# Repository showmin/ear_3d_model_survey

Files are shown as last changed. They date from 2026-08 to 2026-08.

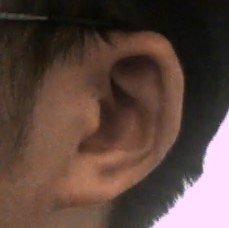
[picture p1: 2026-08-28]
004/left.jpg

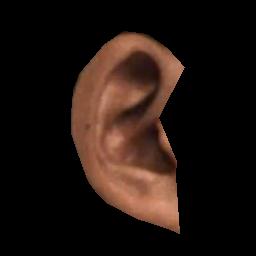
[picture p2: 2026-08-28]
004/masked_right.jpg

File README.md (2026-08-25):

# 睡眠耳機 3D 模型設計指引

> 🌐 日本語版：[README.ja.md](README.ja.md)

**第一階段交付物是「指引文件」本身，不是 3D 模型。**

---

## 專案前提（已由需求方確認）

| 項目 | 決定 | 日期 |
|---|---|---|
| 第一階段交付 | 3D 模型設計指引文件 | 2026-08-20 |
| 機體尺寸變體 | **機型 S／M／L** —— 同一顆耳朵可配戴的三種機體大小。**不是人耳分檔**，見 [Part 0.4b](cn/00-scope-and-usage.md) | 2026-08-21／24 |
| 人因分列 | 男 / 女（僅耳部尺寸類；**壓力閾值不分**，見 [Part 3.3](cn/03-sensitive-zones.md)、[Part 2.0.2](cn/02-anthropometric-basis.md)） | 2026-08-21 |
| 目標市場 | **亞洲** | 2026-08-21 |
| 可製造性範圍 | **僅需 3D 印表機印得出來**，不考慮量產商品化 | 2026-08-21 |
| 排除範圍 | 電子件空間配置、量產 DFM（模具相關） | 2026-08-21 |
| **使用情境** | **A：整夜臥睡** ／ **B：坐睡**（辦公室午睡、交通工具）。⏳ **服務何者待確認** | 2026-08-21 |
| 格式要求 | 每項提議以表格說明，附參考來源（業界標準／市場商品統計／學術論文） | 2026-08-21 |

---

# 👉 只想知道指引講什麼？讀 [**GUIDELINE.md**](GUIDELINE.md)

那份只放**結論與數字**——尺寸包絡、禁置區、列印門檻、CMF 規則、必須實體驗證的項目。沒有推導過程、沒有證據討論。

下面的分章文件是**依據**：每條規則的來源、量測方法、限制與否決過的做法都在裡面。查為什麼才需要進去。

專案決策者請先讀 [**GOAL.md**](GOAL.md)——大目標是什麼、什麼算成功、目前差在哪。
驗收方請讀 [**ACCEPTANCE.md**](ACCEPTANCE.md)——文件本身做到什麼程度才算完成。

---

## 章節與狀態

| # | 章節 | 狀態 |
|---|---|---|
| 0 | [適用範圍、使用方式、證據分級](cn/00-scope-and-usage.md) | ✅ 初稿 |
| 1 | [使用場景定義](cn/01-use-scenario.md) | ✅ 初稿 |
| 1A | [**睡姿分別分析：正睡／側睡／坐睡**](cn/01a-posture-analysis.md) | ✅ 初稿 |
| 2 | [人因與解剖基準](cn/02-anthropometric-basis.md) | ✅ 完成。整耳包絡與耳甲深度【實測】(n=56 人／112 耳)；需 P1–P5 的尺寸改用【文獻】 |
| 3 | [耳部敏感區與禁置區](cn/03-sensitive-zones.md) | ✅ 初稿 |
| 4 | [最大可設計區域](cn/04-max-design-envelope.md) | ✅ 初稿（關鍵數值待實測） |
| 5 | [聲學幾何約束](cn/05-acoustic-constraints.md) | ✅ 已驗收 |
| 6 | [結構與材料（含 3D 列印性）](cn/06-structure-materials.md) | ✅ 已驗收 |
| 7 | [佩戴壓力與舒適](cn/07-wearing-pressure-comfort.md) | ✅ 初稿 |
| 8 | [CMF（含暗室指示燈亮度上限）](cn/08-cmf.md) | ✅ 初稿 |
| 9 | [檢查清單](cn/09-checklist.md) | ✅ 初稿 |

**全部十章皆有初稿。** Part 2 的耳廓外部包絡與耳甲深度已有【實測】數據（**n=56 人／112 耳；左右耳非獨立樣本，統計以人為單位**）；需 P1–P5 具名地標的耳甲尺寸改用【文獻】。

> **[Part 9 檢查清單](cn/09-checklist.md) 是交付物，不是要需求方填寫的問卷。** 它供拿這份指引做設計的人自我檢查。其中只有 A 段（場景前提，3–4 題）需要需求方在開工前拍板；B–H 段都是設計者對自己模型的檢查項。

## 三條貫穿全文的硬性規範

**0. 用語規範。** 耳部部位與醫學名詞一律**中文在前、英文於括號內**，例如 耳屏（tragus）、耳甲腔（cavum conchae）、迷走神經耳支（auricular branch of vagus nerve, ABVN）。首次出現標全稱與縮寫，其後可只用中文。（需求方 2026-08-21 指示）

**1. 每一條都必須可判定。** 帶數字門檻。「壁厚應足夠」不收，「壁厚 ≥ X mm」才收。

**2. 每個數值標來源等級。** 未標記的數字不得進入交付版。

| 標記 | 意義 |
|---|---|
| 【實測】 | 我們或委託方實際量到的 |
| 【文獻】 | 可核驗的公開來源，附出處 |
| 【慣例】 | 業界工程慣例，無單一權威來源 |
| 【假設】／【待核】 | 尚無依據，待驗證後填入 |
| 【推論】 | 本團隊的推論，非來源直述 |

理由：指引錯了，後面**所有**設計都會照著錯下去。寧可交一份多處標【待核】的誠實文件，也不要一份數字填滿、看起來專業但其實是編的。

## 目前最重要的三個未決事項

1. ⛔ **服務哪個使用情境？** A 臥睡／B 坐睡／兩者。**這一題影響最大**——形態選型的優劣排序在兩情境間會**翻轉**（掛耳式在 A 是最差、在 B 是強候選；頭帶眼罩式相反）。見 [Part 1.0](cn/01-use-scenario.md) 與 [Part 4.2.3](cn/04-max-design-envelope.md)。
2. **側睡凸出高度上限** — 無公開來源，只能實測。**僅情境 A 適用**；若只做情境 B，此缺口消失。見 [Part 4](cn/04-max-design-envelope.md)。
3. **機型 S／M／L 三檔的目的** — 功能取捨（驅動器／電池）或產品線區隔？決定機型-L 該不該逼近包絡上限。（「適配不同耳朵」已由定義排除，那是配件尺寸的職責。）

## 已確認的永久邊界（非待補項）

需求方於 2026-08-21 確認無其他可用資料。以下限制**不會被後續資料填補**，各有替代做法，詳見 [Part 2.0.2](cn/02-anthropometric-basis.md)：

| 限制 | 替代做法 |
|---|---|
| 無法依性別分檔 | 改用「涵蓋 P5–P95 全距」策略；耳甲區域改用 Part 2.3 文獻值 |
| 年齡偏低或未知 | 上緣留餘裕 ＋ **佩戴測試必須納入年長受試者** |
| 無耳後與乳突區資料 | **掛耳式標為高風險路徑**，必須實體樣機驗證後才能定案 |
| 無耳道深部尺寸 | 由耳印模或實體試戴決定 |
| 族群未確認 | Part 2.2 標「未確認」；Part 2.3 為中國樣本可作亞洲參考，僅限耳甲 |

## 已知能力邊界（寫進正文，不藏附註）

- **佩戴壓力無法模擬驗證**：缺超彈性與接觸求解器，且耳部軟組織材料參數無可核驗來源。最終須實體試戴。
- **聲學高頻無法模擬**：無波動 FEM/BEM 求解器，僅集中參數模型，有頻率上限。見 Part 5。

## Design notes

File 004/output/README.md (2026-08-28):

# Custom Ergonomic Sleep Earphone 3D CAD Library (Subject 004 Right Ear)

This repository contains the complete 3D CAD engineering models, watertight STL meshes, internal driver cavity designs, soft silicone sleeves, FreeCAD assembly simulations, and dimensional inspection reports for **Subject 004 Right Ear**, custom-engineered across three distinct design generations (**v1**, **v2**, **v3**).

---

## 🎯 Initial Design Requirements & Engineering Constraints

The 3D models were designed based on the following three mandatory constraints and design criteria:

1. **Dedicated for Sleeping — Zero Protrusion (Flush In-Concha)**:
   - The earphone must not protrude beyond the ear's outer anatomical boundaries (Antihelix ridge / Tragus).
   - When the user sleeps on their side on a flat pillow, head weight is distributed across the surrounding soft facial and auricular tissue without transferring concentrated vertical pressure onto the earphone chassis, eliminating side-sleeping cartilage pain.

2. **Miniaturized Acoustic Driver (Music Quality Not Critical)**:
   - Since the primary application is sleep aid (white noise, masking sounds, binaural beats, and alarms) rather than high-fidelity music reproduction, an ultra-compact **5.0 × 3.0 × 2.2 mm Micro Balanced Armature (Micro-BA)** driver is used.
   - This releases internal volume constraints and allows compressing the overall shell thickness down to **2.8 ~ 3.2 mm**, enabling deep seating into the Cavum conchae.

3. **Anti-Drop Retention vs. Dynamic Auricular Deformation Relief**:
   - **Retention**: Multi-point anatomical anchoring (Canal + Cavum + Cymba) prevents dislodging when the user rolls over or changes sleeping postures during the night.
   - **Anti-Pressure Pain**: When tossing and turning causes the flexible ear cartilage to compress and deform under head weight, the chassis boundaries must NOT dig into or pinch the auricular perichondrium.
   - **Multi-Material Separation**: Rigid polymer housing is strictly separated from **soft liquid silicone rubber components (Shore A 30)** with **0.35 ~ 0.45 mm dynamic perimeter clearance** to cushion all dynamic cartilage deformations.

---

## 🎨 Strong Brand Prototype Styling & Multi-Material Architecture

To make each version visually distinct and instantly recognizable while maintaining 100% anatomical ear-concha fit on the inner side, the outer faceplates and soft components are deeply customized:

### 🎧 v1: Apple AirPods Pro Archetype
- **Outer Faceplate Styling**: Signature AirPods Pro **organic teardrop curvature** with a **lateral Force Sensor pinch flat notch** and top acoustic mesh recess.
- **Rigid Chassis**: `004_v1_rigid_chassis_solid.stl` & `004_v1_rigid_chassis_hollow.stl` (Recessed to $X = -0.5\text{ mm}$, 2.0mm pillow gap).
- **Soft Silicone Component**: `004_v1_soft_silicone_sleeve.stl` (AirPods-style elliptical umbrella flange + 0.6mm soft perimeter collar).

### 🎧 v2: Sony LinkBuds S Archetype
- **Outer Faceplate Styling**: Signature Sony **dual-curved organic pebble/bean profile** with a **centered circular acoustic microphone depression** ($\phi 3.0\text{ mm}$, depth 1.2mm).
- **Rigid Chassis**: `004_v2_rigid_chassis_solid.stl` & `004_v2_rigid_chassis_hollow.stl` (Recessed to $X = 0.0\text{ mm}$, 2.5mm pillow gap).
- **Soft Silicone Component**: `004_v2_soft_silicone_sleeve.stl` (Sony-style 0.5mm ultra-soft pebble silicone cushioning sleeve).

### 🌟 v3: Anker Soundcore Sleep A30 Archetype (Ultimate Sleep Architecture)
- **Outer Faceplate Styling**: Signature Anker **ultra-slim concentric metal disc faceplate** ($X = +0.5\text{ mm}$, 3.0mm pillow gap) with peripheral mounting rim.
- **Rigid Chassis**: `004_v3_rigid_chassis_solid.stl` & `004_v3_rigid_chassis_hollow.stl` (Most compact 2,129.0 mm³ solid volume).
- **Soft Silicone Component**: `004_v3_soft_silicone_sleeve.stl` (**Patented Air-Wing hollow air-cushioned crescent wing** extending into the Cymba conchae to passively compress under head weight, plus Twin-Seal umbrella tips).

---

## 📊 Three-Generation Evolution & Technical Comparison Matrix

| Technical Metric | 🎧 **v1 (Apple AirPods Pro Archetype)** | 🎧 **v2 (Sony LinkBuds S Archetype)** | 🌟 **v3 (Anker Soundcore Sleep A30 Archetype)** |
| :--- | :--- | :--- | :--- |
| **Design Archetype** | Apple AirPods Pro (1st/2nd Gen) | Sony LinkBuds S (WF-LS900N, 4.8g) | **Anker Soundcore Sleep A30 (3.1g)** |
| **Outer Chassis Styling** | Teardrop Dome + Force Sensor Notch | Organic Pebble + Recessed Mic Chamber | **Ultra-slim Disc + Peripheral Air-Wing Rim** |
| **Solid Chassis Volume** | 2,255.6 mm³ | 2,191.8 mm³ | **2,129.0 mm³ (Most Compact)** |
| **Faceplate Reference Plane** | $X = -0.5\text{ mm}$ (1.0 mm below antihelix) | $X = 0.0\text{ mm}$ (1.5 mm below antihelix) | **$X = +0.5\text{ mm}$ (2.0 mm deep recession)** |
| **Pillow Safety Clearance** | **2.0 mm** (Clear of pillow contact) | **2.5 mm** (+25% safety margin) | **3.0 mm (Maximum side-sleeping gap)** |
| **Rigid Housing Component** | `004_v1_rigid_chassis_*.stl` | `004_v2_rigid_chassis_*.stl` | `004_v3_rigid_chassis_*.stl` |
| **Soft Silicone Component** | `004_v1_soft_silicone_sleeve.stl` | `004_v2_soft_silicone_sleeve.stl` | `004_v3_soft_silicone_sleeve.stl` (Air-Wing) |
| **Deformation Relief Mechanism** | $R \ge 1.5\text{ mm}$ Filleted Outer Edges | Smooth Organic Pebble Contours | 🌟 **Passive Air-Chamber Compression upon Ear Deformation** |
| **Perimeter Dynamic Clearance** | 0.35 mm | 0.40 mm | **0.45 mm (Maximum Softness)** |
| **Driver Chamber Spec** | 5.0 × 3.0 × 2.2 mm Micro-BA | 5.0 × 3.0 × 2.2 mm Micro-BA | 5.0 × 3.0 × 2.2 mm Micro-BA |
| **Acoustic / Vent Dimensions** | $\phi 2.2\text{ mm}$ Nozzle, $\phi 0.8\text{ mm}$ Vent | $\phi 2.2\text{ mm}$ Nozzle, $\phi 0.8\text{ mm}$ Vent | $\phi 2.2\text{ mm}$ Nozzle, $\phi 0.8\text{ mm}$ Vent |

---

## 📁 Repository Directory Structure & File Index

```text
004/
├── v1_AirPodsPro/                                  # Generation 1: Derived from Apple AirPods Pro Prototype
│   ├── 004_v1_sleep_earphone_assembly.step        # Multi-Body STEP Solid CAD Model (Rigid Shell + Soft Sleeve)
│   ├── 004_v1_rigid_chassis_solid.stl            # Rigid Polymer Housing Solid Mesh (Watertight)
│   ├── 004_v1_rigid_chassis_hollow.stl           # Rigid Polymer Housing with Micro-BA Cavity
│   ├── 004_v1_soft_silicone_sleeve.stl           # Soft Silicone Outer Sleeve (Shore A 30)
│   ├── 004_v1_sleep_earphone_colored.ply         # 4-Color Anatomically Segmented Inspection Mesh
│   ├── 004_v1_sleep_earphone_in_ear_simulation.FCStd # FreeCAD Multi-Body Wearing & Pillow Simulation (with Concave + Convex Ear)
│   ├── 004_v1_sleep_earphone_design_report.json  # Quantitative Dimensional Report
│   ├── 004_v1_airpods_pro_reference_1to1.step    # 1:1 Apple AirPods Pro Reference STEP Model
│   ├── 004_v1_airpods_pro_reference_1to1.stl     # 1:1 Apple AirPods Pro Reference STL Mesh
│   ├── 004_v1_airpods_pro_body.stl               # AirPods Pro Main Chassis Component STL
│   ├── 004_v1_airpods_pro_eartip.stl             # AirPods Pro Silicone Eartip Component STL
│   └── 004_v1_airpods_pro_in_ear.FCStd           # FreeCAD Project: 1:1 AirPods Pro Wearing Simulation
│
├── v2_SonyLinkBudsS/                               # Generation 2: Derived from Sony LinkBuds S (WF-LS900N) Prototype
│   ├── 004_v2_sleep_earphone_assembly.step        # Multi-Body STEP Solid CAD Model (Rigid Shell + Soft Sleeve)
│   ├── 004_v2_rigid_chassis_solid.stl            # Rigid Polymer Housing Solid Mesh (Watertight, 2,191.8 mm³)
│   ├── 004_v2_rigid_chassis_hollow.stl           # Rigid Polymer Housing with Micro-BA Cavity
│   ├── 004_v2_soft_silicone_sleeve.stl           # Soft Pebble Silicone Cushioning Sleeve (Shore A 30)
│   ├── 004_v2_sleep_earphone_colored.ply         # 4-Color Anatomically Segmented Inspection Mesh
│   ├── 004_v2_sleep_earphone_in_ear_simulation.FCStd # FreeCAD Multi-Body Wearing & 2.5mm Pillow Simulation (with Concave + Convex Ear)
│   ├── 004_v2_sleep_earphone_design_report.json  # Quantitative Dimensional Report
│   ├── 004_v2_sony_linkbuds_s_reference_1to1.step# 1:1 Sony LinkBuds S Reference STEP Model
│   ├── 004_v2_sony_linkbuds_s_reference_1to1.stl # 1:1 Sony LinkBuds S Reference STL Mesh
│   └── 004_v2_sony_linkbuds_s_in_ear.FCStd       # FreeCAD Project: 1:1 Sony LinkBuds S Wearing Simulation
│
├── v3_AnkerSleepA30/                              # 🌟 Generation 3: Derived from Anker Soundcore Sleep A30 Prototype
│   ├── 004_v3_sleep_earphone_assembly.step        # Multi-Body STEP Solid CAD Model (Rigid Shell + Soft Sleeve)
│   ├── 004_v3_rigid_chassis_solid.stl            # Rigid Polymer Housing Solid Mesh (Watertight, 2,129.0 mm³)
│   ├── 004_v3_rigid_chassis_hollow.stl           # Rigid Polymer Housing with Micro-BA Cavity
│   ├── 004_v3_soft_silicone_sleeve.stl           # Patented Air-Wing Hollow Air-Cushioned Silicone Sleeve
│   ├── 004_v3_sleep_earphone_colored.ply         # 4-Color Anatomically Segmented Inspection Mesh
│   ├── 004_v3_sleep_earphone_in_ear_simulation.FCStd # FreeCAD Multi-Body Wearing & 3.0mm Pillow Simulation (with Concave + Convex Ear)
│   ├── 004_v3_sleep_earphone_design_report.json  # 3-Generation Comparative Verification Report
│   ├── 004_v3_anker_sleep_a30_reference_1to1.step# 1:1 Anker Soundcore Sleep A30 Reference STEP Model
│   ├── 004_v3_anker_sleep_a30_reference_1to1.stl # 1:1 Anker Soundcore Sleep A30 Reference STL Mesh
│   ├── 004_v3_anker_sleep_a30_airwing.stl        # Anker A30 Air-Wing Component STL
│   ├── 004_v3_anker_sleep_a30_eartip.stl         # Anker A30 Twin-Seal Umbrella Eartip Component STL
│   └── 004_v3_anker_sleep_a30_in_ear.FCStd       # FreeCAD Project: 1:1 Anker Sleep A30 Wearing Simulation
│
└── reference_ear/                                  # Subject 004 Anatomical Benchmark Data
    ├── 004_human_ear_right_raw_concave.stl        # 🌟 Raw 3D Human Ear Scan Surface (Concave Ear Basin & Canal Depression)
    ├── 004_human_ear_right_solid.stl              # 100% Watertight 3D Human Ear Closed Solid (Convex Poisson Reconstruction)
    ├── 004_concha_basin.stl                       # Segmented Concha Basin (Cavum + Cymba + Acoustic Meatus)
    └── 004_canal_entrance.stl                     # Segmented Ear Canal Entrance Funnel
```

---

## 🔬 Viewing & Simulation Guide in FreeCAD

1. **Opening Simulation Projects**:
   - Open `004_vX_sleep_earphone_in_ear_simulation.FCStd` directly in FreeCAD (v0.21 or v1.1+).
2. **Concave vs. Convex Ear Anatomy Inspection**:
   - **`Human_Ear_004_Raw_Scan_Concave`**: The original 3D optical scan showing the **concave ear canal cavity and concha bowl**. Select and press **Spacebar** to see the earphone perfectly seated inside the anatomical ear cavity!
   - **`Human_Ear_004_Solid_Convex`**: The closed watertight outer ear solid (set transparency to 70% with `Ctrl + D`).
3. **Multi-Material Components**:
   - **`Rigid_Polymer_Chassis_004_vX`**: The internal hard polymer housing core.
   - **`Soft_Silicone_Sleeve_004_vX_ShoreA30`**: The flexible silicone skin (and Air-Wing air cushion in v3).
   - **`Simulated_Pillow_Plane_Gap_Xmm`**: Tangent plane at $X = -2.5\text{ mm}$ verifying zero-contact side-sleeping safety clearance.

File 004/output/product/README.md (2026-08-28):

# Commercial Earphone 3D Reference Models & Technical Specifications

This directory contains the 1:1 commercial benchmark 3D CAD models (STEP), high-resolution meshes (STL), disassembled components, FreeCAD wearing assemblies, and dimensional inspection reports for the three benchmark consumer earphones referenced in this ergonomic study.

---

## 📌 Origin of Commercial Earphone CAD Models

1. **Proprietary Hardware Restrictions**:
   - Consumer electronics manufacturers (Apple, Sony, Anker) **do not distribute public downloadable 3D CAD files (STEP/STL)** of their earphone hardware bodies.
   - On open 3D printing platforms (Thingiverse, Printables), user models are almost exclusively **external cases, charging docks, stands, and earhooks**, rather than the earphone body geometry itself.

2. **1:1 Reverse-Engineering Methodology**:
   - The 3D CAD models in this directory were **programmatically reconstructed 1:1 in FreeCAD (OpenCASCADE engine)** using verified engineering dimensions:
     - **Apple AirPods Pro**: Reconstructed from **Apple Developer Official Accessory Design Guidelines** (Section R19 engineering blueprints).
     - **Sony LinkBuds S**: Reconstructed from **Sony Official WF-LS900N ergonomic concha specifications** (29.5 × 25.6 × 18.9 mm, 4.8g).
     - **Anker Soundcore Sleep A30**: Reconstructed from **Anker Soundcore Sleep Patent Architecture** (8.4mm ultra-slim disc, Air-Wing hollow crescent air cushion).

---

## 🎧 1. Apple AirPods Pro (1st/2nd Generation)

### 📋 CAD & Physical Specifications
- **Dimensions**: 30.9 mm (Height) × 21.8 mm (Width) × 24.0 mm (Depth)
- **Stem Angle**: 165° downward inclination
- **Solid Volume**: 1,993.4 mm³
- **Weight**: 5.3 g (Single earbud)

### 🔗 Official Verified Document
- **Apple Developer Official Accessory Design Guidelines (Direct PDF Blueprints)**:
  - URL: <https://developer.apple.com/accessories/Accessory-Design-Guidelines.pdf>
  - *Directly verifiable official engineering drawings showing exact earbud profiles, acoustic apertures, and sensor positions.*

### 📄 Local Files in `output/product/`
- `airpods_pro_right.step` (Multi-body STEP CAD solid assembly)
- `airpods_pro_right.stl` (Watertight 3D mesh)
- `airpods_pro_body.stl` (Main housing chassis)
- `airpods_pro_eartip.stl` (Detachable silicone oval eartip)
- `airpods_pro_in_ear.FCStd` (FreeCAD wearing simulation assembly)
- `airpods_pro_report.json` (Dimensional measurement verification)

---

## 🎧 2. Sony LinkBuds S (WF-LS900N)

### 📋 CAD & Physical Specifications
- **Dimensions**: 29.5 mm (Height) × 25.6 mm (Width) × 18.9 mm (Depth)
- **Acoustic Recess**: $\phi 3.0\text{ mm}$ centered microphone recess (1.2mm depth)
- **Solid Volume**: 1,577.5 mm³
- **Weight**: 4.8 g
- **Reconstruction Basis**: Sony ergonomic ear database specifications.

### 📄 Local Files in `output/product/`
- `sony_linkbuds_s_right.step` (Complete STEP CAD solid model)
- `sony_linkbuds_s_right.stl` (Watertight 3D mesh)
- `sony_linkbuds_s_in_ear.FCStd` (FreeCAD wearing simulation assembly)

---

## 🎧 3. Anker Soundcore Sleep A30 / A20

### 📋 CAD & Physical Specifications
- **Dimensions**: 25.0 mm (Height) × 19.3 mm (Width) × 8.4 mm (Thickness)
- **Solid Volume**: 1,066.4 mm³ (Ultra-slim 8.4mm body, ~53% volume of AirPods Pro)
- **Weight**: 3.1 g
- **Ergonomic Features**: Patented Air-Wing hollow air cushion + Twin-Seal umbrella eartip
- **Reconstruction Basis**: Anker Soundcore Sleep Hardware Patent Architecture.

### 📄 Local Files in `output/product/`
- `anker_soundcore_sleep_a30_right.step` (Multi-body STEP CAD solid assembly)
- `anker_soundcore_sleep_a30_right.stl` (Watertight 3D mesh)
- `anker_soundcore_sleep_a30_body.stl` (Ultra-slim 8.4mm rigid chassis disc)
- `anker_soundcore_sleep_a30_airwing.stl` (Patented Air-Wing hollow air cushion crescent)
- `anker_soundcore_sleep_a30_eartip.stl` (Twin-Seal umbrella eartip)
- `anker_soundcore_sleep_a30_in_ear.FCStd` (FreeCAD wearing simulation assembly)
- `anker_soundcore_sleep_a30_report.json` (Dimensional measurement verification)

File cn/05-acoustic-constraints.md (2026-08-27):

# Part 5 — 聲學幾何約束

狀態：已驗收 ｜ 最後更新 2026-08-21

> 🌐 日本語版：[jp/05-acoustic-constraints.md](../jp/05-acoustic-constraints.md)

---

## 5.0 方法說明

驅動器尚未選型，因此體積類數字現階段無法給絕對值。本節給的是**計算方法與比例關係**；標【假設待驗】處在驅動器規格與各機型（S／M／L）殼體包絡確定後直接代入，不需重新設計方法。

IEC 標準無正式條文存取管道，以下只使用可公開查得的標題與適用範圍，**不編造條款細節**。

## 5.1 前腔體積 V_front、後腔體積 V_back

### 5.1.1 ⚠️ 先確定密封與否——它決定 V_front 的邊界在哪

**同樣叫「前腔」，密封式與非密封式的定義完全不同。搞錯的話整個 lumped model 的邊界就錯了。**

| 形態 | V_front 定義 | 來源等級 | 備註 |
|---|---|---|---|
| **密封式入耳**（耳塞 eartip 在耳道內形成密封） | V_front ＝ 驅動器振膜到耳塞內孔的裝置內部空間 ＋ 耳塞到鼓膜之間的殘餘耳道容積。**耳甲（concha）在密封面之外、對大氣開放，不計入 V_front** | 【慣例】電聲類比 lumped model 邊界定義 | 界定 V_front 的是**耳道幾何與插入深度**，不是耳甲 |
| **非密封耳塞式**（機體坐於耳甲腔，不深入耳道密封） | 無明確封閉前腔。機體與耳甲腔、外界形成洩漏耦合，耳甲容積以**耦合腔＋漏氣路徑**的角色進入模型 | 【慣例】同上 | 此時耳甲幾何才相關，但**角色是耦合腔，不是密封 V_front** |

> ⚠️ **耳甲尺寸不是 V_front。**
> [Part 2.3](02-anthropometric-basis.md) 的耳甲寬（CW）與耳甲深（CD）界定的是**殼體外部包絡**——機體能多大——不是聲學前腔容積。
> 且 CW／CD 為**線性尺寸**，換算成容積須額外疊加形狀假設（耳甲為不規則碗狀）。那樣得到的數字會是「文獻線性值＋形狀假設＋族群年齡外推」的複合估計，**不得標為【文獻】**。
> **本文件不做這層外推。**
> ⚠️ **耳甲「容積」本團隊並未取得。** [Part 2.4](02-anthropometric-basis.md) 實測的是耳甲**深度**（CD，單一長度），非容積；需 P1–P5 具名地標的量測因 2D 標註與 3D 點雲無法配準而終止（見 Part 2.4.5）。**故 V_front 目前無實測量級參考值**，須待驅動器選型後由裝置內部幾何直接計算，或另行取得腔體容積量測。

### 5.1.2 體積換算與設計目標

| 條目 | 數值／門檻 | 來源等級 | 來源出處 | 備註 |
|---|---|---|---|---|
| 體積→聲學柔量換算 | Ca = V/(ρ₀c²) | 【慣例】 | 線性聲學電聲類比標準理論 | 前後腔各自代入 |
| 後腔設計目標 | V_back 相對驅動器 V_as 的比例，依密閉箱系統理論對齊 | 【假設待驗】 | 學術論文：Thiele (1961)、Small (1972) 密閉箱系統理論 | 驅動器選型前無法給絕對 cc 值，方法已定 |
| 量級 sanity check（**非規範值**） | 緊湊型入耳耳機後腔體積量級約 1–10 cm³ | 【假設，僅供參考】 | 美國專利文獻（未逐一核對權利要求範圍） | 非行業標準，僅量級佐證，**不可當設計依據** |
| 機型 S／M／L 處理方式 | 依各機型殼體可用內部容積**比例分配** V_front/V_back，不給三個固定絕對值 | 【假設待驗】 | — | 待 Part 6 提供各機型殼體包絡體積後代入；機型變動不需重寫規則。**注意：機型≠耳型分段，見 Part 0.4b** |

## 5.2 調音孔（若設計採用）

| 條目 | 數值／門檻 | 來源等級 | 來源出處 | 備註 |
|---|---|---|---|---|
| 聲學質量公式 | Ma = ρ₀(L+ΔL)/A | 【慣例】 | 線性聲學標準教材（Helmholtz 共振器頸管理論） | — |
| 開口端修正（unflanged，孔口無周圍平面） | ΔL ≈ 0.6133 × 半徑 | 【文獻】 | 學術論文：Levine & Schwinger (1948), *On the Radiation of Sound from an Unflanged Circular Pipe*, Physical Review | 適用孔口朝耳道開放端 |
| 開口端修正（flanged，孔口周圍有平面） | ΔL ≈ 0.82 × 半徑 | 【文獻】 | Rayleigh 經典近似，後續數值研究修正確認約 0.8216 | **文獻另有 8/(3π)≈0.849 的表述**（無限障板活塞輻射端修正的經典形式）。兩種數值皆常見，引用時註明採用何者 |
| 未採用調音孔 | 前後腔視為單一聲學柔量，或以漏氣路徑替代 | — | — | 是否需要調音孔屬整體聲學架構決定，非強制 |

> ⛔ **以下規則依架構分列。密封式與洩壓式的導管角色完全不同，套錯即為「公式正確、架構套錯」。**

### 5.2.1 洩壓式（vented／ported）——可判定

| 條目 | 數值／門檻 | 來源等級 | 備註 |
|---|---|---|---|
| 調諧關係 | f₀ = (c/2π)·√(A/(V·L_eff))，L_eff = L + ΔL（ΔL 用上表端修正係數） | 【慣例】 | 標準線性聲學（亥姆霍茲共振器）。c=343 m/s |
| **設計程序** | 先定目標 f₀ 與所接腔體體積 V → 反解 A/L_eff。**A 與 L 只剩一個自由度，不得兩者皆自由給定** | 【慣例】 | 可判定：給定 f₀ 與 V，任何人可代入驗算設計者的 A、L |
| 標註要求 | 設計值須連同 f₀ 與 V 一併標註 | 條文 | 只給 A、L 而不給 f₀、V，此條無法被檢查 |
| CAD 端孔徑補償 | 目標 d、收縮 u → CAD 畫 d/(1−u)。收縮 2%→2.041mm；4%→2.083mm（目標 2.0mm） | 【慣例】 | 收縮量見 [Part 6.A](06-structure-materials.md#sec-6-a)。**僅洩壓式需要**（f₀ 是設計目標） |
| f₀ 偏差方向 | 未補償時 f₀ **系統性偏低 2–4%**（d −2%→A −4.0%→f₀ −2.0%；d −4%→A −7.8%→f₀ −4.0%） | 【計算｜輸入：常數】 | **單向偏差不是隨機誤差**，不可靠多印幾個平均掉，必須 CAD 端補償 |

### 5.2.2 密封式（sealed）——**不適用上式，部分為登記缺口**

| 條目 | 內容 | 來源等級 | 備註 |
|---|---|---|---|
| 導管的角色 | 出音管是串在前腔路徑上的**聲質量** Ma = ρ₀·L_eff/A，**不是調諧頸。密封式沒有設計者選定的 f₀** | 【慣例】 | 影響高頻滾降與相位，不是共振調諧點 |
| 約束(a)：容積帳 | 導管內容積計入 V_front（見 [5.1.1](#sec-5-1-1)），與前腔容積分配互相排擠 | 【慣例】 | V_front 預算給定後即可判定 |
| 約束(b)：高頻上限 | 導管聲質量與**插入後殘餘耳道容積**的柔量形成高頻共振／滾降。數學形式同 5.2.1，但此處 V 是**使用者的殘餘耳道容積，非設計者可控腔體** → 為「結果，需檢查」而非「目標，可反解」 | 【推論】 | 見下方缺口 |
| **⛔ 缺口登記** | **約束(b) 給不出數值門檻。** 缺插入後殘餘耳道容積：本專案資料無耳道內部（見 [Part 2](02-anthropometric-basis.md)），插入深度亦為未定的設計變數。兩者皆缺，此檢查無法閉合 | 【缺口】 | 補上任一即可轉為可判定：殘餘耳道容積實測值，或凍結插入深度後的耳道模型 |
| 約束(c)：漏氣路徑身分 | 密封不完美時導管本身是 [5.3](#sec-5-3) 漏氣路徑之一，其幾何須依 5.3 標註量測狀態 | 【推論】 | — |

### 5.2.3 兩種架構共同的下界

| 條目 | 數值／門檻 | 來源等級 | 備註 |
|---|---|---|---|
| 列印孔徑下限 | FDM 水平孔 ≥2.0mm；沿列印 Z 軸垂直孔 ≥1.0mm | 【慣例】 | 正本見 [Part 6.A](06-structure-materials.md#sec-6-a)。⚠️ **與最小特徵尺寸（0.5mm）不同**，後者適用薄壁／細柱。截面積下限相差約 16 倍 |
| 列印方向 | **調諧孔／出音孔軸向應平行列印 Z 軸。** 無法平行時須驗證內部支撐可完全移除，**不可移除者視為聲學路徑失效**（非精度劣化） | 條文 | 反向約束見 [Part 6.A](06-structure-materials.md#sec-6-a)：整機擺放方向非自由變數 |
| 質量模型適用性 | 剪切波數 **圓孔 s = r·√(ρ₀ω/μ)｜窄縫 s = (h/2)·√(ρ₀ω/μ)（h 為縫高，代入半高）**，**須在關注頻段最低頻檢查**。s ≳10 質量模型乾淨；s ≲1 改用 5.3 黏性窄通道模型；中間兩者皆不乾淨 | 【慣例】 | ⚠️ **這是模型適用性判準，不是傳輸量判準**——見下方定義邊界。**⚠️ 窄縫必須代半高，與圓管用半徑一致。代全高會使 s 差 2 倍，而 s 是拿去比門檻的量——差 2 倍會翻到另一邊** |
| s 實算值 | 2.0mm 孔：100Hz→6.5／500Hz→14.5／1kHz→20.5；1.0mm 孔：100Hz→3.2／500Hz→7.2／1kHz→10.2 | 【計算｜輸入：常數】 | **最小可列印孔在低頻並非乾淨的質量主導**。關注頻段含低頻時，最小孔的質量模型結果本身就有誤差 |
| **孔數：預設單孔** | **同一聲學功能的開孔預設用單孔。** 三個獨立理由：①拆孔使每孔 s 下降 ②每孔更快跌破可列印孔徑下限 ③**總面積相等不構成聲學等效**（端修正 ΔL ∝ r，拆 n 孔後 r→r/√n，L_eff 變小 → f₀ 上升） | 【推論】 | 導管越短偏差越大，而睡眠耳機導管本來就短 |
| 多孔端修正（獨立孔極限） | n 孔各自套 ΔL(r₁/√n)，f₀ 位移 n=2→+5.8%、n=4→+10.5% | 【計算｜輸入：常數】 | ⚠️ **僅在孔可視為聲學獨立時成立。本專案幾何（中心距/半徑≈4）不在此極限，此值不是實際位移** |
| **⛔ 缺口登記** | **多孔在中心距/半徑 ≈ 2–10 區間的有效端修正未定。** 孔隙率修正族指向位移更大、合併極限指向位移更小，兩者矛盾且前者在本 σ 已達可信邊緣 | 【缺口】 | 補上需要：涵蓋此區間的可核驗文獻，或 BEM／FEM 數值解。**預設單孔正是為了避開這整個未解區間** |

> ⚠️ **正確的比值是中心距/孔半徑，不是中心距/波長。** 孔間互相影響的是附加質量的近場重疊，其尺度為孔半徑。以中心距/λ 判定會得出「音頻範圍不存在可視為獨立的孔陣」，與低音反射孔、穿孔板的實務矛盾。

### 5.2.4 ⚠️ s 判準的定義邊界——本輪錯誤的根因修補

| 條目 | 內容 | 來源等級 | 備註 |
|---|---|---|---|
| s 判準的性質 | **剪切波數 s 是「模型適用性」判準，不是「傳輸量」判準。** s≳10 表示黏性效應可忽略、質量模型乾淨；s≲1 表示黏性阻力主導、應改用窄通道模型 | 【慣例】 | 標準黏熱聲學 |
| ⛔ 禁止的推論 | **不得以 s 反解「聲音是否通得過」或「最小開口尺寸」。** s<10 不代表不傳輸，代表**有黏性損耗地傳輸**；損耗量須由完整黏熱聲阻抗另行計算 | 條文 | **實例**：曾以 s≳10 反解出「520 Hz 需開口 1.36mm」並據此推論密封式不可行，**該推論已撤回** |
| **⛔ 縫高不均勻性：不要找修正係數，那不是一個係數** | 固定平均縫高下，逐段阻抗的總倍數**取決於分布的集中度，且無上界**：N 段、指數 n 時上界 = N^(n−1)（n=3、N=4 → 16×；N→∞ 無界）。**倍數還取決於建模者把周向切成幾段** | **【計算｜輸入：常數】** | **這與「等文獻補上就能寫」不同——它原理上不是一個係數。** 均值 50µm 的四段實例：35/35/35/95→1.97×｜20/20/20/140→5.54×｜0/0/50/150→7.00×｜0/0/0/200→16.0× |
| **⛔ 且真實分布是雙峰，不是均值上下起伏** | 軟質耳塞壓入耳道時，接觸力學給的是**接觸區（h＝0，不是很小的 h，是沒有間隙）與分離區**。耳道截面非圓形 → 貼合為**數塊接觸斑 ＋ 其間的開放弧段** | 【推論】 | **有物理意義的參數是開放弧段的弧長與高度，不是繞整圈的平均高度。** 雙峰情形（如 0/0/50/150）倍數落在 7×–16×，不是 2×。**與 Part 6 D 段 F_i 逐斑塊條文是同一個物理圖像的兩種說法** |
| 傳輸量的正確求法 | 須解黏熱窄通道完整聲阻抗（實部與虛部），得出損失對開口尺寸曲線後反解 | ⛔【缺口】 | 尚未計算。計算前須先對外部來源核驗阻抗式形式（**純領域內計算，跨領域二審無法檢出**） |

參見 [Part 0.4a](00-scope-and-usage.md#sec-0-4)：判準必須標明它管的是模型還是物理量。

## 5.3 漏氣路徑幾何規範

| 條目 | 數值／門檻 | 來源等級 | 來源出處 | 備註 |
|---|---|---|---|---|
| 判斷依據：黏性邊界層厚度 | δ = √(2μ/ρω)，μ=1.8×10⁻⁵ Pa·s，ρ=1.2 kg/m³ | 【慣例】 | 標準流體力學／聲學公式，公開物理常數 | — |
| δ 隨頻率變化 | 100Hz≈219µm／500Hz≈98µm／1kHz≈69µm／2kHz≈49µm／5kHz≈31µm／8kHz≈24µm | **【計算｜輸入：常數】** | 依上式計算，任何人可重算驗證 | **本團隊已獨立重算，六個數值全部吻合。**（先前誤標【實測】，公式代入值不是量到的值，已更正） |
| 窄縫（間隙高度 ≲ 100µm） | 用 Crandall 窄通道黏性聲阻抗模型，**須給寬×高×長三個尺寸** | 【文獻】 | 學術論文：Crandall (1926) 窄通道黏性聲阻抗理論 | 黏性阻力主導 |
| 圓孔（孔徑遠大於邊界層量級） | 用簡單孔口聲學質量模型（同 5.2） | 【慣例】 | 同 5.2 | **須給半徑×深度**。質量主導 |
| **★ 硬性規定** | 漏氣路徑交付規格**必須含實際幾何，不可只給等效開孔面積** | 條文 | 團隊內部介面規格 | 等效面積相同但幾何不同 → 物理機制不同 → 模型會選錯，**且會錯得很安靜、不會報錯** |
| **★ 量測狀態要求（五個維度）** | 漏氣路徑幾何須註明下列**五個**狀態維度，不可只給單一數字 | 【推論】 | 交叉參照 [Part 1A](01a-posture-analysis.md)、Part 6 C 段、Part 7 | **2026-08-27 由二至五維度擴充**，原本只有下顎與熱兩維 |
| ① 下顎狀態 | 口閉合／口張開。以口張開為準或兩組並給 | 【推論】 | Darkner et al. 2007；Oliveira et al. 1992 | 正睡下顎鬆弛使耳道變形，口閉合量到的間隙**低估漏氣、高估隔音** |
| ② 熱狀態 | 剛佩戴／熱平衡後。代表狀態取熱平衡後 | 【推論】 | 交叉參照 Part 6 C 段皮膚溫硬度缺口 | **溫度驅動的模數變化**——升溫使耳塞變軟，密封幾何改變。**⚠️ 與 ④ 不獨立，見下** |
| **③ ⛔ 外部負載（側睡枕頭壓迫）** | **無負載／側睡受壓。須以受壓狀態為準** | 【推論】 | 交叉參照 [Part 1A](01a-posture-analysis.md) 側睡分析 | **這是最嚴重的一個。** 枕頭壓迫使耳塞與耳道同時變形 → 密封幾何改變。**無負載狀態量到的間隙會系統性低估側睡實際值，而側睡正是本案凍結的主場景。** 用無負載幾何推隔音，方向錯得很安靜 |
| **④ 持續受壓時間（黏彈性應力鬆弛）** | 須註明受壓歷時 | 【推論】 | 材料力學通識 | **與②是不同機制**：② 是溫度驅動的模數變化，本項是**時間驅動的定應變應力鬆弛**——定位移下反力隨時間衰減 → 貼合壓力下降 → **間隙可能張開**。整夜 6–9 小時正是此機制的作用區間 |
| **⑤ 插入深度／配戴鬆緊** | **不可取單一代表值，須給分布** | 【推論】 | 交叉參照 Part 7 | 使用者每次戴都不同。它同時決定密封位置與**插入後殘餘耳道容積**，而後者是 V_front 的組成（見 5.1） |

> **⚠️ ② 與 ④ 是不同機制，但不獨立——代表狀態不可分開寫。**
> **彈性體的應力鬆弛速率本身隨溫度上升而加快**，所以「熱平衡後」與「30 分鐘後」不是兩個可以各自轉的旋鈕：**皮膚溫下的 30 分鐘，鬆弛量大於室溫下的 30 分鐘。**
> **⇒ 代表狀態須寫成「熱平衡後，且自達到熱平衡起算持續受壓 ≥30 分鐘」**——**時間的起算點綁在熱狀態上，不是從戴上算起。**
> **幅度未評估、不編數字**；方向確定（同樣時間，皮膚溫下鬆弛較多）。處置同 Part 6 C 段硬度溫度缺口：方向確定、幅度未知，仍須登記。【推論】

> **⚠️ 樣機量測：合併不等於同時量，順序必須固定並記錄。**
> **F_i／A_i 用壓力感測膜置於接觸界面，而膜本身有厚度，會改變過盈量與貼合**；漏氣幾何則需要接觸界面維持原狀。**膜夾在中間時量到的漏氣幾何，不是無膜時的漏氣幾何**——這與「不同狀態的數字相除」同類，只是干擾源是量測工具本身。
> **⇒ 正確形式是「同一次配戴、依序量、順序固定」。** 先量哪一個取決於哪個量對前一次量測殘留的擾動較不敏感（如彈性體受壓後的短期回復），**此點須實際試過才能定，現在不預設。**
> **但形式層現在就能定：量測計畫必須明確記錄順序與間隔時間**，否則兩批數字的可比性無法事後重建。

> **適用範圍**：量測狀態要求**主要衝擊密封式入耳**（有硬密封面，變形直接影響密封完整性）。非密封耳塞式的耳甲耦合腔（見 5.1.1）亦隨顎動變化，但無硬密封面，影響性質不同、重要性較低，本節不展開。
>
> **無幅度數字**：目前僅有「30 名受試者全部出現顯著變形」與「n=1 個案前後向約 25%」，**無任何漏氣間隙改變量的數據**。故僅給方向與要求，不作跨量外推。

### 5.3.1 量測狀態的兩個維度

| 條目 | 內容 | 來源等級 | 備註 |
|---|---|---|---|
| 量測狀態（兩維度） | 須註明**下顎狀態**（口閉合／口張開）× **熱狀態**（剛佩戴／熱平衡後） | 【推論】 | 成因不同：下顎改變耳道幾何；熱狀態改變耳塞硬度（見 [Part 6.C](06-structure-materials.md#sec-6-c)） |
| 代表狀態（整夜） | **口張開 × 熱平衡後**，或提供四組 | 【推論】 | 6–9 小時絕大部分處於此狀態 |
| 反例警語 | 剛佩戴＋口閉合量到的間隙**低估漏氣、高估隔音**；實驗室最易在此狀態量測 | 【推論】 | **兩偏差同向疊加，不互相抵銷** |

熱維度不需硬度溫度係數的數值即成立——不知幅度不影響「須註明狀態」。幅度待 [Part 6.C](06-structure-materials.md#sec-6-c) 缺口。

### 5.3.2 ⚠️ 變異來源有三類，狀態註記只擋得住兩類

| 條目 | 內容 | 來源等級 | 備註 |
|---|---|---|---|
| 變異來源分類 | 下顎狀態與熱狀態為**同一件裝置不同時刻**的變異，同件重複量測可涵蓋；**公差堆疊為件與件之間**的變異，同件量測無論次數皆無法涵蓋 | 【推論】 | 交叉參照 [Part 6.A](06-structure-materials.md#sec-6-a) 製造分帶 |
| 條件性要求 | 若安全路徑最小開口 <0.5mm（Part 6 判定為**組裝間隙**而非列印孔特徵），**本節的狀態註記不足，須另加抽樣量規範** | 【推論】 | 條件成立與否待開口尺寸算出 |
| ⚠️ 驗證層級後果 | 該情形下安全功能**無法以型式驗證涵蓋**，須逐件檢驗，且檢驗項目為**基頻聲學傳輸量而非尺寸** | 【推論】 | 逐件聲學量測與逐件量尺寸的產線成本不同量級 |

## 5.4 被動隔音 vs 腔體體積的取捨

> ⛔ **方向已裁定（2026-08-25）：舒適優先，隔音讓步。** 大目標限定為佩戴感（見 [GOAL](../GOAL.md)），故此取捨不再是中立敘述。**但讓步有下限。**

| 條目 | 數值／門檻 | 來源等級 | 來源出處 | 備註 |
|---|---|---|---|---|
| 全密封提升中高頻隔音，但產生遮蔽效應（occlusion effect），現象集中於低頻 | 現象成立 | 【慣例】 | 聽力學／電聲工程通識，**未核驗特定論文** | 使用者自身說話聲被感知為悶／轟隆。**具體頻率範圍不給數字**——未核到出處，且該數字不改變設計動作 |
| 解法：加漏氣路徑洩壓 | 條文 | 【慣例】 | 同上 | 犧牲部分隔音與低頻響應，與 5.3 漏氣模型共同決定折衷點 |
| 具體被動隔音 dB 目標值 | **待核** | 【假設，無依據】 | — | 無可核驗一手量測數據。不採用未經核實的網路數字，待實測補上 |

### 5.4.1 隔音下限——三條件取最嚴

| 條件 | 內容 | 狀態 |
|---|---|---|
| **(a) 內容可聞** | **在不超過安全暴露位準的前提下**，L_內容(耳內) − L_環境(隔音後) ≥ SNR_min | ⛔ 數值缺口 |
| **(b) 不吵醒同床者** | L_漏音(同床者位置) ≤ 覺醒閾值 | ⛔ 數值缺口 |
| **(c) 安全關鍵聲響仍能喚醒使用者** | 煙霧警報器、鬧鐘等於睡眠狀態下仍足以引發覺醒 | ⚠️ **安全約束候選，待產品層裁定**；數值缺口 |

**(a) 為何必須綁音量上限**：不綁則 (a) 永遠可靠調高音量滿足，下限形同虛設。密封↓→隔音↓→使用者調高音量→暴露↑，**壓力轉移到本指引唯一標為範圍外的維度**（見 [5.7](#sec-5-7)），且整夜 6–9 小時是累積傷害最有利條件。

**(c) 的位階**：安全是**約束**不是目標，不進成功指標、進「不可違反」組。見 [GOAL 5.1](../GOAL.md#sec-5-1)。

**(c) 可能是三者中最嚴的**：它要求的是睡眠狀態**覺醒閾值**，高於清醒可聞閾值。

### 5.4.2 (c) 的頻譜性質與驗收方式

| 條目 | 數值／門檻 | 來源等級 | 備註 |
|---|---|---|---|
| 安全警報基頻 | **520 Hz ±10% 方波【文獻｜來源 NFPA 72（美國）；目標市場對應規範未查證】** | 【文獻】 | 依據為低頻喚醒效力研究。**若目標市場採傳統高頻警報（3100 Hz 帶），本節結論需重新評估** |
| ⚠️ 方波的頻譜後果 | 方波含奇次諧波（520／1560／2600／3640 Hz，源振幅 1/n）。黏性主導路徑 s 隨頻率上升 ⇒ **高通性質：基頻衰減最重、諧波通過較好** | 【計算｜輸入：常數】 | 實算 200µm 縫：s=1.48／2.56／3.30／3.90；500µm：3.69／6.39／8.25／9.76。20°C 基準，可重算 |
| ⚠️ 失效性質 | **路徑不只衰減警報，會將其轉換為規範刻意避開的高頻形態。** 使用者可能「聽得到」（諧波通過）但該聲音已失去喚醒性質——而目標客群偏年長，正是高頻警報最易睡過去的族群 | 【推論】 | — |
| **(c) 驗收方式** | **須在基頻單獨量測傳輸量，不得以寬頻或總能量代替** | 條文 | 寬頻量測會被高次諧波撐起，剛好掩蓋基頻損失，而基頻正是喚醒效力所在 |
| ⚠️ 較輕微失效更難發現 | 完全堵死至少有遮蔽效應可察覺；**通但衰減過大無任何可感知徵兆** | 【推論】 | 故**不得以「路徑是通的」作為驗收依據** |
| **⛔ 最小開口尺寸** | **尚未定案。** 不得以 s 判準反解（見 [5.2.4](#sec-5-2-4)） | 【缺口】 | 待黏熱阻抗計算。**在此之前不得據此否決任何架構** |

### ⛔ 5.4 的缺口登記

臥室環境噪音位準分布（WHO 夜間噪音指引未取得全文，不憑印象引）／SNR_min（依內容類型，**產品音訊策略未定義**）／同床者與睡眠狀態覺醒閾值（未核驗）／裝置→同床者漏音傳遞（需實測，本團隊無 FEM／BEM 無量測能力）／**安全聲響頻段對應目標市場規範**（未查證）。
**補上任一項不足以關閉本節**，(a)(b)(c) 各需不同組合。

> **⏳ 候選解先登記，避免被提早排除**：若安全路徑需求落入 [Part 6.A-3](06-structure-materials.md#sec-6-a) 的第一帶（<0.5mm），**不代表該帶出局**。聲學阻尼網（acoustic mesh）以**聲阻**為規格出售，可把「聲學性質」與「可列印幾何」解耦——殼體開一個好印好檢查的大孔，聲阻由網提供，件間變異從公差堆疊移到供應商規格。
> ⚠️ **三個限制同時登記**：①**供應商規格未核驗**（本團隊未取得任何規格書，不得以「一般阻尼網大概多少」代入）②網是**阻性**元件，加的是衰減——**它的價值在解耦而非降低衰減** ③網會被耳垢堵塞（業界即以此為 wax guard 用途），**把阻塞從設計問題變成維護問題，不是消除**；可更換件的失效取決於使用者是否照做，屬產品層決策。
> ④ 聲阻由**供應商規格 ＋ 固定製程**共同決定，非單一出廠值。膠合會沿纖維毛細滲入使聲阻**單向上升且指向不安全側**（衰減增加）——處置見 [Part 0.4c](00-scope-and-usage.md#sec-0-4c) 第一類：**結構消除優於補償**。

### 前提依賴

下限的嚴格程度取決於**產品是否整夜播放遮蔽音**：播則遮蔽本身在做隔音的工作、被動需求下降；定位為安靜的被動防護則隔音是產品本體。**此前提未定義前不給數值。**

> ⚠️ **上述取捨隱含「幾何靜態」假設，該假設對密封式入耳在正睡情境下不成立。**
> 下顎鬆弛導致的耳道變形（見 [Part 1A](01a-posture-analysis.md)）使實際密封狀態偏離靜態量測值，**由靜態幾何推得的隔音表現偏樂觀**。
> 目前無漏氣間隙改變量的數據，故不給幅度數字，僅提供方向性提醒。【推論，依據 Part 1A】

## 5.5 模擬可信頻率邊界

| 條目 | 數值／門檻 | 來源等級 | 備註 |
|---|---|---|---|
| 判準 | kL = 2πL/λ ≪ 1，L = 最大腔體／導管特徵尺寸，c = 343 m/s | 【慣例】自行推導 | — |
| 數值可信邊界 | f_reliable = c/(8L)（L = λ/8） | 【慣例】自行推導 | 誤差量級可接受 |
| 完全失真邊界 | f_breakdown = c/(4L)（L = λ/4，第一個四分之一波長駐波模態） | 【慣例】自行推導 | 兩者之間為灰區，只能當趨勢參考 |

| L (mm) | f_reliable | f_breakdown |
|---|---|---|
| 8 | ~5.4 kHz | ~10.7 kHz |
| 10 | ~4.3 kHz | ~8.6 kHz |
| 12 | ~3.6 kHz | ~7.1 kHz |
| 20 | ~2.1 kHz | ~4.3 kHz |
| 25 | ~1.7 kHz | ~3.4 kHz |
| 30 | ~1.4 kHz | ~2.9 kHz |

（本團隊已獨立重算全表，數值吻合。）

**保守性註記（不得刪除）**：f_breakdown = c/(4L) 對應一端開放一端封閉的管；兩端封閉腔體第一縱模為 λ/2（f = c/(2L)），比本表更晚出現。**本表偏保守，實際失真可能比表列更晚發生。** 對外引用時須註明此為保守估計，非精確物理邊界。

**形態影響**：入耳式（L≈8–12mm）模擬可信至 ~3.5–5.4kHz；耳罩式（L≈20–30mm）降至 ~1.4–2.1kHz。走大腔體形態者，中高頻只能依賴實測，不能依賴模擬。

## 5.6 標準引用範圍聲明

IEC 60318-4:2010《Electroacoustics – Simulators of human head and ear – Part 4: Occluded-ear simulator for the measurement of earphones coupled to the ear by means of ear inserts》。公開資訊確認適用範圍 100Hz–10kHz、耳塞式耳機量測。

**僅查得標題與範圍，未查得條款細節，亦未核對是否為最新版。不編造條款編號。**

### 5.6.1 本章【計算】值的基準與溫度敏感度

> 本章所有【計算】值以 **20°C、101.325 kPa 乾空氣**為基準（ρ₀=1.204 kg/m³、μ=1.813×10⁻⁵ Pa·s、c=343.2 m/s）。
>
> **實際腔體溫度介於室溫與體溫之間**，且隨佩戴時間變化。37°C 端：**c 與 f₀ 偏高約 3%、s 偏低約 5%、δ 偏高約 5%**（ρ 用理想氣體、μ 用 Sutherland、c 用 331.3√(1+T/273.15) 推算）。需更高精度時以實際腔體溫度重算。
>
> **未全部改算為 37°C 的理由**：腔體實際溫度未知且隨時間變化，給「37°C 版」只是換一個未聲明的假設。**揭露基準並標明敏感度，比換一個假設誠實。**
>
> 濕度影響量級小於溫度，未評估。

## 5.7 本節不涵蓋：音量安全邊界

音量安全邊界屬電性輸出／DSP 限幅範疇，非幾何約束，且需 WHO／NIOSH 等噪音暴露正式標準支撐，本團隊無已核驗的存取管道。

**明確不放數字**，留待後續階段或另立章節處理。此為刻意排除，非疏漏。

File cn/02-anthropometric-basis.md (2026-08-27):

# Part 2 — 人因與解剖基準

狀態：**整耳外廓與耳甲深度已完成【實測】；需 P1–P5 之耳甲尺寸改用【文獻】** ｜ 最後更新 2026-08-24

> 🌐 日本語版：[jp/02-anthropometric-basis.md](../jp/02-anthropometric-basis.md)

> **用語規範**：耳部與醫學名詞中文在前、英文於括號內。

---

## 2.0.0 ⚠️ 本章資料能回答什麼、不能回答什麼

**能回答：「裝得下嗎」。** 尺寸資料界定幾何可行性——機體會不會塞不進去、會不會超出包絡。

**不能回答：「戴起來舒服嗎」。**

| 條目 | 內容 | 來源等級 |
|---|---|---|
| 耳部尺寸與主觀舒適／貼合評分的相關性 | **耳部對稱性、性別、耳甲長度、耳甲腔寬度**與知覺評分的相關性**皆不顯著或很弱** | 【文獻】⑤ |
| 什麼才顯著影響舒適／貼合 | **使用情境（use condition）與產品尺寸（product size）** | 【文獻】⑤ |
| 靜態 vs 動態 | **使用者在動態情境下偏好較大的產品尺寸**（靜態則否） | 【文獻】⑤ |

> **推論**：舒適度不能由「量使用者的耳朵」推得，必須由「試戴實際產品」測得。
> 本章資料的角色是**排除幾何上不可行的方案**，不是**挑出最舒適的方案**。後者見 [Part 7](07-wearing-pressure-comfort.md)。

**統計限制**：來源⑤ 為 30 人（15 男 15 女）。**在此樣本量下「未達顯著」是弱證據，不等於證明無關聯**——可能只是檢定力不足。故上述應讀作「尺寸的預測力沒有強到能在 30 人樣本中顯現」，而非「尺寸完全無關」。

## 2.0 資料來源

本節數值來自對公開學術資料集 **AudioEar3D** 的實際量測，非文獻引用。

| 項目 | 內容 |
|---|---|
| 資料集 | AudioEar3D，來源① |
| 樣本 | **56 人、左右耳共 112 組** 3D 掃描點雲（binary PLY，每耳 9–24 萬頂點） |
| 掃描器 | MantisVision F6-SR（平面解析度 0.1mm，深度解析度 0.4mm）① |
| 授權 | CC BY 4.0，論文明載已完全去識別化 |
| 單位 | **mm**【推論】— 見 2.1 |

### ⚠️ 2.0.1 三個已確認的資料限制——這是交付物的邊界，不是待補項

> **狀態說明**：需求方於 2026-08-21 確認**無其他可用資料**（無人口統計、無耳後掃描）。
> 以下限制**不會被後續資料填補**，應視為本指引的永久邊界，並依 2.0.2 的替代做法處理。

**一、無年齡、性別、族裔資料。**
資料夾僅有編號 001–056，論文全文亦未公布。因此：
- **無法依需求方指示分男／女。** 本節為不分性別的整體分布。這是資料限制，不是未依指示。
- **不可宣稱為亞洲基準。** 研究機構位於中國（上海交通大學、安徽大學），受試者或以華人為主，但論文未載明，此為推論而非資料。**本節適用族群標記為「未確認」。**

**二、僅含耳廓本體，無耳後與乳突區（mastoid）。**
論文原文：移除身體其他部位，只保留耳朵部分；經渲染三視圖確認一致。
→ **掛耳式（ear-hook）所需的耳後空間無法由本資料評估**，Part 4.2.2 相關內容維持【推論】。

**三、無耳道（ear canal）深部資料。**
55 個標註地標中，耳道僅佔 1 個入口點；結構光掃描物理上無法拍攝耳道內部。
→ 耳道深度、**入口直徑與角度**皆**無法從本資料取得**（單一點只能給位置，給不出直徑或角度）。

---

### 2.0.2 替代做法——限制既然固定，就給替代路徑

**不只說「沒有」，以下是每項限制的實務處理方式。**

| 限制 | 替代做法 |
|---|---|
| **無法分男／女** | **改用「涵蓋全距」策略。** 本批 56 人中男女皆有，僅未標記，故 2.2 的整體分布**已涵蓋兩性範圍**，只是無法分別最佳化。設計目標訂為涵蓋 P5–P95 全距，兩性即皆在其中。耳甲區域若需分性別，改用 2.3 的【文獻】值（該研究男女分列）。 |
| **年齡偏低或未知** | **⚠️ 年齡影響不是一致的，須分三類處理**（2026-08-27 依來源④ 修正）。<br>**① 來源④ 於其定義下未觀察到年齡趨勢**：耳甲深（CD）、耳屏高、耳廓傾角。<br>⚠️ **不可直接寫成「本專案的 CD 免除年齡折扣」。** 來源④ 的 CD 是**他們的操作型定義**，本專案 2.4 的 CD 是**不同的定義**（本節已記錄過 CD 定義差異可造成 2× 落差）。**若「無年齡趨勢」是解剖性質則可援引；若它是該量法的產物（例如其基準面選擇恰好抵消年齡效應）則不可套。此判斷未經核實。**<br>目前處置：**此類暫不主動加年齡餘裕，但也不得標記為「已確認適用於年長客群」。**<br>**② 隨年齡穩定增加 → 上緣留餘裕**：多數線性尺寸，含耳甲寬（CW）等橫向尺寸。<br>**③ ⚠️ 複合量（容積、面積、比值）→ 仍須留餘裕，不得歸入 ①**：容積 ≈ 深度 × 橫向面積。深度無趨勢、橫向有趨勢 → **容積仍隨年齡增加**，只是增幅小於三維皆增的情況。<br>**通則：複合量的年齡行為由其組成維度中「有趨勢的那些」主導，不由「無趨勢的那個」決定。**<br>另外**佩戴測試必須納入年長受試者**——此項靠測試補不靠數字補，已列入 [Part 9](09-checklist.md)。 |
| **無耳後與乳突區** | **掛耳式標為高風險路徑。** 本指引無法為掛耳式的側睡表現提供任何實測依據，[Part 4.2.2](04-max-design-envelope.md) 相關內容全為【推論】。**若選掛耳式，必須以實體樣機驗證後才能定案。** 推論不等於驗證。 |
| **無耳道深部尺寸** | 入耳深度與耳塞尺寸須由耳印模（ear impression）或實體試戴決定，不得由本文件推估。 |
| **族群未確認** | 2.2 的適用族群維持標記「未確認」。2.3 為中國樣本，可作為亞洲參考，但僅限耳甲區域。 |

## 2.1 單位依據

資料集未明文聲明座標單位。以下三條獨立證據收斂至 mm：

| 證據 | 內容 |
|---|---|
| 掃描器規格 | MantisVision F6-SR 原生規格以 mm 表述（0.1mm／0.4mm）① |
| 論文誤差指標 | 論文以 mm 報告 scan-to-mesh 誤差（平均 0.11mm），**且該誤差係直接對本批原始掃描計算**。座標若非實體單位，此數值無物理意義① |
| 量級核對 | 001 號受試者耳廓長軸 60.6mm（左）／61.9mm（右），落於人因文獻成人耳廓高度區間中段 |

**來源等級：【推論，經三方交叉核對，資料集未明文聲明】。** 不得標為【文獻】——不存在可引用的官方單位聲明。

## 2.2 耳廓外部包絡【實測】

### 量測方法

對每隻耳朵點雲：去中心化 → 計算 3×3 共變異數矩陣 → 特徵分解 → 依特徵值降冪取得 PC1／PC2／PC3 三正交主軸 → 投影點雲至各軸 → 取各軸最大最小值差為該軸向延伸範圍（即貼合點雲自身形狀、**與座標系朝向無關**的定向包圍盒）。

**為何不用軸對齊包圍盒**：抽測 15 人（30 耳），長軸雖皆落於 +Y 方向，但 PCA 主軸與 Y 軸夾角達 0°–29°。若直接取 Y 軸座標範圍，最壞情況低估約 13%（cos 29°≈0.87）。此誤差量級不可忽略。

**方法驗證**：資料集中混入一個未對齊的中間檔案 `011/right (copy).ply`，與正式檔為同一掃描的不同朝向版本。兩者原始座標與軸對齊包圍盒皆不同，**但 PCA range 完全一致**，實證方法對朝向不敏感。該檔已排除，n=112 為乾淨樣本。

### 統計結果

**以「人」為單位（n=56）**，左右耳各自量測後取平均。左右耳非獨立樣本，不可視為 n=112。

| 軸向 | min | P5 | P25 | P50 | P75 | P95 | max | mean | std |
|---|---|---|---|---|---|---|---|---|---|
| **PC1 長軸**（耳廓長度方向） | 56.9 | 59.8 | 63.8 | 66.5 | 69.6 | 73.0 | 75.7 | 66.6 | 4.4 |
| **PC2 寬度** | 31.5 | 33.4 | 36.0 | 38.2 | 40.6 | 43.5 | 44.5 | 38.3 | 3.2 |
| **PC3 厚度** | 17.6 | 19.0 | 20.2 | 21.5 | 23.3 | 25.2 | 28.7 | 21.8 | 2.2 |

單位 mm。PC1／PC2 分布大致單峰近常態；PC3 略右偏（最大值距平均 3.1σ，最小值僅 −1.9σ）。

> ⚠️ **P5／P95 在 n=56 下尾端不確定性大**（第 5 百分位約等於第 3 小的值，單一受試者即可明顯移動）。**不得當作精確門檻使用**，應併同 min／max 與完整分布判讀。

### ⚠️ 2.2.1 PC3 不是「側睡凸出高度」

**這兩者都叫「厚度」，但完全不是同一個量，混用會造成嚴重設計錯誤。**

| | PC3 厚度 | 側睡凸出高度 |
|---|---|---|
| 量的是什麼 | **耳廓自身捲曲的深度**（耳廓前後兩面之間） | **裝置相對頭部側面輪廓的突出量** |
| 基準面 | 耳廓點雲自身 | 頭側平面 |
| 本資料能否取得 | 能，21.8mm（平均） | **不能——本資料無頭側／乳突區** |

→ **不可將 21.8mm 用作側睡設計依據。** 側睡邊界見 [Part 4.2](04-max-design-envelope.md)，仍待實測。

### 2.2.2 與卡尺文獻的可比性

PC1 平均 66.6mm 高於人因文獻常見的成人耳廓高度（約 59–65mm）。**此偏差方向可由方法本身預測，非資料異常**：

PCA 第一主軸依定義即為延伸範圍最大之方向，故沿 PC1 的跨距在數學上**必然 ≥** 沿任何其他軸的跨距，包含解剖學上的 superaurale–subaurale 連線。**PCA range 系統性地大於或等於任何兩點卡尺量法。**

→ 本節數值**可與其他 PCA／包圍盒量法比較，不可與卡尺量法無條件比較**。引用時須註明操作型定義。

### 2.2.3 左右對稱性

| 軸向 | mean(L−R) | std(L−R) | mean\|L−R\| | corr(L,R) |
|---|---|---|---|---|
| PC1 長軸 | −0.10 | 2.22 | 1.71 | 0.881 |
| PC2 寬度 | −0.61 | 2.14 | 1.73 | 0.804 |
| PC3 厚度 | +0.65 | 2.79 | 1.82 | **0.430** |

單位 mm。

- PC1／PC2 左右相關性強（>0.80），與來源② 的左右對稱結論方向一致 → **左右可共模**
- **PC3 相關性明顯偏弱（0.430）**。PC3 為特徵值最小之第三主軸，對雜訊與掃描擷取變異最敏感，**可信度低於 PC1／PC2**，不宜作為關鍵設計依據
- 提醒：來源② 指出**角度類尺寸傾向左右不對稱**。本節三軸皆為長度類，**不可據此推論角度類結構亦可左右共模**（見 Part 4.1）

## 2.3 耳甲尺寸【文獻】— 中國年輕成人，男女分列

**本節部分彌補 2.0.1 的兩項限制**：來源③ 為中國樣本且男女分列，可作為亞洲基準與性別分檔的依據——但**僅限耳甲區域，且年齡範圍受限**（見下方限制）。

### 樣本與方法

| 項目 | 內容 |
|---|---|
| 樣本 | **310 名中國年輕成人，18–28 歲**。女 141 人、男 169 人，左右耳皆量 |
| 方法 | 耳印模（ear impression）＋3D 掃描，每耳 7 個地標 |
| 量測 | 12 項耳甲形態學量測 |

> ⚠️ **同一批 310 人樣本的相關論文，其地標數與分群數在不同二手來源間說法不一致**：本節依來源③ 原文為 **7 地標／12 量測**；另有二手描述稱「5 特徵點／7 特徵距離／24 群」，亦有搜尋結果稱 Ji et al. (2018) 分為 **27 群**。三者互不吻合。
> **本指引僅採用來源③ 原文可核的 7 地標／12 量測。** 分群數（24 或 27）本指引未使用，如需引用須先取得 Ji et al. (2018) 全文核對（該篇 Wiley 全文為 403，尚未取得）。

### 地標定義（採用本套系統，不自創）

| 地標 | 定義 |
|---|---|
| P1 | 耳前切跡（incisura anterior auris）邊緣最後方點 |
| P2 | 耳屏（tragus）隆起點 |
| P3 | 耳屏間切跡（intertragic notch）最深點 |
| P4 | 對耳屏（antitragus）隆起點 |
| P5 | 對耳輪（antihelix）曲率最強點 |

### 數值（mean ± SD，單位 mm；∠θ 為度）

| 量測 | 定義 | 左男 | 右男 | 左女 | 右女 |
|---|---|---|---|---|---|
| TL | 耳屏總長 P1→P3 | 18.07±1.35 | 18.37±0.91 | 16.64±1.21 | 17.03±1.22 |
| TL1 | P1→P2 | 9.38±1.09 | 8.84±0.93 | 8.68±0.97 | 8.26±1.00 |
| TL2 | P2→P3 | 8.69±1.11 | 9.53±0.95 | 7.96±1.13 | 8.77±1.09 |
| ATL | 對耳屏總長 P3→P5 | 13.85±1.25 | 14.19±1.05 | 12.45±1.28 | 12.88±1.17 |
| ATL1 | P3→P4 | 7.41±0.90 | 6.82±0.83 | 6.51±0.87 | 6.16±0.84 |
| ATL2 | P4→P5 | 6.44±0.88 | 7.37±0.89 | 5.94±0.91 | 6.72±0.83 |
| **CW** | **耳甲寬 P1→P5** | **17.04±1.34** | **17.26±1.38** | **15.69±1.53** | **15.96±1.41** |
| BD | 耳屏—對耳屏隆起間距 P2→P4 | 16.10±1.36 | 16.38±1.20 | 14.93±1.40 | 15.25±1.34 |
| HECO | 耳道開口高 | 9.82±1.06 | 9.93±1.13 | 9.46±0.91 | 9.71±**7.14** ⚠️ |
| WECO | 耳道開口寬 | 7.74±1.10 | 7.98±1.02 | 7.14±0.86 | 7.41±0.58 |
| **CD** | **耳甲深**（耳甲最深點至 P1P3P5 平面垂距） | **10.19±0.93** | **9.83±0.81** | **9.65±0.94** | **9.53±0.98** |
| ∠θ | P1P3P5 平面與耳道開口夾角 | 62.36±7.42 | 61.87±7.56 | 61.74±7.60 | 61.33±7.82 |

除 ∠θ 外，所有量測的男女差異皆達統計顯著（p<0.05），**男性均大於女性**。左右不對稱亦顯著，但**各項左右差異皆小於 1mm**。

> ⚠️ **HECO 右女的標準差 ±7.14 判定為原文錯誤，不予採用。**
> 依據：①其餘 43 個線性量測標準差落在 0.58–1.53（平均 1.07），7.14 為典型值的 6.7 倍 ②同項目左女為 ±0.91，右耳不可能突增至 ±7.14 ③若為常態分布，將有 **8.7% 樣本的耳道開口高度為負值**，物理上不可能。
> 合理推測應為 1.14 或 0.714，但**此為猜測，不填入**。該格標【原文疑有誤】。其餘數值不受影響。

### ⚠️ 使用限制

| 限制 | 說明 |
|---|---|
| **年齡僅 18–28 歲**（**但影響分維度，不是整表一律**） | **⚠️ 2026-08-27 依來源④ 細化：本表不是每一列都同樣受年齡影響。**<br>**受影響（直接套用會系統性偏小）**：耳甲寬（CW）、耳屏總長（TL）、耳道開口寬（WECO）等線性尺寸——來源② 指出耳部尺寸終生增長，**來源④（1,120 人、15–79 歲）指出「多數線性變數隨年齡穩定增加」**。<br>**不受影響**：**耳甲深（CD）——來源④ 明確列為「無特定年齡趨勢」的三項之一**（另兩項為耳屏高、耳廓傾角）。故本表 CD 值不因樣本年齡而系統性偏小。<br>此外耳廓形態類型與年齡組別有明顯關聯。助眠產品使用者年齡偏高，本表的線性尺寸部分不具代表性 |
| 僅涵蓋耳甲區域 | 耳廓整體外部包絡仍以 2.2 的【實測】數據為準 |
| 量測介質不同 | 本表為耳印模＋掃描；2.2 為直接點雲。兩者不可無條件互比 |

## 2.4 耳甲深度 CD【實測】

### 操作型定義（**不等於** 來源③ 的 CD）

以耳甲最深點為錨點 → 取其周圍環帶內的前表面點（碗緣鄰域）→ 對該批點做最小平方平面擬合 → 取耳甲最深點至該擬合平面的垂直距離。

**環帶半徑依各耳自身尺度縮放**（該耳 PC1 的 7.6%–30.3%），非固定絕對值。此為改進版；固定絕對半徑的初版已被否決，見 2.4.2。

> ⚠️ 來源③ 的 CD 基準面為 **P1P3P5 三點平面**（前方三個具名地標）。本節基準面為**碗緣鄰域擬合平面**，為近似，**非同一基準**。兩者可比較量級，不可直接比對數值。

### 統計結果（n=56，以人為單位，無排除）

| 統計量 | 數值 (mm) |
|---|---|
| min | 6.43 |
| P5 | 7.34 |
| P25 | 8.80 |
| P50 | 9.29 |
| P75 | 9.75 |
| P95 | 10.30 |
| max | 10.87 |
| **mean** | **9.15** |
| std | 0.88 |

左右對稱性：std(L−R) = 0.96mm，**corr(L,R) = 0.552**。

### ⚠️ 2.4.1 只有平均值可用，百分位與個別值不可作為設計門檻

**corr(L,R) 實際上就是本量測的信度係數。** 將左右耳視為「同一真值＋各自獨立雜訊」拆解：

| 推導 | 初版（絕對半徑） | **現行版（相對半徑）** |
|---|---|---|
| 單耳量測雜訊 sd ＝ std(L−R)/√2 | 0.70mm | **0.68mm** |
| 真實個體間差異 sd | 0.62mm | **0.74mm** |
| 模型預測 corr(L,R) | 0.436（實測 0.437） | 0.541（**實測 0.552**） |
| **雜訊佔單次量測變異** | 56% | **46%** |

> **單次 CD 量測的變異中約 46% 為量測雜訊，非真實解剖差異。**【推論，基於實測數據推導】
> 改用相對半徑後降低約 10 個百分點，**但未消除**。
>
> 嚴格而言雜訊值為**上界**——來源③ 指出左右耳存在真實的統計顯著不對稱（<1mm），故 L−R 差異中有一部分為真實差異。

**因此：**

| 可用 | 不可用 |
|---|---|
| **mean 9.15mm**（雜訊在 56 人上平均掉，標準誤 ≈0.12mm） | **P5 = 7.34mm 不得作為「最淺耳甲」設計下限** |
| 量級與分布形狀的定性判讀 | 個別受試者的 CD 值 |

> ⚠️ **本節唯一可安全用於設計的數字是 mean。** 百分位與個別值皆受雜訊主導。

#### 本信度指標的已知盲點

上述拆解以左右耳差異估計雜訊。**若某項偏差在同一個人的左右耳之間是一致的，此方法看不見它。**

現行版環帶半徑依 PC1 縮放，而同一人左右耳 PC1 幾乎相同——**故任何隨耳朵大小變化的系統性偏差都會被 L−R 差異抵消，不會反映在 corr(L,R) 上，卻會膨脹「人與人之間」的變異估計。**

這正是需要留意之處：真實個體間 sd 從 0.62 升至 0.74，可能是初版環帶過大壓縮了真實差異、現行版將其還原（樂觀解讀），也可能是縮放引入了尺度相依偏差。**L−R 判準無法區分兩者，故另做下述檢定。**

#### 尺度相依偏差檢定——傾向判定「有引入」

**觀察**：CD 與耳廓整體尺寸（PC1）的相關性，初版 0.29 → 現行版 **0.54**。

**檢定一：衰減校正。** 量測雜訊會稀釋觀測相關性（classical attenuation，觀測 r ≈ 真實 r × √信度）：

| 版本 | 信度 | 觀測 r(PC1,CD) | 反推真實 r |
|---|---|---|---|
| 初版 | 0.437 | 0.29 | 0.44 |
| 現行版 | 0.552 | 0.54 | **0.73** |

若兩版差別僅在雜訊多寡，反推的真實 r 應相同。實際相差甚大。**若真實 r 即初版反推的 0.44，現行版在信度 0.552 下應僅觀測到 0.33，實測 0.54，超出 +0.21。**

此結論方向穩固：如上節所述，L−R 判準看不見左右耳共有的偏差，故若確有尺度相依偏差，它會被計入「真實變異」而**高估現行版信度**；修正此偏誤只會使反推的真實 r 更高，**加強而非削弱本結論**。

**檢定二：統計顯著性——不到定論。** Fisher z 檢定下，0.29 與 0.54 在 n=56 差距約 **1.6 個標準誤**（獨立樣本近似；兩相關係數取自同一批人、彼此正相關，實際標準誤較小，故真實顯著性略高）。**為提示性證據，非定論。**

**機制上的佐證**：耳朵越大 → 環帶絕對半徑越大 → 取樣延伸至耳廓更外側，而該處向頭部方向彎折 → 擬合平面後移 → 量得深度偏大。**大耳朵→CD 偏大**，恰為觀察到的正相關方向。初版固定半徑無此尺度相依位移。

> **結論**：傾向判斷現行版引入了尺度相依成分，惟證據為提示性而非定論。
> **「CD 分布中獨立於耳朵大小的真實變異」此一宣稱應從嚴看待。**
> **mean 9.15mm 不受影響**，仍為本節唯一可安全用於設計的數字。

### 2.4.2 兩個已測試並否決的改進方向

保留於正文而非附錄——當有人看到 P5=7.34 而想截去低端時，這段記錄應在該被讀到的時候出現。

#### 否決一：排除低端離群值

曾檢視初版 CD 最低的 5 隻，確實觀察到偵測瑕疵（最深點偏離凹陷中央、固定絕對半徑環帶相對耳朵過大）。排除後 n=51 得 mean 9.26／std 0.60／P5 8.25，**與當時雜訊拆解的預測（真實 sd 0.62、生物 P5 ≈8.1）高度吻合**。

**但此排除已被否決，未採用。** 理由：

1. **選擇偏誤**：僅檢視低端即排除低端。改以相同標準檢視 CD 最高 5 隻與中段隨機 5 隻後，**同樣的環帶尺度瑕疵在中段與高端亦可見，比例無明顯差異**——瑕疵為全體性方法限制，非低端特有。
2. **推測機制遭證偽**：原推測「小耳朵→環帶過大→CD 偏低」。實查低端 5 隻的 PC1 平均 65.1mm，與全體平均 66.6mm 相當（5 隻中 3 隻高於平均）；全體 PC1 與 CD 相關性僅 0.29。**低 CD 與小耳朵無關。**
3. **吻合是弱證據**：自任何分布單邊截去 5 個極端值，標準差本就會下降，故降至 0.60 不足以反證排除正確。

> **本節維持 n=56，不做排除。** 註：**雜訊拆解結論不受此否決影響**——該分析的輸入為 std(L−R) 與每人平均 sd，與低端樣本是否納入無關，其驗證來自預測 corr 對上實測值。

#### 否決二：固定絕對半徑環帶

初版環帶為固定 5–20mm，未依耳朵自身尺度縮放，在尺寸有變異的母體上為已知弱點。**已改為相對半徑（PC1 的 7.6%–30.3%）並重跑全部 112 隻。**

改進的成功判準**於重跑前預先定義**，避免事後合理化。判準依據：左右耳的真實解剖差異為生物事實，不隨演算法改變，故 L−R 離散度**只可能因量測雜訊減少而下降**——此為不受演算法影響的獨立指標。

| 指標 | 初版 | 現行版 | 預定方向 | 結果 |
|---|---|---|---|---|
| std(L−R) | 0.99mm | 0.96mm | 下降 | ✓ |
| corr(L,R) | 0.437 | 0.552 | 上升 | ✓ |
| 單耳雜訊 sd | 0.70mm | 0.68mm | 下降 | ✓ |

三項皆符合，故採用現行版。**惟此判準有盲點**，見上節。

> ⛔ **拿 P5 = 7.34mm 當設計下限，等於為量測誤差做設計。**

同源提醒：2.2.3 的 PC3 corr(L,R)=0.430 與此處 0.437 幾乎相同，**深度類量測在本資料集上的信度即為此量級**。

### ⚠️ 2.4.3 與網路資料對照時的陷阱：「耳甲深」沒有統一定義

**查網路會看到「耳甲深 14–17mm」之類的數字，與本節的 9.15mm 相差近兩倍。這通常不是誰算錯，是量的不是同一條線。**

| 說法 | 典型數值 | 量什麼 |
|---|---|---|
| 本節與來源③ | **9–10mm** | 從**耳甲碗緣平面**往下到碗底 |
| 部分文獻／網路資料 | **14–17mm** | 疑似從**耳廓外緣／耳輪**往下到碗底——多算進對耳輪那道牆的高度 |
| 耳甲**直徑／寬度** | 15–20mm | 完全不是深度。本文件的 CW（來源③）為男 17.0–17.3、女 15.7–16.0mm，與 14–17mm 高度重疊 |

**文獻中「耳甲深」的數值跨度本身即為 9–16.8mm，且該變異被明確歸因於各研究量測方法不同**（許多研究未載明定義）。

> ⛔ **不可將不同來源的耳部尺寸混用。** 每個數字都綁著它自己的基準面定義。
> 這與 2.2.2「本節 PCA 數值不可與卡尺文獻無條件比較」是同一個原則。

**設計時該用哪一組**：若在為「機體塞進耳甲碗」定尺寸，用碗緣基準（9–10mm 這組）；「耳朵表面到碗底」是另一個更大的數字，與機體可用厚度無關。

### 2.4.4 與來源③ 的對照

來源③ CD：男左 10.19±0.93、男右 9.83±0.81、女左 9.65±0.94、女右 9.53±0.98。

本節 mean 9.15mm 略低於文獻各組平均，但屬同一量級，分布與文獻區間重疊。差異可能來源：基準面定義不同（見上）、量測介質不同（直接點雲 vs 耳印模＋掃描）、族群與年齡結構不同。

（初版絕對半徑法曾統計「56 人中 23 人落於文獻 9.53–10.19 區間」；**該計數未在現行相對半徑版重算，故不列出**。）

**此對照的價值不在數值相等，而在於它獨立驗證了「點雲 → 耳甲偵測 → 深度量測」整條管線的合理性**——即使 P1–P5 具名地標未能取得，耳甲深度這項核心量測本身站得住。

### 2.4.5 未能取得的耳甲尺寸——改用文獻

耳甲寬（CW）、耳屏總長（TL）、對耳屏總長（ATL）、耳道開口高寬（HECO／WECO）、開口角度（∠θ）等**需要 P1–P5 具名地標的尺寸，本團隊自動偵測未能可靠取得，改引 2.3 的文獻值並標【文獻】。**

**技術障礙**：資料集的 55 個地標為 **2D 影像座標**（標註於 jpg），與 3D 點雲**非同一座標系**。經查官方原始碼，2D 地標僅做影像寬度正規化，無相機內參或投影矩陣；論文亦載明照片與掃描為兩次獨立拍攝。**故無現成 2D→3D 對應，具名地標須直接於 3D 點雲識別。**

**嘗試過程與停止原因**：以耳甲最深點為錨、環帶角度分箱建立「深度—角度」一維訊號的方法框架**成立**（見 2.4.5.1 中間發現①），但無法判定哪個波峰對應耳屏——P1→P5 僅涵蓋耳甲**前方局部弧段**，360° 掃描到的波峰混入耳輪腳、對耳輪等不在鏈上的構造。要收斂角度範圍需先確立「前方」方向，而該檢查所需的耳屏 3D 座標**無法以靜態渲染圖肉眼可靠點取**。

> **停止的理由是「無法可靠執行該檢查」，不是「檢查結果為否」。** 硬點出的座標會產出看似跨樣本一致、實則為估點誤差的結論，且事後無人能分辨。**故不產出。**

#### 2.4.5.1 兩個中間發現（供後續接手者）

1. **環狀一維訊號地標偵測框架可行。** 以耳甲錨點為中心、5–20mm 環帶、角度分箱（5°×72 格）取深度剖面，訊號乾淨、跨樣本一致，波峰／波谷交替節奏符合解剖預期（5/5 樣本皆出現振幅遠大於其他的主峰＋規律的 4 峰 4 谷）。**架構已成立，缺的是最後一塊：耳屏於前方弧段的具名定位。** 需要互動式 3D 標記或真正的 2D–3D 像素級配準工具。
2. **原始座標系（非 PCA 旋轉）的 Z 軸為跨樣本一致的深度軸。** Z-vs-Y 投影在 6/6 樣本給出正確可辨識的耳朵正面輪廓，X-vs-Y 則否。搭配已知一致的 Y 軸（長軸），可知本資料集原始 XYZ 為有意義的標準化朝向，非任意值。**後續若重新嘗試地標偵測可直接沿用，不需重新發現。**

## 2.5 待補

**注意**：以下僅列**仍在進行中**的項目。已確認取不到的資料限制見 2.0.1 與 2.0.2，那些不列在此。

| 缺口 | 取得方式 | 影響 |
|---|---|---|
| 年齡偏高族群的**數值**尺寸 | 來源④ 已核實存在（1,120 人、15–79 歲、中國大陸、專為耳戴式裝置），**但數值表在付費牆後未取得**。取得前依 2.0.2 以「上緣留餘裕＋年長者試戴」處理 | 中。已有替代做法，非阻塞 |
| 耳後與乳突區 | 需另行採集含頭側的掃描 | 中。掛耳式評估所需 |
| 耳道深部與入口徑／角度 | 需耳印模（ear impression）或其他量測方式 | 中 |

---

## 來源

① Huang, X., Wang, Y., Liu, Y., Ni, B., Zhang, W., Liu, J., Li, T. **AudioEar: Single-View Ear Reconstruction for Personalized Spatial Audio.** *AAAI 2023*. arXiv: [2301.12613](https://arxiv.org/abs/2301.12613) ｜ 資料集：Zenodo 記錄 7592895 ｜ 程式碼：github.com/seanywang0408/AudioEar
　類型：學術論文＋公開資料集（CC BY 4.0）。**arXiv 頁面已實際開啟核對**（標題、作者、112 point cloud ear scans、55 landmarks 皆吻合）。

② Fu, F., Luximon, Y. **A systematic review on ear anthropometry and its industrial design applications.** *Human Factors and Ergonomics in Manufacturing & Service Industries*, 2020, 30: 176–194. DOI: [10.1002/hfm.20832](https://doi.org/10.1002/hfm.20832)
　類型：學術論文。**已下載並讀取原文確認。**

③ Zhu, Z., Ji, X., Gao, Z., Hu, G. **A Morphometric Study of Auricular Concha in the Population of Young Chinese Adults.** *International Journal of Morphology*, 2017, 35(4): 1451–1458.
　全文：<https://scielo.conicyt.cl/scielo.php?script=sci_arttext&pid=S0717-95022017000401451>
　類型：學術論文（開放存取）。**全文已實際開啟，數值表逐格轉錄。** 註：`www.scielo.cl` 之 PDF 與全文頁受 Cloudflare 阻擋，改用 `scielo.conicyt.cl` 舊網域可取得。

④ Wang, M., Fan, H., Yu, S., Wang, L., Chu, J., Tang, X., Li, W., Zhao, X., Zhang, S., Chen, D. **Analysis of the auricles and auricular shape types for ear-related wearables: A study of mainland Chinese sample aged 15–79.** *Work*, 2022, 73(1): 335–352. DOI: [10.3233/WOR-210799](https://doi.org/10.3233/WOR-210799)
　類型：學術論文。1,120 名中國大陸受試者，15–79 歲，鑄模（casting）＋3D 掃描，18 項耳廓量測變數，歸納五種耳廓形態類型。
　**摘要已透過 Europe PMC API 核實（2026-08-27 再次逐句核對）；全文為封閉取用（Unpaywall 查詢：is_oa=false），數值表未取得。** 目前僅引用其質性結論，**未引用任何數值**：
　- 量測值隨年齡連續變化，**多數線性變數呈穩定增加**
　- **⚠️ 例外：耳廓傾角、耳甲深（conchal depth）、耳屏高（tragal height）三項「未呈現特定年齡趨勢」**——原文：*"The auricular inclination angle, conchal depth and tragal height did not exhibit any specific trend across the age groups."* **這一句是本指引唯一自有實測值（CD）得以免除年齡疑慮的依據。**
　- 形態類型與年齡組別強相關（分五類）
　- 男女皆未觀察到顯著的左右差異——**⚠️ 此點與來源③（左右不對稱顯著但各項 <1mm）不一致——這是「兩方」不一致，不是三方。**<br>**⛔ 本節 2.2.3 的 PC3 左右相關 0.430 不可列為第三個資料點。** 低相關可能來自真實不對稱，也可能來自量測雜訊，**兩者在單一相關係數裡混淆、分不開**；而本節已拆解出 CD 雜訊約佔變異 46%，PC3 的 0.430 與 CD 的 0.437 幾乎相同——**那是深度類量測的信度水準，不是解剖結論。本專案資料無法裁決 ③ 與 ④ 的分歧，既不支持也不反對任何一方。**<br>**且 ③④ 量測方法不同**（③ 為耳印模＋3D 掃描具名地標、④ 方法未核），**方法不同本來就不應期待收斂，不要嘗試調和數字。** 要比較必須先統一量測定義

⑤ Fu, F., Luximon, Y. **Comfort and fit perception based on 3D anthropometry for ear-related product design.** *Applied Ergonomics*, 2022, 100: 103640. DOI: [10.1016/j.apergo.2021.103640](https://doi.org/10.1016/j.apergo.2021.103640)
　類型：學術論文。**摘要已透過 Europe PMC API 核實。** 30 名受試者（15 男 15 女），受試者內設計。
　與來源② 同一作者群。原文結論：耳部對稱性、性別、耳甲長度、耳甲腔寬度與知覺評分相關性不顯著或很弱；使用情境與產品尺寸則顯著影響；動態情境下偏好較大尺寸。

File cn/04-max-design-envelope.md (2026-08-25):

# Part 4 — 最大可設計區域

狀態：**方法已定，關鍵數值待實測** ｜ 最後更新 2026-08-21

> 🌐 日本語版：[jp/04-max-design-envelope.md](../jp/04-max-design-envelope.md)

回答需求方的提問：**最大可設計區域可到哪裡。**

> **用語規範**：耳部與醫學名詞一律中文在前、英文於括號內，例如 耳甲腔（cavum conchae）。

---

> ⛔ **範圍裁定（2026-08-25）：第一階段只服務夜間長時間睡眠（整夜臥睡）。坐睡（辦公室午睡、交通工具）已移出。**
> 本章與坐睡／情境 B 相關的段落**保留但不適用於第一階段**——保留是為了讓「考慮後排除」與「未曾考慮」可以區分，未來擴充情境時可直接取用。
> **引用本章任何形態評分或約束時，必須確認該結論是否綁定坐睡。** 坐睡移出會翻轉部分形態的排序（掛耳式、頭帶眼罩式）。

## 4.0 結論先講

可設計區域是**兩個成因完全不同的邊界取交集**：

```
可設計區域 = 解剖邊界 ∩ 側睡邊界
```

| 邊界 | 限制什麼 | 成因 | 現況 |
|---|---|---|---|
| **解剖邊界（anatomical bound）** | 耳廓（auricle）能「容納」多少 | 耳部幾何，因族群與性別而異 | 方法已定，數值待補 |
| **側睡邊界（side-sleep bound）** | 耳外能「凸出」多少 | 枕頭壓迫 | **方法已定，數值無公開來源，須實測** |

**兩者不可合併成單一數字。** 解剖上容得下的體積，不代表側睡時凸出高度可以接受——後者由枕頭與受壓機制決定，不是由耳朵容積決定。合併會同時放寬錯的方向、限制錯的方向。

### ⚠️ 機型 S／M／L 的定義（易誤解，先講清楚）

**機型 S／M／L 指的是「同一顆耳朵可配戴的三種不同大小的耳機」，是機體變體，不是人耳尺寸分檔。**（需求方 2026-08-21 澄清、2026-08-24 再次澄清）

**耳朵大小的分段是另一個概念，本指引稱「耳型分段 I／II／III」，字母不與機型共用。** 完整區分見 [Part 0.4b](00-scope-and-usage.md)。

| 概念 | 內容 |
|---|---|
| 解剖邊界 | **一個包絡**（男／女各一），所有機型共同的天花板 |
| 機型 S／M／L | **三個落在該包絡內的機體尺寸目標**，代表不同的設計取捨 |
| 「最大可設計區域可到哪裡」 | 等同於問「**機型-L 能做到多大**」 |

> ⛔ **三個機型各自都必須容納整個耳型範圍。** 不是「機型-L 給大耳朵」——耳朵差異由**配件（耳塞／耳翼）尺寸**吸收，不由機型吸收。

三檔的典型取捨方向：

| 機型 | 特性 | 代價 |
|---|---|---|
| L | 貼近解剖包絡上限，可容納較大驅動器／電池 | 側睡風險最高 |
| M | 折衷 | — |
| S | 刻意做小，側睡最安全 | 聲學與續航讓步 |

**⏳ 待確認**：三檔差異的**目的**是**功能取捨**（驅動器／電池大小）或**產品線區隔**？這決定機型-L 該不該逼近包絡上限。
（「適配不同耳朵大小」已由定義排除——那是配件尺寸的職責，不是機型的。）

---

## 4.1 解剖邊界（anatomical bound）

### 需要量測的尺寸

| 尺寸 | 定義 | 限制什麼 |
|---|---|---|
| 耳甲腔（cavum conchae）寬 × 高 × 深 | 耳甲腔可用容積 | 機體本體最大尺寸 |
| 耳甲艇（cymba conchae）寬 × 高 | 上耳甲可用空間 | 上緣延伸極限 |
| 耳道（ear canal）入口直徑與角度 | 入耳部截面 | 耳塞（eartip）直徑 |
| 耳道有效深度 | 到第一彎曲（first bend） | 入耳部長度 |
| 耳屏（tragus）—對耳屏（antitragus）間距 | 開口寬度 | 機體置入通道 |
| 耳輪（helix）內緣輪廓 | 外圍邊界 | 固位翼延伸範圍 |

### 包絡定義規則

- **男／女分列**，依需求方指示 → 產出兩個解剖包絡
- 基準族群：**亞洲成人**，依需求方指示（2026-08-21 確認）
- 建議以第 5 百分位（P5）為包絡下限依據——**要讓最小的耳朵也裝得下，包絡必須遷就小耳者，不是取平均值**
- P95 用於確認大耳者不會有固位不良（過鬆）問題
- 機型 S／M／L 三個機體尺寸目標皆須落在此包絡內

### 現況與缺口

| 項目 | 狀態 |
|---|---|
| **亞洲成人「分性別之整耳外廓」包絡** | **部分取得。** [Part 2.2](02-anthropometric-basis.md) 已有整耳外廓【實測】(n=56)，但**族群未確認、無法分性別**；[Part 2.3](02-anthropometric-basis.md) 已有中國樣本耳甲數據且**男女分列**，但**僅限耳甲區域**。**缺的是兩者交集——分性別的亞洲成人整耳外廓。** 來源① 為系統性回顧，不含可引用的百分位表 |
| 已確認的族群差異（ethnic variation） | 亞洲／西方／非洲人群耳部尺寸存在顯著差異，**不可混用基準**【文獻】① |
| 已確認的性別差異（sex difference） | 多數族群男性耳部大於女性【文獻】① |
| 已確認的年齡效應（age effect） | **耳部尺寸終生持續增長**【文獻】①。助眠產品使用者年齡偏高，用一般成人平均值有偏小風險 |
| 已確認的對稱性（symmetry） | 線性／面積／比例尺寸左右對稱良好；**角度類尺寸傾向不對稱**【文獻】① → 耳塞可左右共模，**涉及角度的固位結構不可假設左右通用** |

---

## 4.2 側睡邊界（side-sleep bound）★ 本指引最關鍵的約束

### 為什麼它最關鍵

睡眠耳機的第一道生死線。側睡時裝置被枕頭壓迫，超過臨界值則其餘設計再好都無法使用。這也是睡眠耳機**唯一**與一般耳機本質不同的幾何約束。

### ⚠️ 真正的物理量是「傳遞壓力」，凸出高度只是代理指標

**決定側睡舒適度的是「枕頭透過裝置傳進耳朵的接觸壓力」，不是凸出高度本身。** 傳遞壓力取決於：

| 因素 | 說明 |
|---|---|
| 凸出高度 | 頂進枕頭多深 |
| **枕頭順應性（pillow compliance）** | 軟枕會包覆小凸起，硬枕不會。同一裝置在記憶棉枕與蕎麥枕上結果不同 |
| **凸起接觸面形狀** | 寬而圓者分散壓力，小而硬者集中壓力。**同樣高度，結果差很多** |
| **裝置本體剛性** | 剛性殼把枕頭的力原封不動傳入耳部；具柔性者吸收一部分 |

→ **一個矮但硬又尖的凸點，可能比一個高但寬圓有彈性的凸起更痛。**【推論】

凸出高度是**入耳式設計中最實用、最好量的代理指標**，與真實壓力高度相關，業界追求齊平（flush）即基於此。但它不等於物理量本身，也**不適用於所有形態**——見 4.2.1。

### 4.2.1 側睡判準依形態族分別定義

**不同形態的受壓機制不同，不能共用同一把尺。** 以下為各形態族的判準與特有失效模式。

**本節除標註者外皆為【推論】**——依解剖與力學推理得出，未找到直接對應的實證文獻。使用前應以實體試戴驗證。

| 形態族 | 主要受壓部位 | 側睡判準 | 特有失效模式 |
|---|---|---|---|
| **入耳式（in-ear）** | 耳甲腔（cavum conchae）、耳屏（tragus） | 相對**耳廓外緣平面**的凸出高度 | 裝置被頂入耳道；耳屏受壓 |
| **掛耳式（ear-hook）** | 乳突區（mastoid）、耳輪（helix）上緣 | ①相對**頭部側面輪廓**的最外緣厚度 ②耳後主體對乳突區壓力 ③耳廓是否被折彎 ④耳掛剛性 | **⚠️ 耳廓被折彎**（耳掛成為槓桿支點放大）；**⚠️ 裝置把耳廓撐離頭部，此時凸出的是耳朵本身**；耳後為骨頭直接位於薄皮下，非軟骨緩衝 |
| **扁平耳罩（flat over-ear）** | 整個耳廓與周圍頭皮 | 相對頭部側面輪廓的總厚度 | 壓力分散面積大（有利），但**整個耳廓同時受載**；罩緣（rim）壓在頭皮形成環狀壓痕 |
| **頭帶／眼罩式（headband／eye-mask）** | 依裝置位置而定，通常有織物層緩衝 | 裝置在織物袋中的**局部厚度** | 織物分散壓力（有利）；但**裝置在袋中會位移**，可能滑到耳朵正上方 |
| **骨傳導（bone conduction）** | 顴骨／顳部（temple），耳前 | 耳前接觸件相對頭部輪廓的厚度 | 受壓點在耳前而非耳內，避開耳甲；但顳部同樣為骨頭直接位於薄皮下 |

### 4.2.2 掛耳式為何對側睡先天不利

> ⚠️ **本節僅適用於情境 A（臥睡）。**
> **情境 B（坐睡）不壓迫耳後，以下所述的掛耳式劣勢在該情境下不成立**——見 4.2.3。
>
> ⛔ **在情境 A 中，掛耳式為高風險路徑。**
> 現有掃描資料僅含耳廓本體，**無耳後與乳突區（mastoid）**，且需求方於 2026-08-21 確認無其他可用資料。
> **本指引無法為掛耳式的側睡表現提供任何實測依據——以下全為【推論】。**
> 若在情境 A 選擇掛耳式，**必須以實體樣機驗證後才能定案**。推論不等於驗證。

需求方於 2026-08-21 提問掛耳式如何評斷，此處補充判斷依據。

掛耳式的優勢對睡眠情境確有價值：不塞耳道（避開 Part 3 的耳屏與外耳道敏感區）、透氣佳、不易脫落。

但代價集中在一處：**耳後主體。**

1. **你會直接躺在它上面。** 側睡時耳後正好是頭部與枕頭之間的受力路徑。
2. **底下是骨頭。** 乳突區皮下即為顳骨乳突部，缺乏軟組織緩衝，與耳甲的軟骨＋軟組織不同。
3. **槓桿效應。** 耳後主體受壓會對耳掛產生力矩，把力放大後施加在耳輪上緣。耳掛越硬，放大越明顯。

→ **若採掛耳式，設計重點應為：耳後主體極薄化、耳掛採低剛性（避免槓桿）、確保耳廓不被折彎。** 而非沿用入耳式的凸出高度判準。【推論】

### 4.2.2b 市場對照：業界的耳朵尺寸分段

一份市售產品（Soundcore Liberty 3 Pro）的消費者選購指南將耳甲尺寸分為三段，對應不同耳翼尺寸：

| 量測值 | 建議耳翼 | 該指南的說明 |
|---|---|---|
| < 14mm | XS／S | 小巧緊緻型，大號耳翼有壓迫風險 |
| 14–17mm | S／M | 「大多數人的區間」 |
| > 17mm | M／L | 需較大耳翼填滿空隙以提供槓桿支撐 |

**來源等級：【市場商品統計】，強度弱。** 該頁自承「沒有絕對的官方對應表」「基於人體工學常識的估算，並非廠商的絕對技術規格」。

> ⚠️ **其 mm 數值不可與 [Part 2](02-anthropometric-basis.md) 混用。** 該指南的「耳甲腔垂直高度」定義為**從耳屏內側邊緣到耳甲底部最深處的斜線**——起點是耳甲前壁上的隆起構造，故該線同時含平面與深度分量，**在幾何上必然大於自碗緣平面往下的垂直深度**（Part 2.4 的 CD，9–10mm）。兩者不是同一個量。

> ⛔ **這是「耳型分段 → 配件尺寸」的對照，與機型 S／M／L 無關。**
> 該指南從頭到尾講的是「這位使用者該配哪個耳翼」，**完全沒有觸及機體變體**。不可用來回答機型尺寸的問題。（此處先前曾誤將兩者連結，已更正。三概念區分見 [Part 0.4b](00-scope-and-usage.md)。）

**可用之處**：它佐證**業界實際將耳朵尺寸分為三段**來配不同尺寸的固位件，即本指引所稱的**耳型分段 I／II／III**。**不足以作為分段切點的依據。**

> ⚠️ **任何「手動量測 → 對照尺寸表」的方案，分段寬度必須大於量測不確定度。**
> 以直尺伸入耳窩的量測，不確定度約 ±1–2mm【推論，未實測】；而該指南的分段間距本身也只有 3mm 級距。**不確定度與分段間距同一量級時，量測結果基本無法區分相鄰分段。**
>
> 加上 [Part 7.0b](07-wearing-pressure-comfort.md)：耳部尺寸與主觀舒適／貼合的相關性本就不顯著或很弱。
> → **不建議採用「量耳朵挑尺寸」作為主要配適機制。** 改用結果導向的驗證（密封自測、機械貼合快篩），見 Part 7.4.0。

### 4.2.3 形態選型比較——**依情境分列，排序會翻轉**

> ⚠️ **形態優劣沒有跨情境的通用答案。** 下表的結論在數個形態上**方向相反**，而且**坐睡內部的三個子情境之間也會翻轉**。選型前必須先確定服務哪個情境與子情境（見 [Part 1.0](01-use-scenario.md)、[Part 1A.4.1](01a-posture-analysis.md)）。

**坐睡子情境**：**B1 辦公室午睡**／**B2 短程通勤**（須看站）／**B3 長途交通**（飛機、高鐵、客運）

| 形態族 | **A 臥睡** | **B1 辦公室** | **B2 通勤** | **B3 長途** | 主要優勢 | 主要代價 |
|---|---|---|---|---|---|---|
| 入耳式（in-ear） | 中 | 中 | 中 | 佳 | 體積最小，凸出最易控制 | 耳道與耳屏敏感區風險（Part 3）；遮蔽效應（Part 5.4）；**B2 完全密封會聽不到廣播** |
| **掛耳式（ear-hook）** | **高風險** | **佳 ★** | **佳 ★** | **佳 ★** | 不塞耳道、透氣、**固位佳** | A：耳後躺壓在骨頭上、耳廓折彎。**所有坐睡子情境此代價皆消失** |
| 扁平耳罩 | 中高 | 中低 | 中 | 佳 | 壓力分散面積大 | 總厚度大；聲學模擬可信頻段最低（Part 5.5）；B1 外觀顯眼 |
| **頭帶／眼罩式** | **佳 ★** | **低** | 中低 | **佳 ★★** | 織物緩衝，壓力分散最佳；**B3 同時解決遮光與音訊** | A：裝置在袋中位移。**B1：辦公室社交不可行。B2：遮眼看不到站** |
| 骨傳導 | 中 | 佳 | **佳 ★** | 中 | 完全避開耳甲與耳道；開放耳道故環境感知佳 | 顳部同為骨頭受壓；聲學效率與音質限制 |

#### 為何排序會翻轉

**掛耳式**：情境 A 下唯一的重大缺點是「耳後主體被躺壓，且底下是乳突區骨頭」（見 4.2.2）。**坐睡不壓耳後，該缺點直接消失。** 而其優點——不塞耳道、透氣、**固位牢**——在坐睡反而更有價值，因為打瞌睡時頭部前傾側倒，固位正是主導約束。

**頭帶／眼罩式——本表翻轉最劇烈者，且在坐睡內部也翻轉。**
- **A 臥睡佳**：織物緩衝，壓力分散最佳
- **B1 辦公室低**：同事在場，戴眼罩顯眼
- **B2 通勤中低**：遮眼導致看不到站
- **B3 長途佳 ★★**：**長途交通戴眼罩是常態（航空公司主動提供），且白天坐睡的環境光是真問題——眼罩式同時解決遮光與音訊，這是它在該子情境的獨有優勢**

其評分同時受三個互不相關的因素驅動：**機械壓迫**（臥睡有利）、**社交規範**（辦公室不利）、**遮光需求**（白天有利）。**用單一分數表達會失真。**

> **結論**：不存在跨情境的最佳解。臥睡最佳的頭帶／眼罩式在辦公室最差、在長途交通又回到最佳；臥睡最差的掛耳式在所有坐睡子情境皆佳。
> **若須同時服務多情境**，取**聯集**——掛耳式的臥睡問題不因坐睡有利而抵銷。

> **修訂紀錄**：2026-08-24 前本表將坐睡評為「頭帶／眼罩式實用性低」，係將辦公室社交規範概化至全部坐睡情境，並漏計白天遮光的功能優勢。已更正。

⏳ **本表為推理結果，無實證支撐**（情境 A 因缺耳後掃描資料、情境 B 因無任何實測）。建議以實體樣機在各形態、各情境下做試戴比較後修正。【推論】

### 名詞：齊平（flush）

**齊平（flush）** ＝ 與周圍表面同高、不凸出。原為機構用語（flush mounting＝嵌平安裝）。用於耳機指裝置外表面與耳廓（auricle）外緣大致同高，側躺時枕頭先接觸耳朵而非裝置。

> ⚠️ **這是行銷用詞，不是規格。** 廠商使用 "flush fit" 時未定義量測基準面、未定義容許誤差、未公布 mm 數。**不可當作可判定門檻使用。**

### 現況：無公開數值來源

已檢索市售睡眠耳機（Ozlo Sleepbuds、Anker Soundcore Sleep A20／A30 等）。結果：

| 發現 | 內容 | 來源等級 |
|---|---|---|
| 廠商**不公開**凸出高度規格 | 行銷文案僅用 "flush"、"low-profile"、"3D ergonomic" 等定性描述，無 mm 數 | 【市場統計，定性】② |
| 可取得的間接數字 | Soundcore Sleep A30 單耳重約 3 g；宣稱較 A20「薄 7%」 | 【市場統計，弱】② 廠商行銷資料，非技術規格書 |
| 可取得的定性共識 | 業界一致將「與耳廓（auricle）齊平／不凸出」作為側睡設計目標 | 【市場統計，定性】② |

**「薄 7%」是相對值，沒有基準絕對值就無法還原成 mm。** 不可據此推算。

### 取得方式（建議行動）

這個數字**只能實測**。方法依形態族而異：

**共通（所有形態）**
1. **枕頭壓陷量測**：受試者側躺於實際枕頭，量測耳廓（auricle）所在平面的可用間隙。這是物理上限的直接量測。**枕頭種類需分別量**（記憶棉／羽絨／乳膠差異大）。
2. **接觸壓力量測**：薄膜壓力感測器貼於接觸面，量測側躺時的實際界面壓力。**這才是真正的物理量**，凸出高度只是它的代理。

**入耳式加測**
3. 購入 2–3 款主流睡眠耳機，以游標卡尺（vernier caliper）量測配戴狀態下相對耳廓最高點的凸出高度。屬「市場商品統計」來源類型。

**掛耳式加測**
4. 相對頭部側面輪廓的最外緣厚度
5. 耳後主體對乳突區（mastoid）的接觸壓力（分開量，因該處為骨頭直接位於薄皮下）
6. 側躺時耳廓是否被折彎——攝影或壓痕檢查即可

各項取最嚴格者。

**在取得實測值之前，本指引不填任何凸出高度數字。** 這個參數影響全案，填一個猜測值比留空危險得多——留空會被追問，猜測值會被當成依據直接沿用。

---

## 4.3 交集規則

1. 先以解剖邊界界定機體在耳內的**容納體積**
2. 再以側睡邊界界定機體在耳外的**凸出高度**
3. 兩者衝突時，**側睡邊界優先**——容納不下可以改小或換形態，凸出超標則產品不可用
4. **機型 S／M／L 三檔共用同一組解剖邊界與側睡邊界**——邊界由使用者的耳朵與枕頭決定，不隨機體尺寸改變。三檔的差別在於各自選擇在包絡內做到多大

---

## 4.4 待補清單

| 缺口 | 取得方式 | 阻塞程度 |
|---|---|---|
| **側睡凸出高度上限** | 競品實測＋枕頭壓陷實測 | **最高。** 全案關鍵參數 |
| 亞洲成人**分性別之整耳外廓**包絡 | 追來源① 引用之原始研究，或取得含人口統計的 3D 掃描 | 中。整耳外廓已有【實測】、耳甲已有分性別【文獻】，缺的是兩者交集 |
| 機型 S／M／L 三檔的**目的** | 需求方確認（功能取捨 or 產品線區隔） | 高。決定機型-L 該不該逼近包絡上限 |
| 耳道（ear canal）深部尺寸 | 公開文獻多不含，需實測或耳印模（ear impression） | 中 |
| 側睡受壓時耳廓（auricle）變形量 | 僅能實測 | 中。影響動態間隙 |

---

## 來源

① Fu, F., Luximon, Y. **A systematic review on ear anthropometry and its industrial design applications.** *Human Factors and Ergonomics in Manufacturing & Service Industries*, 2020, 30: 176–194. DOI: [10.1002/hfm.20832](https://doi.org/10.1002/hfm.20832) ｜ 免費全文：<https://ira.lib.polyu.edu.hk/bitstream/10397/89894/1/a0733-n14_1220_hfm.pdf>
　類型：學術論文。**已下載並讀取原文確認。**

② 市售睡眠耳機公開產品資訊（Ozlo Sleepbuds、Anker Soundcore Sleep A20／A30 等廠商頁面與媒體評測）。
　類型：市場商品統計。**強度弱——為廠商行銷描述與第三方評測，非技術規格書，且關鍵的凸出高度數值未公開。** 僅用以佐證「業界不公開此數值」及「齊平為共同設計目標」兩點，不作為數值依據。

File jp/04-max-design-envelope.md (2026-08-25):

# Part 4 — 最大設計可能領域

ステータス：**方法は確定、重要数値は実測待ち** ｜ 最終更新 2026-08-21

需求方の問いへの回答：**最大設計可能領域はどこまでか。**

> 🌐 中文版：[cn/04-max-design-envelope.md](../cn/04-max-design-envelope.md)
> **用語規範**：耳の部位名と医学用語は日本語を先に、英語を括弧内に記す。例：耳甲介腔（cavum conchae）。

---

> ⛔ **範囲の裁定（2026-08-25）：第一段階は夜間の長時間睡眠（一晩の臥位睡眠）のみを対象とする。座位睡眠（オフィスの仮眠・交通機関）は除外。**
> 本章のうち座位睡眠／シーン B に関する箇所は**残すが第一段階には適用しない**——残すのは「検討して外した」と「検討しなかった」を区別できるようにするためであり、将来シーンを拡張する際はそのまま使える。
> **本章の形態評価や制約を引用する際は、その結論が座位に紐づいていないか必ず確認すること。** 座位の除外により一部の形態（イヤーフック型、ヘッドバンド／アイマスク型）の順位は反転する。

## 4.0 結論を先に

設計可能領域は**成因のまったく異なる 2 つの境界の交わり**である：

```
設計可能領域 = 解剖学的境界 ∩ 横向き寝境界
```

| 境界 | 何を制限するか | 成因 | 現況 |
|---|---|---|---|
| **解剖学的境界（anatomical bound）** | 耳介（auricle）がどれだけ「収容」できるか | 耳の幾何。集団と性別により異なる | 方法は確定、数値は未取得 |
| **横向き寝境界（side-sleep bound）** | 耳の外へどれだけ「突出」できるか | 枕による圧迫 | **方法は確定。公開データがなく実測が必須** |

**両者を単一の数値に統合してはならない。** 解剖学的に収まる体積であっても、横向き寝で突出高さが許容されるとは限らない。後者は枕と圧迫機構が決めるのであり、耳の容積が決めるのではない。統合すれば、誤った方向へ緩め、同時に誤った方向へ締めることになる。

### ⚠️ 機種 S／M／L の定義（誤解されやすいので先に明確化）

**機種 S／M／L とは「同一の耳に装着できる 3 種類の異なる大きさのイヤホン」であり、本体のバリエーションを指す。人耳のサイズ区分ではない。**（需求方が 2026-08-21 に説明、2026-08-24 に再度明確化）

**耳の大きさの区分は別概念であり、本ガイドラインでは「耳型区分 I／II／III」と呼び、機種と文字を共用しない。** 完全な区別は [Part 0.4b](00-scope-and-usage.md) を参照。

| 概念 | 内容 |
|---|---|
| 解剖学的境界 | **1 つのエンベロープ**（男／女各 1）。すべての機種に共通の天井 |
| 機種 S／M／L | **そのエンベロープ内に収まる 3 つの本体サイズ目標**。異なる設計トレードオフを表す |
| 「最大設計可能領域はどこまでか」 | 「**機種-L をどこまで大きくできるか**」と問うのに等しい |

> ⛔ **3 つの機種はそれぞれが耳型の全範囲を収容しなければならない。**「機種-L は大きい耳向け」ではない——耳の個人差は**アクセサリ（イヤーチップ／ウィング）のサイズ**が吸収するのであり、機種が吸収するのではない。

3 段階の典型的なトレードオフの方向：

| 機種 | 特性 | 代償 |
|---|---|---|
| L | 解剖学的エンベロープ上限に迫り、大きいドライバ／バッテリを収容できる | 横向き寝のリスクが最も高い |
| M | 折衷 | — |
| S | 意図的に小さくし、横向き寝で最も安全 | 音響と電池持ちで譲歩 |

**⏳ 要確認**：3 段階の差異の**目的**は**機能上のトレードオフ**（ドライバ／バッテリの大きさ）か、**製品ラインの差別化**か？ これにより機種-L をエンベロープ上限まで攻めるべきかが決まる。
（「異なる耳の大きさへの適合」は定義上除外済み——それはアクセサリサイズの役割であり、機種の役割ではない。）

---

## 4.1 解剖学的境界（anatomical bound）

### 測定すべき寸法

| 寸法 | 定義 | 何を制限するか |
|---|---|---|
| 耳甲介腔（cavum conchae）の幅 × 高さ × 深さ | 耳甲介腔の利用可能容積 | 本体の最大寸法 |
| 耳甲介舟（cymba conchae）の幅 × 高さ | 上部耳甲介の利用可能空間 | 上端の延伸限界 |
| 外耳道（ear canal）入口の直径と角度 | カナル部の断面 | イヤーチップ（eartip）の直径 |
| 外耳道の有効深さ | 第 1 屈曲（first bend）まで | カナル部の長さ |
| 耳珠（tragus）—対耳珠（antitragus）間距離 | 開口部の幅 | 本体を挿入する通路 |
| 耳輪（helix）内縁の輪郭 | 外周の境界 | 保持ウィングの延伸範囲 |

### エンベロープ定義の規則

- **男／女別**（需求方指示）→ 2 つの解剖学的エンベロープを作成する
- 基準集団：**アジアの成人**（需求方指示、2026-08-21 確認）
- 第 5 百分位（P5）をエンベロープ下限の根拠とすることを推奨——**最も小さい耳にも収まる必要があるため、エンベロープは小さい耳に合わせるのであって平均値を取るのではない**
- P95 は、大きい耳の利用者に保持不良（緩すぎ）が生じないことの確認に用いる
- 機種 S／M／L の 3 つの本体サイズ目標は、いずれもこのエンベロープ内に収まること

### 現況と欠落

| 項目 | 状態 |
|---|---|
| **アジア成人の「性別別の耳介外形」エンベロープ** | **部分的に取得。** [Part 2.2](02-anthropometric-basis.md) に耳介外形の【実測】(n=56) があるが、**集団が未確認で性別に分けられない**。[Part 2.3](02-anthropometric-basis.md) に中国人サンプルの耳甲介データがあり**男女別**だが、**耳甲介領域に限られる**。**欠けているのは両者の交差——性別別のアジア成人の耳介外形である。** 出典① は系統的レビューであり、引用可能な百分位表を含まない |
| 確認済みの集団差（ethnic variation） | アジア／欧米／アフリカの集団で耳の寸法に有意差があり、**基準を混用してはならない**【文献】① |
| 確認済みの性別差（sex difference） | 多くの集団で男性の耳は女性より大きい【文献】① |
| 確認済みの年齢効果（age effect） | **耳の寸法は生涯にわたり増大し続ける**【文献】①。睡眠補助製品の利用者は年齢が高く、一般成人の平均値を用いると小さすぎるリスクがある |
| 確認済みの対称性（symmetry） | 線形／面積／比率の寸法は左右対称性が良好。**角度系の寸法は非対称になりやすい**【文献】① → イヤーチップは左右共通化できるが、**角度を伴う保持構造で左右共用を前提としてはならない** |

---

## 4.2 横向き寝境界（side-sleep bound）★ 本ガイドラインで最も重要な制約

### なぜ最も重要か

睡眠用イヤホンの第一の生死線である。横向き寝では装置が枕に圧迫され、臨界値を超えれば他の設計がどれほど優れていても使用できない。これは睡眠用イヤホンが一般イヤホンと本質的に異なる**唯一の**幾何制約でもある。

### ⚠️ 本当の物理量は「伝達圧」であり、突出高さは代理指標にすぎない

**横向き寝の快適性を決めるのは「枕が装置を介して耳へ伝える接触圧」であり、突出高さそのものではない。** 伝達圧は次の要素に依存する：

| 要素 | 説明 |
|---|---|
| 突出高さ | 枕にどれだけ押し込まれるか |
| **枕の順応性（pillow compliance）** | 柔らかい枕は小さな突起を包み込むが、硬い枕は包み込まない。同じ装置でも低反発枕とそば殻枕では結果が異なる |
| **突起の接触面形状** | 幅広く丸ければ圧力は分散し、小さく硬ければ集中する。**同じ高さでも結果は大きく異なる** |
| **装置本体の剛性** | 剛性シェルは枕の力をそのまま耳へ伝える。柔軟性があれば一部を吸収する |

→ **低くても硬く尖った突起は、高くても幅広く丸く弾性のある突起より痛いことがある。**【推論】

突出高さは**カナル型の設計において最も実用的で測りやすい代理指標**であり、真の圧力と高い相関を持つ。業界がフラッシュ（flush）を目指すのもこれに基づく。しかし物理量そのものではなく、**すべての形態に適用できるわけでもない**——4.2.1 参照。

### 4.2.1 横向き寝の判定基準は形態ごとに定義する

**形態が違えば圧迫の機構が違い、同一の物差しを共用できない。** 以下は各形態の判定基準と固有の破綻モードである。

**本節は注記のあるものを除きすべて【推論】である**——解剖学と力学からの推論であり、直接対応する実証文献は見つかっていない。使用前に実機装着で検証すべきである。

| 形態 | 主な圧迫部位 | 横向き寝の判定基準 | 固有の破綻モード |
|---|---|---|---|
| **カナル型（in-ear）** | 耳甲介腔（cavum conchae）、耳珠（tragus） | **耳介外縁の平面**に対する突出高さ | 装置が外耳道へ押し込まれる。耳珠が圧迫される |
| **イヤーフック型（ear-hook）** | 乳様突起部（mastoid）、耳輪（helix）上縁 | ①**頭部側面輪郭**に対する最外縁の厚さ ②耳後部本体の乳様突起部への圧力 ③耳介が折れ曲がるか ④フックの剛性 | **⚠️ 耳介が折れ曲がる**（フックがレバーの支点となり増幅）。**⚠️ 装置が耳介を頭部から離す方向に押し、このとき突出しているのは耳そのもの**。耳後部は薄い皮膚の直下が骨であり、軟骨の緩衝がない |
| **フラットオーバーイヤー型（flat over-ear）** | 耳介全体と周囲の頭皮 | 頭部側面輪郭に対する総厚さ | 圧力の分散面積が大きい（有利）が、**耳介全体が同時に荷重を受ける**。カップ縁（rim）が頭皮を押して環状の圧痕を作る |
| **ヘッドバンド／アイマスク型（headband／eye-mask）** | 装置の位置による。通常は布層の緩衝がある | 布ポケット内での装置の**局所厚さ** | 布が圧力を分散する（有利）。ただし**装置がポケット内で移動し**、耳の真上へずれることがある |
| **骨伝導（bone conduction）** | 頬骨／側頭部（temple）、耳前部 | 耳前部の接触部品の頭部輪郭に対する厚さ | 圧迫点が耳内ではなく耳前にあり耳甲介を避けられる。ただし側頭部も薄い皮膚の直下が骨である |

### 4.2.2 イヤーフック型はなぜ横向き寝に構造的に不利なのか

> ⚠️ **本節はシーン A（臥位睡眠）にのみ適用される。**
> **シーン B（座位睡眠）は耳後部を圧迫しないため、以下に述べるイヤーフック型の不利はそのシーンでは成立しない**——4.2.3 参照。
>
> ⛔ **シーン A において、イヤーフック型は高リスク経路である。**
> 現有のスキャンデータは耳介本体のみを含み、**耳後部と乳様突起部（mastoid）を含まない**。加えて需求方が 2026-08-21 に他の利用可能データがないことを確認している。
> **本ガイドラインはイヤーフック型の横向き寝性能について、実測に基づく根拠を一切提供できない——以下はすべて【推論】である。**
> シーン A でイヤーフック型を選ぶ場合、**実機検証を経てからでなければ確定してはならない**。推論は検証ではない。

需求方が 2026-08-21 にイヤーフック型の評価方法を尋ねたため、ここに判断根拠を補足する。

イヤーフック型の利点は睡眠シーンにおいて確かに価値がある：外耳道を塞がない（Part 3 の耳珠と外耳道の敏感領域を回避できる）、通気性が良い、脱落しにくい。

しかし代償は 1 か所に集中する：**耳後部本体である。**

1. **その上に直接横たわることになる。** 横向き寝では耳後部がまさに頭部と枕の間の荷重経路にあたる。
2. **その下は骨である。** 乳様突起部の皮下はすぐ側頭骨の乳様突起であり、軟組織の緩衝がない。耳甲介の軟骨＋軟組織とは異なる。
3. **レバー効果。** 耳後部本体が圧迫されるとフックにモーメントが生じ、力が増幅されて耳輪上縁に加わる。フックが硬いほど増幅は顕著になる。

→ **イヤーフック型を採るなら、設計の要点は：耳後部本体を極限まで薄くする、フックを低剛性とする（レバー化を避ける）、耳介が折れ曲がらないようにする。** カナル型の突出高さ判定基準を流用してはならない。【推論】

### 4.2.2b 市場との対照：業界における耳のサイズ区分

ある市販製品（Soundcore Liberty 3 Pro）の消費者向け選び方ガイドは、耳甲介のサイズを 3 段階に分け、イヤーウィングのサイズに対応させている：

| 測定値 | 推奨ウィング | 同ガイドの説明 |
|---|---|---|
| < 14mm | XS／S | 小さく引き締まった型。大きいウィングは圧迫のリスクがある |
| 14–17mm | S／M | 「大多数の人の範囲」 |
| > 17mm | M／L | 隙間を埋めてレバー支持を得るために大きいウィングが必要 |

**証拠等級：【市場製品統計】、強度は弱い。** 同ページ自身が「絶対的な公式対応表はない」「人間工学の常識に基づく推定であり、メーカーの絶対的な技術仕様ではない」と認めている。

> ⚠️ **その mm 数値を [Part 2](02-anthropometric-basis.md) と混用してはならない。** 同ガイドの「耳甲介腔の垂直高さ」の定義は**耳珠内側縁から耳甲介底部の最深点までの斜線**である——起点が耳甲介前壁の隆起した構造であるため、この線は面内成分と深さ成分の双方を含み、**幾何学的に必ず、椀の縁の平面から下ろした垂直深さより大きくなる**（Part 2.4 の CD、9–10mm）。両者は同じ量ではない。

> ⛔ **これは「耳型区分 → アクセサリサイズ」の対応であり、機種 S／M／L とは無関係である。**
> 同ガイドは終始「この利用者にどのウィングを合わせるか」を述べており、**本体バリエーションにはまったく触れていない**。機種サイズの問いに答えるために用いてはならない。（この箇所では以前、両者を誤って結びつけていた。訂正済み。3 概念の区別は [Part 0.4b](00-scope-and-usage.md) 参照。）

**利用できる点**：**業界が実際に耳のサイズを 3 段階に分けて**異なるサイズの保持部品を合わせていることを裏付ける。これが本ガイドラインでいう**耳型区分 I／II／III** にあたる。**区分の切れ目の根拠としては不十分である。**

> ⚠️ **「手動測定 → 対応表」方式を採る場合、区分の幅は測定不確かさより大きくなければならない。**
> 定規を耳の窪みに差し込む測定の不確かさは約 ±1–2mm【推論、未実測】であり、同ガイドの区分間隔自体も 3mm 刻みにすぎない。**不確かさと区分間隔が同じ桁のとき、測定結果では隣接する区分をほとんど区別できない。**
>
> 加えて [Part 7.0b](07-wearing-pressure-comfort.md)：耳の寸法と主観的な快適性／フィットの相関はもともと有意でないか非常に弱い。
> → **「耳を測ってサイズを選ぶ」を主たる適合機構とすることは推奨しない。** 結果指向の検証（密閉自己テスト、機械的フィットの簡易スクリーニング）に切り替えること。Part 7.4.0 参照。

### 4.2.3 形態選定の比較——**シーン別に示す。順位は反転する**

> ⚠️ **形態の優劣にシーンを横断する万能な答えはない。** 下表の結論は複数の形態で**方向が逆になり**、しかも**座位睡眠内部の 3 つのサブシーン間でも反転する**。選定前にどのシーンとサブシーンを対象とするかを確定しなければならない（[Part 1.0](01-use-scenario.md)、[Part 1A.4.1](01a-posture-analysis.md) 参照）。

**座位睡眠のサブシーン**：**B1 オフィス仮眠**／**B2 短距離通勤**（降車駅を見る必要あり）／**B3 長距離交通**（航空機、高速鉄道、高速バス）

| 形態 | **A 臥位** | **B1 オフィス** | **B2 通勤** | **B3 長距離** | 主な利点 | 主な代償 |
|---|---|---|---|---|---|---|
| カナル型（in-ear） | 中 | 中 | 中 | 良 | 体積が最小で突出を最も制御しやすい | 外耳道と耳珠の敏感領域のリスク（Part 3）。オクルージョン効果（Part 5.4）。**B2 では完全密閉するとアナウンスが聞こえない** |
| **イヤーフック型（ear-hook）** | **高リスク** | **良 ★** | **良 ★** | **良 ★** | 外耳道を塞がない、通気性が良い、**保持が良好** | A：耳後部が骨の上で圧迫される、耳介が折れ曲がる。**座位のすべてのサブシーンでこの代償は消える** |
| フラットオーバーイヤー型 | 中〜高 | 中〜低 | 中 | 良 | 圧力の分散面積が大きい | 総厚さが大きい。音響シミュレーションの信頼帯域が最も低い（Part 5.5）。B1 では外観が目立つ |
| **ヘッドバンド／アイマスク型** | **良 ★** | **低** | 中〜低 | **良 ★★** | 布の緩衝により圧力分散が最良。**B3 では遮光と音響を同時に解決** | A：装置がポケット内で移動する。**B1：オフィスでは社会的に不可。B2：目が覆われ降車駅が見えない** |
| 骨伝導 | 中 | 良 | **良 ★** | 中 | 耳甲介と外耳道を完全に回避。外耳道が開放され環境音の把握が良好 | 側頭部も骨が圧迫される。音響効率と音質に制約 |

#### なぜ順位が反転するのか

**イヤーフック型**：シーン A における唯一の重大な欠点は「耳後部本体が押し潰され、その下が乳様突起部の骨である」ことである（4.2.2 参照）。**座位睡眠は耳後部を圧迫しないため、この欠点は直ちに消える。** そして利点——外耳道を塞がない、通気性が良い、**保持が確実**——は座位でむしろ価値が高まる。居眠り時に頭部が前傾・側方へ倒れるため、保持こそが支配的制約だからである。

**ヘッドバンド／アイマスク型——本表で最も激しく反転し、しかも座位内部でも反転する。**
- **A 臥位で良**：布の緩衝により圧力分散が最良
- **B1 オフィスで低**：同僚がいる場でアイマスクは目立つ
- **B2 通勤で中〜低**：目が覆われ降車駅が見えない
- **B3 長距離で良 ★★**：**長距離交通でアイマスクを着けるのは常態であり（航空会社が自ら配布する）、日中の座位睡眠では環境光が実際の問題となる——アイマスク型は遮光と音響を同時に解決する。これが当該サブシーンにおける固有の優位性である**

その評価は互いに無関係な 3 つの要因に同時に駆動されている：**機械的圧迫**（臥位に有利）、**社会的規範**（オフィスに不利）、**遮光要求**（日中に有利）。**単一のスコアで表現すると実態を歪める。**

> **結論**：シーンを横断する最適解は存在しない。臥位で最良のヘッドバンド／アイマスク型はオフィスで最悪となり、長距離交通で再び最良となる。臥位で最悪のイヤーフック型は座位のすべてのサブシーンで良好である。
> **複数シーンに同時対応する必要がある場合**は**和集合**を取る——イヤーフック型の臥位における問題は、座位で有利であることによって相殺されない。

> **改訂記録**：2026-08-24 以前、本表は座位睡眠を「ヘッドバンド／アイマスク型は実用性が低い」と評価していた。これはオフィスの社会的規範を座位睡眠全体へ一般化し、かつ日中の遮光という機能上の優位性を計上していなかったためである。訂正済み。

⏳ **本表は推論の結果であり実証的裏付けがない**（シーン A は耳後部スキャンデータの欠如により、シーン B は実測が一切ないことによる）。実機を各形態・各シーンで装着比較したうえで修正することを推奨する。【推論】

### 用語：フラッシュ（flush）

**フラッシュ（flush）** ＝ 周囲の面と同じ高さで突出しないこと。元は機構用語（flush mounting＝面一取付）。イヤホンでは、装置の外表面が耳介（auricle）の外縁とおおむね同じ高さにあり、横になったとき枕が装置より先に耳に触れる状態を指す。

> ⚠️ **これはマーケティング用語であり仕様ではない。** メーカーが "flush fit" と称する際、測定基準面も許容誤差も定義しておらず、mm 数も公表していない。**判定可能なしきい値として用いてはならない。**

### 現況：公開された数値の出典がない

市販の睡眠用イヤホン（Ozlo Sleepbuds、Anker Soundcore Sleep A20／A30 等）を調査した結果：

| 発見 | 内容 | 証拠等級 |
|---|---|---|
| メーカーは突出高さの仕様を**公開していない** | マーケティング文は "flush"、"low-profile"、"3D ergonomic" 等の定性的記述のみで mm 数がない | 【市場統計、定性】② |
| 取得できた間接的な数値 | Soundcore Sleep A30 は片耳約 3 g。A20 より「7% 薄い」と称している | 【市場統計、弱】② メーカーのマーケティング資料であり技術仕様書ではない |
| 取得できた定性的な共通認識 | 業界は一致して「耳介（auricle）とフラッシュ／突出しない」ことを横向き寝の設計目標としている | 【市場統計、定性】② |

**「7% 薄い」は相対値であり、基準となる絶対値がなければ mm に還元できない。** これを根拠に推算してはならない。

### 取得方法（推奨する行動）

この数値は**実測するほかない**。方法は形態ごとに異なる：

**共通（すべての形態）**
1. **枕の沈み込み測定**：被験者を実際の枕に横向きに寝かせ、耳介（auricle）のある平面の利用可能な間隙を測定する。これが物理的上限の直接測定である。**枕の種類ごとに測ること**（低反発／羽毛／ラテックスで差が大きい）。
2. **接触圧測定**：薄膜圧力センサを接触面に貼り、横になった状態の実際の界面圧を測定する。**これこそが本当の物理量**であり、突出高さはその代理にすぎない。

**カナル型で追加**
3. 主流の睡眠用イヤホンを 2–3 機種購入し、ノギス（vernier caliper）で装着状態における耳介最高点に対する突出高さを測定する。「市場製品統計」の出典種別にあたる。

**イヤーフック型で追加**
4. 頭部側面輪郭に対する最外縁の厚さ
5. 耳後部本体の乳様突起部（mastoid）への接触圧（当該部位は薄い皮膚の直下が骨であるため、別途測定する）
6. 横になったとき耳介が折れ曲がるか——撮影または圧痕の確認で足りる

各項目のうち最も厳しい値を採る。

**実測値を得るまで、本ガイドラインは突出高さの数値を一切記入しない。** このパラメータは全案に影響するため、推測値を埋めるほうが空欄より危険である——空欄は問い合わせを招くが、推測値はそのまま根拠として引き継がれる。

---

## 4.3 交差の規則

1. まず解剖学的境界で、耳の内側における本体の**収容体積**を定める
2. 次に横向き寝境界で、耳の外側における本体の**突出高さ**を定める
3. 両者が衝突する場合、**横向き寝境界を優先する**——収まらないなら小さくするか形態を変えればよいが、突出が超過すれば製品として成立しない
4. **機種 S／M／L の 3 段階は同一の解剖学的境界と横向き寝境界を共有する**——境界は利用者の耳と枕が決めるものであり、本体サイズによって変わらない。3 段階の違いは、エンベロープ内でどこまで大きくするかの選択にある

---

## 4.4 未取得リスト

| 欠落 | 取得方法 | 阻害度 |
|---|---|---|
| **横向き寝の突出高さ上限** | 競合品の実測＋枕の沈み込み実測 | **最高。** 全案の重要パラメータ |
| アジア成人の**性別別の耳介外形**エンベロープ | 出典① が引用する原著研究を追跡するか、人口統計を伴う 3D スキャンを取得する | 中。耳介外形は【実測】があり耳甲介は性別別【文献】がある。欠けているのは両者の交差 |
| 機種 S／M／L 3 段階の**目的** | 需求方の確認（機能トレードオフか製品ライン差別化か） | 高。機種-L をエンベロープ上限まで攻めるべきかが決まる |
| 外耳道（ear canal）深部の寸法 | 公開文献の多くが含まない。実測または耳型（ear impression）が必要 | 中 |
| 横向き寝で圧迫されたときの耳介（auricle）の変形量 | 実測のみ | 中。動的な間隙に影響する |

---

## 出典

① Fu, F., Luximon, Y. **A systematic review on ear anthropometry and its industrial design applications.** *Human Factors and Ergonomics in Manufacturing & Service Industries*, 2020, 30: 176–194. DOI: [10.1002/hfm.20832](https://doi.org/10.1002/hfm.20832) ｜ 無料全文：<https://ira.lib.polyu.edu.hk/bitstream/10397/89894/1/a0733-n14_1220_hfm.pdf>
　種別：学術論文。**ダウンロードして原文を読解のうえ確認済み。**

② 市販の睡眠用イヤホンの公開製品情報（Ozlo Sleepbuds、Anker Soundcore Sleep A20／A30 等のメーカーページとメディアレビュー）。
　種別：市場製品統計。**強度は弱い——メーカーのマーケティング記述と第三者レビューであり技術仕様書ではない。しかも肝心の突出高さの数値は非公開である。** 「業界がこの数値を公開していない」「フラッシュが共通の設計目標である」の 2 点を裏付けるためにのみ用い、数値の根拠としては用いない。

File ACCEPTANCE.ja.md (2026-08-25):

# 受入基準——このガイドラインはどこまでできれば完成か

ステータス：初稿 ｜ 最終更新 2026-08-25

> 🌐 中文版：[ACCEPTANCE.md](ACCEPTANCE.md)

**この文書は設計者向けではない。** 設計者は [GUIDELINE.ja.md](GUIDELINE.ja.md) を読む。これは受入側のための文書であり、第一段階の納品物を受け取ってよいかを判定するものである。

---

## 1. なぜ先に「完成」を定義するのか

受入基準がない場合、ガイドライン類の納品物は 2 方向に壊れる。しかもどちらも自然には表面化しない：

| 失敗モード | どう見えるか | なぜ気づかれないか |
|---|---|---|
| **無限延長** | 次に当たるべき文献、次に埋めるべき数値が常にあり、納期が繰り返し後ろへずれる | 個々の延期は単独で見ればすべて妥当に見える |
| **偽の完成** | 章立ては揃い、数値も埋まり、専門的に見える。しかし一部は推測である | 推測値と実測値は紙面上まったく同じ見た目になる |

本案件の証拠等級（【実測】【文献】【慣例】【推論】【仮定】）が扱うのは後者である。**受入基準が扱うのは前者であり、同時に後者を機械的に検査可能な条件へ変換する。**

---

## 2. 2 種類の基準を混ぜてはならない

これが本文書の中核的な主張である。

| | **形式基準（F）** | **妥当性基準（V）** |
|---|---|---|
| 何を問うか | この文書自体が合格か | この文書に従って作ったものが使えるか |
| いつ判定できるか | **今日、文書を見れば判定できる** | **実機の試作品と装着試験が必要** |
| 判定方法 | 多くはスクリプトで自動検査できる | 人体を用いた試験 |
| 第一段階では | **全項目の通過が必須** | **判定不可能** |

> ⛔ **第一段階の合格 ＝ F を全項目通過 ＋ V をすべて未検証として明示的に登録すること。**
>
> **F の通過はガイドラインが正しいことを意味しない。** 誠実であり、かつ実行可能であることを意味するにすぎない。F の通過を「検証済み」と言い換えれば、実施していない検証を実施したと述べることになる——それはまさに本案件の証拠等級が防ごうとしていることであり、受入の層でそれを崩してはならない。

第一段階が約束できる最も強い言い方は次である：**「これは工学的根拠のある設計の出発点であり、どこに根拠があり、どこにないかをすべて明示してある」**。「従えば快適になる」は約束できない。

---

## 3. 形式基準

各項目に**判定方法**を付す。判定方法は他者が再実行できるものでなければならず、こちらの自己申告であってはならない。

### F1 判定可能性——各ルールが 3D モデルに対して可否を判定できること

GUIDELINE.ja.md の各ルールは、次の 3 類型のいずれかに属さなければならない：

- **(a) 数値しきい値**——例：肉厚 ≥1.0mm、サポート不要オーバーハング角 ≤45°
- **(b) 明確な禁止**——禁止対象が指し示せること。例：荷重を受ける保持構造を耳珠（tragus）に置いてはならない
- **(c) ⏳ を付し取得方法を示す**——例：横向き寝時の突出高さ上限（測定手順を示す）

**不合格となるのは形容詞ルールである**：「できるだけ薄く」「接触面は快適であること」——モデルに対して可否を判定できない。

**判定方法**：GUIDELINE.ja.md のルールを逐条で列挙・分類し、3 類型に入らない条数が **0** であること。
**現況**：逐条の測定は未実施。⛔ 受入前に一度、完全な分類を行う必要がある。

### F2 追跡可能性——すべての数値が出典に辿れること

- すべての数値に証拠等級（【実測】【文献】【慣例】【推論】【仮定】）が付されている
- すべての → Part X リンクが実在する節に解決する
- すべての【文献】に DOI または到達可能なリンクがあり、**当チームが実際に原文を開いている**（検索要約からの推測は認めない）

**判定方法**：リンク解決率をスクリプトで検査。数値の等級表示は人手で抜き取り検査。【文献】は既検証出典リストと逐一照合。
**現況**：節リンクは **86/86 解決・破損 0**（検証済）。数値の等級表示と文献の検証状態は**全面的な再点検が未実施**。

### F3 網羅性——設計者が下すべき決定に、すべて行き先があること

最も漏れやすく、かつ明確な土台を必要とする項目である。**土台は「設計決定リスト」**——設計者がゼロから造形可能な睡眠用イヤホンの 3D モデルを作るまでに、どの決定を下さねばならないか。リスト各項に対し、ガイドラインは次のいずれかを与えなければならない：

- **ルール**（数値しきい値または明確な禁止を伴う）
- **方法**（本ガイドラインは数値を与えないが、数値を得る手順を与える。⏳ を付す）
- **欠落として登録**（出せないと明言し、その理由を述べる）

> ⛔ **「言及していない」は許されない。** 言及がなければ「制約がない」と読まれる。**沈黙は許可と読まれる**——これがガイドライン類文書で最も多い失効の形である。

リストは第 4 節に示す。**判定方法**：リスト各項に網羅状態を付し、「未網羅かつ未登録」の項目数が **0** であること。

### F4 境界の明示——何を除外したかを述べること

適用範囲と明示的な除外項目が本文（注記ではなく）に書かれており、読者が「本文書に記載がない」を「制約がない」と読み違えないこと。

**判定方法**：[Part 0.2](jp/00-scope-and-usage.md#sec-0-2) の除外リストと第 4 節の欠落リストを照合し、両者の和集合が「ガイドラインが答えない項目」をすべて覆っていること。
**現況**：Part 0.2 と [Part 0.6](jp/00-scope-and-usage.md#sec-0-6) は記載済。**設計決定リストとの照合は未実施。**

### F5 無矛盾——章と章が衝突しないこと

異なる章の制約が互いに矛盾しないこと。2 つのシーンが逆方向の要求を出す場合は、**衝突の存在を明言し、処理規則を示さなければならない**（本ガイドラインの現行の処理規則は「複数の姿勢を同時に扱う場合は制約の和集合を取る」である）。

**判定方法**：各章の数値しきい値と禁止項目を相互比較する。特に、形態の評価が姿勢間で反転する箇所すべてに前提が明示されているかを確認する。
**現況**：既知かつ処理済の衝突が 2 箇所（イヤーフック型と、ヘッドバンド／アイマスク型の順位が姿勢間で反転する。[Part 4.2.3](jp/04-max-design-envelope.md#sec-4-2-3) 参照）。**全面的な相互比較は未実施。**

### F6 ★ 独立実行可能性——これが真の完成定義である

前 5 項をすべて通過しても、誰にも使えない文書が出来上がりうる。**本案件はすでにこの誤りを犯している**：証拠規律を厳格にした結果、各章で制約の注意書きが数値より多くなり（Part 1 は数値 0 条に対し注意書き 14 条）、実行可能な内容が方法論の議論の下に埋もれた。発注者が Part 1 を読み終えての反応は「結局ガイドラインが何なのか分からない」であった。GUIDELINE.ja.md はこの問題を修正するために切り出したものである。

したがって、自己評価に依存しない判定基準が必要である：

> **本案件に関与していない設計者に GUIDELINE.ja.md だけを渡し、口頭の補足を一切行わず、造形可能な 3D モデルを作ってもらう。**
>
> **「ガイドラインが本来答えるべきだったのに答えておらず、そのために質問せざるを得なかった」件数を数える。この数が 0 であれば完成とする。**

計数規則（後の争いを避けるため先に定める）：

| 数える | 数えない |
|---|---|
| ガイドラインが扱うと称しているのに、実際には答えが見つからない | ガイドラインが欠落として明示登録済みの項目（自分で測ると分かっている＝想定内の挙動） |
| 記載はあるが可否を判定できない（形容詞ルール） | ガイドラインの職掌ではなく製品判断に属するもの（例：この機種にアクティブノイズキャンセリングを載せるか） |
| 2 箇所の記述が矛盾し、どちらに従うべきか分からない | 設計者自身の技能の問題（例：CAD ソフトを扱えない） |

**関与していない設計者を確保できない場合**：次善策として、チーム内で分章を読んでいない者が代行し、受入記録に**弱化版の判定である**と明記する。彼に欠けているのは真の外部視点であるから、通過のしきい値はより厳しくすべきである（例：「見つかったが時間がかかった」も記録させる）。

**現況**：未実施。

### F7 ★ 分野横断のクロスチェック——F6 でも検出できない種類の誤り

**F6 は「答えるべきなのに答えていない」を測り、[GOAL の S2](GOAL.ja.md) は「答えているが方向が逆」を測る。第三の種類がある：答えており、方向も正しく、しかし内容が誤っているもの。** これは F6 では検出できない——設計者は質問せず、誤った記述のとおりに作ってしまう。

根拠は推測ではない。2026-08-25 の分野横断的な条文執筆において、チーム内の相互チェックで検出された誤りには次がある：調律周波数が存在しない密閉型アーキテクチャにヘルムホルツ共鳴の関係式を適用（式は正しく、アーキテクチャの適用先が誤り）／式に代入して算出した値を【実測】と表示／最小フィーチャ寸法（0.5mm）を最小孔径（実際は 2.0mm、断面積で約 16 倍差）と取り違え／孔配列が音響的に独立かを中心距離/波長で判定（正しい尺度は中心距離/孔半径）／「閉塞は検出できる」を完全閉塞から部分減衰へ過度に一般化。**いずれも設計者に疑問を抱かせない。**

**判定方法**：分野横断的な条文（その成立が他分野のデータまたはモデルに依存するもの）はすべて、当該分野以外の第二者が査読し記録を残すこと。**クロスチェックを経ていない分野横断条文の数が 0 であること。**
**現況**：⚠️ 実務上は行われているが、**制度化されておらず記録も残っていない。**

> ⛔ **F7 の適用範囲——明記しないと過信される。**
>
> 上記の誤りには共通点がある：**すべて他分野の領域にまたがっている**（最小孔径は製造、ヘルムホルツの誤適用はアーキテクチャ、フェイルセーフは安全工学、520 Hz は法規）。またがっているからこそ、相手側に**指摘する立場と能力の両方があった**。
>
> **分野内部で完結する誤りは F7 では捕まえられない。** 例：音響章の開口端補正係数を取り違えても、機構側にはそれを疑う立場がなく、PM は整合性を検算できても正しさは検算できない——**一貫して誤っていても誤りであり、しかもより信頼できるように見える。**
>
> この種の唯一の防御線は**外部出典との照合**（[F2](#f2) の引用規律）である。
> **2 つは相補的であり重複しない：F7 は分野横断の誤りを、F2 は分野内部の誤りを止める。** 一方で他方を代替してはならない。

---

## 4. 設計決定リスト——F3 の判定土台

設計者がゼロから造形可能なモデルに至るまでに決めねばならない項目。**網羅状態は今回の棚卸し結果であり、既存文書の自己申告ではない。**

| # | 設計決定 | 現況 | 位置／説明 |
|---|---|---|---|
| 1 | 形態の選択（インイヤー／イヤーフック／扁平オンイヤー／ヘッドバンド・アイマスク／骨伝導） | ✅ ルール | GUIDELINE D。姿勢別の比較表を含む |
| 2 | どの睡眠姿勢に対応するか | ✅ **確定済** | **一晩の臥位睡眠（仰臥／左右横臥）。** 座位睡眠は第一段階から除外。[GOAL 第 1 節](GOAL.ja.md) 参照 |
| 3 | 保持方式と保持点の位置 | ✅ ルール | GUIDELINE B（配置禁止領域＋耳輪／対耳輪への変更） |
| 4 | 本体外形エンベロープ | ✅ ルール | GUIDELINE A（解剖学的エンベロープ）＋ 3 機種とも全耳型範囲を収容 |
| 5 | 横向き寝時の突出高さ | ⏳ 方法 | 欠落として登録済、測定手順を提示済 |
| 6 | **接触面のフィレット半径と接触面積** | ⏳ **判定可能な形式へ書き換え済** | **各接触パッチが個別に A_i ≥ F_i / PDT(当該部位) を満たすこと**（合計ではなくパッチ単位）。唯一の不足：**PDT 絶対値の部位別表** |
| 7 | 接触面の材料と硬度 | ✅ ルール | GUIDELINE F（目標 Shore A 10–20、造形下限 43） |
| 8 | 硬質シェルの材料と肉厚 | ✅ ルール | GUIDELINE F |
| 9 | 音響の前後キャビティ容積 V_front／V_back | ⚠️ 部分的 | 定義と境界は明確だが、**容積の数値がない**（[Part 5.1](jp/05-acoustic-constraints.md#sec-5-1) に未取得と明記）。ドライバ選定後に自ら算出する必要がある |
| 10 | **音導孔とダクトの形状** | ⏳ **判定可能な形式へ書き換え済** | 開放式：f₀ と V を定め A/L_eff を逆算。密閉式：選べる f₀ は存在せず、制約は容積収支と高域上限から来る。唯一の不足：密閉式の**挿入後の残存外耳道容積** |
| 11 | 漏れ経路の形状（密閉／非密閉） | ✅ ルール | GUIDELINE E。顎の状態の明記要求を含む |
| 12 | **付属品（イヤーチップ／イヤーウィング）のサイズ系列の設計** | ⚠️ **部分的** | 「耳を測ってサイズを選ぶ」方式は明確に**否決**し、結果指向の検証に変更済（[Part 4.2.2b](jp/04-max-design-envelope.md#sec-4-2-2b)、[Part 7.4.0](jp/07-wearing-pressure-comfort.md#sec-7-4-0)）。しかし**何サイズ用意し、間隔をいくつにするか**のルールがない |
| 13 | 左右非対称への対処 | ✅ ルール | GUIDELINE H（角度系寸法は左右非対称。角度を持つ保持部品を左右共通と仮定してはならない） |
| 14 | 造形プロセス、配置方向、サポート戦略 | ✅ ルール | GUIDELINE F（オーバーハング角、最小フィーチャ、サポートの取り出し可能性） |
| 15 | 部品分割と組立方式 | ⚠️ 部分的 | [Part 6.G](jp/06-structure-materials.md#sec-6-g) にあり（スナップフィット／接着／ねじ）。**GUIDELINE 未収録** |
| 16 | 表面処理と光沢 | ⚠️ 部分的 | [Part 8.2](jp/08-cmf.md#sec-8-2)、[8.3](jp/08-cmf.md#sec-8-3) にあり。**GUIDELINE は触覚識別のみ収録し、低光沢と洗浄との衝突が漏れている** |
| 17 | インジケータの位置と輝度 | ✅ ルール | GUIDELINE G（スリープモードで全消灯。必要な場合は 6 lux を基準） |
| 18 | 触覚識別のフィーチャ（左右／表裏） | ✅ ルール | GUIDELINE G |
| 19 | マイクによる密閉自己診断（マイク搭載時） | ✅ ルール | GUIDELINE H（比較式プロトコルを推奨） |
| 20 | 洗浄方法との適合性 | ⚠️ 部分的 | [Part 6.E](jp/06-structure-materials.md#sec-6-e) にあり（IPA による白化・硬化）。**GUIDELINE 未収録** |
| **21** | **電源予算 vs 利用可能な容積** | ⛔ **今回新たに判明した欠落（2026-08-25）。従来まったく扱われていなかった** | 一晩 6〜9 時間に必要な電池容量 vs 耳甲介深さ平均 9.15mm から肉厚とドライバを差し引いた正味空間。**インイヤー型を直接否決しうる——快適性の問題ではなく、収まらないという問題である。** さらに電池と後気室 V_back が同じ容積を奪い合い、V_back を圧縮すれば低域を犠牲にする。唯一の不足：**部品候補リスト**（有料文献は不要。製品側が選定方針を示せばよい） |

**棚卸し結果（2026-08-25 更新）：完全網羅 12／判定可能な形式へ書き換え済で単一の数値待ち 2（第 6・10 項）／部分的 4（第 9・15・16・20 項）／未網羅 1（第 21 項）。**

> ⛔ **F3 は依然として不合格**だが、性質が変わった：
> 1. **第 6・10 項は「空白」から「判定可能な形式 ＋ 不足している量の特定」へ書き換えた。** 空白は制約がないと読まれるが、判定可能な形式なら欠落が調達・実測できる明確な目標になる。**ただし格下げは解決ではない**——数値が埋まるまで実際には判定できない。
> 2. **第 21 項は今回新たに判明したもので、従来の 20 項リストが完全に見落としていた。** これはリスト自体にもクロスチェックが要ることを示している（F7 参照）。
> 3. **第 15・16・20 項**は章に既存の内容を GUIDELINE が拾えていないだけであり、編集レベルで足りる。

---

## 5. 妥当性基準（第二段階。現時点では登録のみで判定しない）

現時点では判定できないが、**今のうちに書き留めておく必要がある。** そうしないと、第一段階の納品後に「検証済み」と受け取られやすい。

| 記号 | 基準 | 判定に必要なもの |
|---|---|---|
| **V1** | 本ガイドラインに従って作ったモデルが実機の装着試験に合格する | 試作機＋被験者。試験設計は [GUIDELINE](GUIDELINE.ja.md) H 節に記載済（右側臥の加重、高齢被験者の参加、口を開けた状態、長時間の静的圧迫を含むこと） |
| **V2** | すべての ⏳ 項目に実測値が入る | 競合製品の測定＋枕の沈み込み測定＋薄膜圧力センサ |
| **V3** | ガイドライン自身の予測が実測と一致する | 例：信頼できる周波数上限以下で、集中定数モデルの予測が実測応答と一致すること。**これは数値を埋めるだけでなく、ガイドラインが嘘をついていないかを検査する** |

> V3 は省略されがちだが、「ガイドライン自体」を逆向きに検証できる唯一の項目である。前 2 項は空欄を埋めているにすぎない。

---

## 6. 完全な定義を妨げている事項

**当初これを妨げていた「どのシーンに対応するか」は 2026-08-25 に確定した**（一晩の臥位睡眠、座位睡眠は除外）。これに伴い「イヤーフック型を本気の候補とするか」も実質的に解決した（候補から外れる）。残るのは次の 4 件である：

| 未決事項 | 受入基準への影響 | 取得コスト |
|---|---|---|
| **「安全上重要な音で目覚められること」を必須要件とするか** | 最大。必須ならアーキテクチャが収束し（密閉型が制限され、通気孔が安全部品へ格上げ）、閉塞防止の条項群と検収方法が新たに加わる → [GOAL 5.1](GOAL.ja.md#sec-5-1) | 製品層の裁定。費用なし |
| **一晩中マスキング音を流すか** | 受動遮音の下限の厳しさが決まる——流すならマスキング自体が遮音の仕事をする | 製品層の裁定。費用なし |
| **部品候補リスト** | 第 21 項を閉じる。電源予算と音響容積予算は連立で解く必要がある | 製品側が選定方針を示せばよい。有料文献は不要 |
| **機種 S／M／L で何を差別化するか** | 第 4 項に独立した 3 組のエンベロープ数値が必要かが決まる | 製品層の裁定 |

**4 件とも製品層の裁定であり、費用も実験も要らない。** 対して PDT 絶対値と横向き寝の突出高さは、有料文献または実測を要する。

---

## 7. この基準自体の限界

- **F6 には関与していない設計者が 1 名必要である。** これは方法の問題ではなく資源の問題だが、その人がいなければ第一段階の完成判定は弱化版にとどまる。
- **F1 と F3 の判定には人の判断が含まれる**（「これは形容詞ルールに当たるか」「これは独立した 1 つの決定か」）。境界はできる限り示したが、完全な機械化はできない。判定は本文書の作成者以外が行うことを推奨する。
- **第 4 節のリストは当チームが作成した【推論】であり**、業界標準の設計決定分解ではない。受入側が独自のリストを持つ場合は**そちらを優先すること**。本リストの価値は「どこに行き先がないか」を炙り出す点にあり、リスト自体の権威性にはない。

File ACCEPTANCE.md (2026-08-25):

# 驗收基準——這份指引做到什麼程度才算完成

狀態：初稿 ｜ 最後更新 2026-08-25

> 🌐 日本語版：[ACCEPTANCE.ja.md](ACCEPTANCE.ja.md)

**這份文件不是給設計者的。** 設計者讀 [GUIDELINE.md](GUIDELINE.md)。這份是給驗收方的：判斷第一階段交付物可不可以收。

---

## 1. 為什麼需要先定義「完成」

沒有驗收基準時，指引類交付物會往兩個方向壞掉，而且兩種都不會自己浮現：

| 失敗模式 | 長什麼樣 | 為什麼不會被發現 |
|---|---|---|
| **無限延伸** | 永遠有下一份文獻可查、下一個數字可補，交付日一再後延 | 每一次延後單獨看都合理 |
| **假完成** | 章節齊全、數字填滿、看起來專業，但其中一部分是猜的 | 猜測值與實測值在版面上長得一模一樣 |

本專案的證據分級（【實測】【文獻】【慣例】【推論】【假設】）處理的是第二種。**驗收基準處理的是第一種，並且把第二種變成可機械檢查的條件。**

---

## 2. 兩類基準不可混為一談

這是本文件的核心主張。

| | **形式基準（F）** | **妥當性基準（V）** |
|---|---|---|
| 問什麼 | 這份文件本身合格嗎 | 照這份文件做出來的東西好用嗎 |
| 何時可判定 | **今天，對著文件就能判** | **要有實體樣機與試戴試驗** |
| 判定方式 | 多數可寫成腳本自動檢查 | 人體試驗 |
| 第一階段 | **必須全數通過** | **不可能判定** |

> ⛔ **第一階段的合格 ＝ F 全數通過 ＋ V 全部被明確登記為未驗證。**
>
> **通過 F 不代表這份指引是對的**，只代表它誠實且可執行。若把 F 通過講成「指引已驗證」，就是把沒做過的驗證講成做過了——這正是本專案證據分級要防的事，不能在驗收層級破功。

第一階段能承諾的最強說法是：**「這是一個有工程依據的設計起點，其中哪些有依據、哪些沒有，全部標清楚了。」** 不能承諾「照做就會舒服」。

---

## 3. 形式基準

每條都附**判定方法**，判定方法必須是別人可以重跑的，不是我說了算。

### F1 判定可能性——每條規則都能對著 3D 模型判對錯

GUIDELINE.md 中的每一條規則，必須屬於下列三類之一：

- **(a) 數值門檻**——例：壁厚 ≥1.0mm、免支撐懸空角 ≤45°
- **(b) 明確禁止**——禁止的對象可指認，例：承重固位結構不得放在耳屏（tragus）
- **(c) 標記 ⏳ 並附取得方法**——例：側睡凸出高度上限（給量測程序）

**不合格的是形容詞規則**：「應盡量輕薄」「接觸面應舒適」——無法對著模型判對錯。

**判定方法**：逐條列舉 GUIDELINE.md 的規則並歸類，三類之外的條數必須為 **0**。
**現況**：未逐條測定。⛔ 驗收前必須做一次完整歸類。

### F2 追溯性——每個數字都能查到來源

- 每個數值標了證據等級（【實測】【文獻】【慣例】【推論】【假設】）
- 每條 → Part X 連結解析得到實際存在的章節
- 每個【文獻】有 DOI 或可達連結，**且本團隊確實開啟過原文**（不接受從檢索摘要推斷）

**判定方法**：腳本檢查連結解析率；人工抽查數值標記；【文獻】逐筆對照已核驗來源清單。
**現況**：章節連結 **86/86 解析成功、0 壞連結**（已驗）。數值標記與文獻核驗狀態**未全面複查**。

### F3 網羅性——設計者要做的決策，每一個都有著落

這是最容易漏、也最需要一個明確基礎的一條。**基礎是「設計決策清單」**：一位設計者要從零產出一個可列印的睡眠耳機 3D 模型，必須做出哪些決策。清單中每一項，指引必須給出下列之一：

- **規則**（有數值門檻或明確禁止）
- **方法**（本指引不給數值，但給取得數值的程序，標 ⏳）
- **登記為缺口**（明講給不出來，並說明為什麼）

> ⛔ **不可以是「沒提到」。** 沒提到會被讀成「沒有限制」。**沉默即許可**是指引類文件最常見的失效方式。

清單見第 4 節。**判定方法**：清單每一項標記涵蓋狀態，「未涵蓋且未登記」的項數必須為 **0**。

### F4 邊界明示——排除了什麼要講出來

適用範圍與明確排除項寫在正文（非附註），且讀者不會把「本文件沒講」誤讀為「沒有限制」。

**判定方法**：對照 [Part 0.2](cn/00-scope-and-usage.md#sec-0-2) 的排除清單與第 4 節的缺口清單，兩者聯集須涵蓋所有「指引不回答」的項目。
**現況**：Part 0.2 與 [Part 0.6](cn/00-scope-and-usage.md#sec-0-6) 已寫。**與設計決策清單的對照未做。**

### F5 無矛盾——章與章之間不打架

不同章節的約束不得互相衝突；若兩個情境給出方向相反的要求，**必須明講衝突存在並給出處理規則**（本指引目前的處理規則是「同時服務多姿勢時取約束聯集」）。

**判定方法**：交叉比對各章的數值門檻與禁止項；重點查形態選型評分在不同姿勢間翻轉的段落是否都標明了前提。
**現況**：已知並已處理的衝突有兩處（掛耳式、頭帶眼罩式在姿勢間排序翻轉，見 [Part 4.2.3](cn/04-max-design-envelope.md#sec-4-2-3)）。**全面交叉比對未做。**

### F6 ★ 獨立可執行性——這才是真正的完成定義

前五條全部通過，仍可能交出一份沒人用得動的文件。**本專案已經犯過這個錯**：證據紀律做得嚴，結果每一章的限制警語都比數字多（Part 1 是 0 條數值對 14 條警語），可執行的內容被埋在方法學討論底下，需求方讀完 Part 1 的反應是「還是不知道指引是什麼」。GUIDELINE.md 就是為了修這個問題才拆出來的。

所以要有一條不依賴自我評估的判準：

> **把 GUIDELINE.md 交給一位沒有參與本專案的設計者，只給文件、不做口頭補充，請他產出一個可列印的 3D 模型。**
>
> **計算「指引本來應該回答、卻沒有回答，導致他必須來問」的問題數。這個數字為 0，即為完成。**

計數規則（先講清楚，避免事後爭議）：

| 算數 | 不算數 |
|---|---|
| 指引宣稱涵蓋、但實際查不到答案 | 指引已明確登記為缺口的項目（他知道要自己量，這是預期行為） |
| 指引講了但無法判定對錯（形容詞規則） | 屬於產品決策而非指引職責（例：這款要不要做主動降噪） |
| 兩處說法矛盾、他不知道該聽哪個 | 他自己的專業能力問題（例：不會用 CAD 軟體） |

**若找不到未參與的設計者**：退而求其次，由團隊中未讀過分章的成員代作，並在驗收記錄中註明此為**弱化版判定**——他缺的是真正的外部視角，通過門檻應更嚴（例如要求連「查得慢」也記錄下來）。

**現況**：未執行。

### F7 ★ 跨領域交叉檢查——F6 也測不到的一類錯誤

**F6 測「該答沒答」，[GOAL 的 S2](GOAL.md) 測「答了但方向反了」。還有第三類：答了、方向也對、但內容是錯的。** 這一類 F6 完全測不到——設計者不會提問，他會照著錯的寫法做出東西。

依據不是推測。2026-08-25 一輪跨章條文撰寫中，由團隊成員互相檢查抓出的錯誤包括：把亥姆霍茲共振關係套用到沒有調諧頻率的密封式架構（公式正確、架構套錯）；把公式代入算出的數值標為【實測】；把最小特徵尺寸（0.5mm）當作最小孔徑（實為 2.0mm，截面積差約 16 倍）；以中心距/波長判定孔陣是否聲學獨立（正確尺度是中心距/孔半徑）；把「阻塞可偵測」從完全堵死過度推廣到部分衰減。**沒有任何一項會讓設計者產生疑問。**

**判定方法**：每一條跨領域條文（其成立依賴另一領域的數據或模型者），須經該領域以外的第二位審閱並留下記錄。**未經交叉檢查的跨領域條文數必須為 0。**
**現況**：⚠️ 已於實務中執行，**但未制度化、未留記錄**。

> ⛔ **F7 的覆蓋邊界——不寫明會被過度信任。**
>
> 上列錯誤有一個共同點：**全部跨到另一個領域的地盤上**（最小孔徑屬製造、亥姆霍茲誤套屬架構、fail-safe 屬安全工程、520 Hz 屬法規）。正因為跨界，另一邊才**既有立場也有能力**看出來。
>
> **純領域內的錯誤，F7 抓不到。** 例：聲學章的開口端修正係數若記錯，機構端沒有立場質疑，PM 只能核算一致性而非正確性——**一致地錯仍然是錯，而且看起來更可信**。
>
> 這一類的唯一防線是**對外部來源核驗**（[F2](#f2) 的引用紀律）。
> **兩條互補、不重疊：F7 擋跨界錯，F2 擋領域內錯。** 不可用其中一條代替另一條。

---

## 4. 設計決策清單——F3 的判定基礎

一位設計者從零做到可列印模型，必須決定的項目。**涵蓋狀態為本次盤點結果，非既有文件的自我宣告。**

| # | 設計決策 | 現況 | 位置／說明 |
|---|---|---|---|
| 1 | 形態族選擇（入耳／掛耳／扁平耳罩／頭帶眼罩／骨傳導） | ✅ 規則 | GUIDELINE D，含姿勢別比較表 |
| 2 | 服務哪些睡姿 | ✅ **已裁定** | **整夜臥睡（仰臥／左右側臥）**，坐睡移出第一階段。見 [GOAL 第 1 節](GOAL.md) |
| 3 | 固位方式與固位點位置 | ✅ 規則 | GUIDELINE B（禁置區＋改用耳輪／對耳輪） |
| 4 | 機體外形包絡 | ✅ 規則 | GUIDELINE A（解剖包絡）＋ 三機型皆須容納全耳型範圍 |
| 5 | 側睡凸出高度 | ⏳ 方法 | 已登記為缺口並給量測程序 |
| 6 | **接觸面圓角半徑與接觸面積** | ⏳ **已改為可判定形式** | **每一接觸斑塊各自滿足 A_i ≥ F_i / PDT(該部位)**（逐斑塊非總和）。唯一待補：**PDT 絕對值分區表** |
| 7 | 接觸面材料與硬度 | ✅ 規則 | GUIDELINE F（目標 Shore A 10–20；列印下限 43） |
| 8 | 硬殼材料與壁厚 | ✅ 規則 | GUIDELINE F |
| 9 | 聲學前後腔容積 V_front／V_back | ⚠️ 部分 | 定義與邊界清楚，**無容積數值**（[Part 5.1](cn/05-acoustic-constraints.md#sec-5-1) 明載未取得），須驅動器選型後自算 |
| 10 | **出音孔與導管幾何** | ⏳ **已改為可判定形式** | 洩壓式：定 f₀ 與 V 反解 A/L_eff。密封式：無可選 f₀，約束來自容積帳與高頻上限。唯一待補：密封式的**插入後殘餘耳道容積** |
| 11 | 漏氣路徑幾何（密封／非密封） | ✅ 規則 | GUIDELINE E，含須註明下顎狀態 |
| 12 | **配件（耳塞／耳翼）尺寸系列設計** | ⚠️ **部分** | 已明確**否決**「量耳朵挑尺寸」並改採結果導向驗證（[Part 4.2.2b](cn/04-max-design-envelope.md#sec-4-2-2b)、[Part 7.4.0](cn/07-wearing-pressure-comfort.md#sec-7-4-0)）；但**要做幾個尺寸、彼此差多少**沒有規則 |
| 13 | 左右不對稱處理 | ✅ 規則 | GUIDELINE H（角度類尺寸左右不對稱，帶角度固位件不可假設通用） |
| 14 | 列印製程、擺放方向、支撐策略 | ✅ 規則 | GUIDELINE F（懸空角、最小特徵、支撐須取得出來） |
| 15 | 分件與組裝方式 | ⚠️ 部分 | [Part 6.G](cn/06-structure-materials.md#sec-6-g) 有（卡扣／膠合／螺絲），**GUIDELINE 未收錄** |
| 16 | 表面處理與光澤 | ⚠️ 部分 | [Part 8.2](cn/08-cmf.md#sec-8-2)、[8.3](cn/08-cmf.md#sec-8-3) 有，**GUIDELINE 只收了觸覺辨識，漏了低光澤與清潔衝突** |
| 17 | 指示燈位置與亮度 | ✅ 規則 | GUIDELINE G（睡眠模式全滅；必須亮則以 6 lux 為準） |
| 18 | 觸覺辨識特徵（左右／正反） | ✅ 規則 | GUIDELINE G |
| 19 | 麥克風密封自測（若有麥克風） | ✅ 規則 | GUIDELINE H（建議比較式協定） |
| 20 | 清潔方式相容性 | ⚠️ 部分 | [Part 6.E](cn/06-structure-materials.md#sec-6-e) 有（IPA 使表面白化硬化），**GUIDELINE 未收錄** |
| **21** | **電源預算 vs 可用體積** | ⛔ **新發現的缺口（2026-08-25），先前完全未涵蓋** | 整夜 6–9 小時所需電池容量 vs 耳甲深度平均 9.15mm 扣掉壁厚與驅動器後的淨空間。**可能直接否決入耳式——不是舒適問題，是塞不下。** 且電池與後腔 V_back 搶同一塊體積，壓縮 V_back 會犧牲低頻。唯一待補：**元件候選清單**（不需付費文獻，只需產品端給選型方向） |

**盤點結果（2026-08-25 更新）：完全涵蓋 12／已改為可判定形式待補單一數字 2（第 6、10 項）／部分 4（第 9、15、16、20 項）／未涵蓋 1（第 21 項）。**

> ⛔ **F3 仍不通過**，但性質已改變：
> 1. **第 6、10 項已從「留白」改寫為「可判定形式 ＋ 標出唯一缺的量」。** 留白會被讀成沒有限制；可判定形式讓缺口變成可採購、可實測的明確目標。**但降級不等於關閉**——數字填上前仍無法真正判定。
> 2. **第 21 項是本輪新發現，先前二十項清單完全漏掉。** 這證明清單本身也需要交叉檢查（見 F7）。
> 3. **第 15、16、20 項**是 GUIDELINE 沒收錄章節既有內容，屬編輯層級。

---

## 5. 妥當性基準（第二階段，現在只登記不判定）

現在無法判定，但**必須現在就寫下來**，否則第一階段交付後容易被當成「已驗證」。

| 代號 | 基準 | 需要什麼才能判 |
|---|---|---|
| **V1** | 依本指引做出的模型，通過實體試戴試驗 | 樣機 ＋ 受試者。試驗設計已寫在 [GUIDELINE](GUIDELINE.md) H 段：須含加重右側臥、年長受試者、口張開狀態、長時間靜態受壓 |
| **V2** | 所有 ⏳ 項目填入實測數值 | 競品量測 ＋ 枕頭壓陷量測 ＋ 薄膜壓力感測器 |
| **V3** | 指引本身的預測與實測相符 | 例：可信頻率上限以下，集中參數模型的預測與實測響應相符。**這是檢驗指引有沒有說謊，不只是補數字** |

> V3 常被省略，但它是唯一能反過來驗證「指引本身」的一條。前兩條只是把空格填滿。

---

## 6. 目前擋住完整定義的事項

**原本擋路的「服務哪個情境」已於 2026-08-25 裁定**（整夜臥睡，坐睡移出），連帶解決了「掛耳式是否為認真候選」（實質出局）。剩下三項：

| 未決事項 | 對驗收基準的影響 | 取得成本 |
|---|---|---|
| **「安全關鍵聲響仍可喚醒使用者」是否為硬需求** | 最大。若是，架構被收斂（密封式受限、通氣孔升格安全件），並新增一整組防阻塞條文與驗收方式 → [GOAL 5.1](GOAL.md#sec-5-1) | 產品層裁定，無成本 |
| **產品是否整夜播放遮蔽音** | 決定被動隔音下限的嚴格程度——播遮蔽音則遮蔽本身在做隔音的工作 | 產品層裁定，無成本 |
| **元件候選清單** | 關掉第 21 項。電源預算與聲學腔體預算必須聯合求解 | 產品端給選型方向，不需付費文獻 |
| **機型 S／M／L 要區分什麼** | 決定第 4 項是否需要三套獨立包絡數字 | 產品層裁定 |

**三項都是產品層裁定，都不需要花錢或做實驗。** 相對地，PDT 絕對值與側睡凸出高度需要付費文獻或實測。

---

## 7. 這份基準本身的限制

- **F6 需要一位未參與的設計者。** 這是資源問題不是方法問題，但沒有他，第一階段的完成判定就只能是弱化版。
- **F1 與 F3 的判定含人為判斷**（「這條算不算形容詞規則」「這算不算一個獨立決策」）。已盡量給邊界，但無法完全機械化。建議由非本文件作者執行判定。
- **第 4 節的清單是本團隊列的【推論】**，不是業界標準的設計決策分解。若驗收方有自己的清單，**以驗收方的為準**——這份的價值在於逼出「哪些沒著落」，不在於清單本身權威。

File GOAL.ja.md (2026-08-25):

# プロジェクトの目標と成功の定義

ステータス：初稿 ｜ 最終更新 2026-08-25

> 🌐 中文版：[GOAL.md](GOAL.md)

---

## 0. この文書の位置づけ

| 文書 | 何に答えるか | 読み手 |
|---|---|---|
| **GOAL.ja.md**（本文書） | **なぜこれをやるのか、何が達成されれば成功か** | プロジェクトの意思決定者 |
| [ACCEPTANCE.ja.md](ACCEPTANCE.ja.md) | 文書自体が合格か（手段の層） | 受入側 |
| [GUIDELINE.ja.md](GUIDELINE.ja.md) | 設計者は何をすべきか | 設計者 |

**正しい順序は GOAL → ACCEPTANCE → GUIDELINE である。** 目標が何を検査すべきかを決め、検査が文書に何を書くべきかを決める。

> ⚠️ **本案件の順序はこれまで逆であった。** 先に各章を書き、GUIDELINE を抽出し、ACCEPTANCE を後付けし、最後に目標を定義している。その結果、文書品質は綿密に検査されたが、「その検査に通ったことが『装着感の改善』にどう寄与するのか」に答えていなかった。本文書がその層を補い、それに基づいて既存文書の優先順位を組み替える（第 8 節）。

---

## 1. 大目標

**睡眠用イヤホンの装着感を改善すること。**

**範囲は 2026-08-25 に確定した**：

| 項目 | 確定内容 |
|---|---|
| 目標 | **「装着感」に限定。** 睡眠体験全体は含まない |
| 使用シーン | **夜間の長時間睡眠（一晩の臥位睡眠）に限定。** 昼寝と座位睡眠は第一段階から外す |
| 中核となる章 | Part 7、3、4 |
| 周辺化 | CMF のインジケータ輝度（文書には残すが、成功定義には含めない） |
| 遮音 vs 快適が衝突したとき | **快適を優先し、遮音が譲る**（遮音の下限は未定） |

**この 1 つの確定が、さらに 2 件を決めている：**
- **イヤーフック型は実質的に候補から外れる。** 利点は座位睡眠に集中しており、横向き寝では高リスク（耳後部が乳様突起の骨面で圧迫される）。座位を外すと欠点だけが残る。
- **ヘッドバンド／アイマスク型が最有力になる。** 唯一の弱点「公共の場で社会的に無理」は座位専用の制約であった。

> ⚠️ **座位睡眠の分析は削除しない。**「第一段階の範囲外」と明記して [Part 1A](jp/01a-posture-analysis.md) と [Part 4.2.3](jp/04-max-design-envelope.md#sec-4-2-3) に残す。削除すると「検討しなかった」のか「検討して外した」のかが区別できなくなる。

---

## 2. ★ なぜ「正確な寸法表を出すこと」では大目標に届かないのか

**これは本案件で最も重要な負の結果であり、Part 7 に埋めるのではなく目的の層に置くべきものである。**

実測が示すのは次である：**耳の寸法から快適さは予測できない。** 耳の左右対称性、性別、耳甲介（concha）の長さ、耳甲介腔（cavum conchae）の幅と、主観的な快適さ・装着感の評点との相関は**いずれも有意でないか、あっても弱い**。有意であったのは**使用シーンと製品サイズ**のほうであった。→ [Part 7.0b](jp/07-wearing-pressure-comfort.md#sec-7-0b)

（統計上の限界：n=30。「有意に達しない」は弱い証拠であって、「関連がない」ことを意味しない。第 9 節参照。）

**推論**：人間工学的な寸法データの役割は、**「収まらない」案を排除すること**であって、**「最も快適な」案を選び出すこと**ではない。【推論】

> ⛔ **したがって、本案件の成功を「精密な耳部寸法のパーセンタイル表を納品すること」と同一視するのは、手段を目的と取り違えている。** その表は必要である（収まらない案は先に落とさねばならない）が、それ自体は装着感を改善しない。

---

## 3. ★ 大目標への最大の貢献：「快適さ」の操作的定義を書き換えること

一般のイヤホンにおける「快適さ」は、実務上ほぼ**装着した瞬間の感触**を指す。睡眠用イヤホンのそれは**時間 × 姿勢 × 顎の状態の積分量**である。両者は別の量であり、前者を満たしても後者は満たされない。

### 3.1 評価マトリクス——快適さはこれらのセル上で評価すべきであり、単一点では足りない

| | 仰臥 | 横臥（左） | 横臥（右） |
|---|---|---|---|
| **0 分（装着直後）** | 一般の業界が評価する唯一のセル | | |
| **30 分** | | | |
| **3 時間** | | | |
| **一晩 6–9 時間** | | | |

**さらに顎の状態（閉合／開口）を掛ける。**

### 3.2 各軸に証拠がある。感覚で足したものではない

| 軸 | なぜ含めねばならないか | 証拠等級 |
|---|---|---|
| **時間** | 寝返り頻度は 18–24 歳 3.6 回/時 → 65–80 歳 **2.1 回/時**。30 分以上動かない時間帯は加齢とともに増える。**荷重条件はピークではなく持続である** | 【文献】→ [Part 1A.3](jp/01a-posture-analysis.md#sec-1a-3) |
| **姿勢** | 各姿勢が拘束するパラメータはほとんど重ならない：突出高さ←横臥／外耳道フィットの許容←仰臥／保持（寝返りで外れない）←横臥と寝返り動作 | 【推論】→ [Part 1A.6](jp/01a-posture-analysis.md#sec-1a-6) |
| **左右** | 高齢者は右側臥を明確に好む → **右耳の累積圧迫が高い。** 左右対称と仮定してはならない | 【文献】→ [Part 1A.3](jp/01a-posture-analysis.md#sec-1a-3) |
| **顎** | 仰臥では顎が緩んで外耳道が変形し、**被験者 30 名全員に出現**。変形は耳珠（tragus）に集中し、耳珠はまさに圧迫に最も敏感な領域である | 【文献】→ [Part 1A.2](jp/01a-posture-analysis.md#sec-1a-2) |

**傍証**：業界の密閉自己診断プロトコル（Apple、Sony）はいずれも**覚醒・静止・口を閉じた状態での一回限りの測定**である。→ [Part 7.4.0](jp/07-wearing-pressure-comfort.md#sec-7-4-0)
**密閉テストの通過は、一晩密閉が保たれることを保証しない。** これは「単一点での評価」が不十分であることの直接の例証である。

> ★ **評価する対象を変えることは、寸法をより精密に測ることより、大目標に対するてこ比がはるかに大きい。** 寸法をいくら精密にしても、左上のセル 1 つを良くしているにすぎない。

---

## 4. ガイドラインが大目標へ至る 3 つの経路

**この 3 つしかない。** それぞれ機構と検証可能性が異なる。

| 経路 | 機構 | 現況 | 貢献を検証できるか |
|---|---|---|---|
| **① 既知の理由で失敗する設計を落とす**（減算） | 耳珠で荷重を受けない、Arnold 咳嗽反射域に触れない、解剖学的エンベロープを超えない、造形で到達できない硬度を仮定しない | ルールあり → [GUIDELINE B](GUIDELINE.ja.md) | 可能。装着試験の失敗時に、その原因がガイドラインにあったかを遡る |
| **② 快適さの操作的定義を正す**（第 3 節） | 評価を単一点からマトリクスへ | **まだ条文化されていない** | 可能。試験計画がマトリクスを覆っているかを検査する |
| **③ 経験的ループを高速化し、順序を正す** | 「結果→代理」の測定順序。器具不要の 3 種スクリーニングで明らかに不適なものを先に落とす | あり → [Part 7.4.1](jp/07-wearing-pressure-comfort.md#sec-7-4-1) | 可能。許容できる装着感に到達するまでの試作回数を数える |

> ⛔ **3 つとも「最も快適な形状を算出する」ものではない。** 本ガイドラインは設計最適化を**行えない**——超弾性材料モデルと接触ソルバがなく、耳の軟組織パラメータにも検証可能な出典がない。→ [Part 0.6](jp/00-scope-and-usage.md#sec-0-6)
> この点は目的の層に明記しなければならない。さもないと本文書が最適化ツールとして期待され、その期待は外れる。

---

## 5. 成功の定義——3 層。互いに代用してはならない

| 層 | 内容 | いつ測れるか | 誰の責任か |
|---|---|---|---|
| **出力層** | 文書が完成し実行可能であること（[ACCEPTANCE](ACCEPTANCE.ja.md) の F1–F6） | **今** | 当チーム |
| **★ 成果層（＝本プロジェクトの成功）** | **本ガイドラインに沿った設計プロセスが、沿わない場合より速く確実に、許容できる装着感へ到達すること** | 試作機と装着試験の後 | 当チーム ＋ 設計側 |
| **影響層** | 利用者が実際により快適だと感じること | 製品の市場投入後 | 製品側 |

> ⛔ **出力層の達成を成果層の達成と言い換えてはならない。** 文書が書き上がったことは道具が揃ったことを意味するにすぎず、装着感が改善したことを意味しない。

### 5.1 ★ 安全制約——目標より上位にあり、トレードオフで手放せない

大目標は「装着感」に限定された。安全は装着感ではない。**しかしそれは安全が外れることを意味しない——安全は目標ではなく制約である。目標は weighing の対象になるが、制約はならない。**

したがって安全項目は**成功指標（S1–S5）には入れず**、「侵してはならない条件」の側に置く。判定の仕方も異なる：成功指標は「どこまで達したか」を問い、安全制約は「侵していないか」を問う。

| 安全制約 | 状態 | 不足しているもの |
|---|---|---|
| **安全上重要な音（火災警報器・目覚まし・乳児の泣き声）で目覚められること** | ⏳ **必須要件とするかは製品層の裁定待ち** | 睡眠時の覚醒しきい値／警報器の実出力レベル |
| **音量が安全な曝露レベルを超えないこと** | ⛔ **既知の欠落。** 本ガイドラインは明示的に範囲外としている（WHO／NIOSH の正式基準が必要で、当チームに検証手段がない） | 正式な騒音曝露基準 |

> **★ この 2 条は噛み合っており、分けて扱えない。** 「快適を優先し遮音が譲る」は受動遮音を下げ → 利用者が音量を上げて補償し → **圧力が遮音の次元から音量の次元へ移動する**。音量はガイドラインが唯一覆っていない次元であり、しかも曝露は一晩 6〜9 時間である。
> **したがって「内容が聞こえること」を単独で下限としてはならない。** 必ず**「安全な曝露レベルを超えない範囲で内容が聞こえること」**と書く——さもなければ、この条件はいつでも音量を上げれば満たせてしまい、下限として機能しない。

> **★ 「目覚められること」が必須要件となる場合、それは数値を 1 つ与えるにとどまらず、アーキテクチャを収束させる。** 失効の方向が異なるためである：
>
> | 手段 | 失効後の状態 | 性質 |
> |---|---|---|
> | **受動的な通気孔** | 耳垢やイヤーチップで塞がれる → **完全遮断、かつ利用者は気づかない** | **条件付きのフェイルセーフ**——条件は開通を保つこと |
> | **マイクによる電子的な取り込み** | 電池切れ → **完全遮断、かつ利用者は気づかない** | **構造上フェイルセーフになりえない**——幾何的に存在しない経路を電子は作れない |
>
> ⚠️ **両者の失効後の終状態は同じである**——「完全遮断のまま、利用者は守られているつもりでいる」。**本節は当初、受動方式を無条件のフェイルセーフと書いていたが、それは誤りであり訂正した。**
>
> 真の違いは**失効の可能性を設計で消せるかどうか**にある：電子方式の電池切れは設計で排除できない（一晩 6〜9 時間では想定内である）。受動方式の閉塞は設計で下げられる——**したがって閉塞防止の条項は付加的なものではなく、受動方式のフェイルセーフ性そのものの源である。それがなければ受動方式に優位はない。**
>
> よって必須要件とするなら：**受動的な経路が唯一フェイルセーフになりうる解だが、閉塞防止条項と一体でなければ成立しない**（孔径下限、清掃可能性、イヤーチップで覆われる範囲に置かないこと）。密閉型インイヤーは実質的に制限され、通気孔は安全部品へ格上げされる。電子的な取り込みは付加価値にとどまり、要件を満たす手段にはならない。【推論】

---

## 6. 成功指標

### S1 ★ 主指標——「ガイドラインが知っていたのに述べていなかった」理由で失敗する試作が 1 つも出ないこと

装着試験で快適性の失効が出るたび、次に分類する：

| 分類 | 判定 |
|---|---|
| **(a)** ガイドラインが明確に警告しており、設計者が従わなかった | ガイドラインは機能した。**失敗に数えない** |
| **(b)** ガイドラインが言及しておらず、しかし原因は事前に知りえた | ⛔ **ガイドラインの欠陥。これを 0 にする** |
| **(c)** 全く新しい原因で、事前には知りえなかった | 失敗に数えないが、**ガイドラインへ必ず書き戻す** |

**判定方法**：装着試験の失効リストを逐一分類する。**成功 ＝ (b) が 0。**
**現況**：試作機がなく、測定不能。

### S2 ★ すべてのトレードオフに、衝突時どちらが譲るかが明記されていること

**これは S1 が検出できない穴を塞ぐ。** 設計者は各条項に適合しながら、全体として大目標から離れうる——彼は質問しないからである。中立に書かれたトレードオフを見て、自分でどちらかを選ぶ。

既知の 3 組の対立。**範囲確定により 1 組が消滅し、2 組に方向が付いた**——ただし条文はまだ改訂されていない：

| 対立 | 確定した方向（2026-08-25） | 不足しているもの |
|---|---|---|
| **受動遮音 vs 装着圧** | **快適を優先し、遮音が譲る** | **遮音の下限**——これを下回れば成立しない水準（内容が聞き取れない、音漏れで同床者を起こす）。Part 5 で補う |
| **保持力 vs 装着圧** | **寝返りに耐える最小限の保持力にとどめ**、余剰はすべて快適へ回す。（目的が「うたた寝で落ちない」から「寝返りで外れない」に変わったため） | 寝返り時の実際の脱落しきい値。実測が要る |
| **遮音 vs 環境音の把握** | ⚠️ **「消滅」との判断は誤りであり撤回した。** 消えたのは座位版の実例のみ。夜間版の実例は火災警報器・目覚まし・乳児の泣き声であり、**夜間に限定したことでむしろ重くなる**——6〜9 時間の無意識状態で、利用者は自ら気づいて補正できない。**安全制約へ格上げ。第 5.1 節を参照** | 睡眠時の覚醒しきい値、警報器の実出力レベル |

**判定方法**：ガイドライン中のトレードオフをすべて列挙し、各組に「衝突時どちらが譲るか」または「製品判断であり決定者は誰か」を明記させる。**中立のまま決定者も不在のトレードオフの数が 0 であること。**
**現況**：⚠️ **方向は確定（2 組）、条文は未改訂。** 判定に必要な数値がまだ埋まっておらず、Part 5.4 も中立記述のままである。

### S3 評価マトリクスの被覆率

**判定方法**：試験計画が第 3.1 節のマトリクスを覆うセル数 ÷ 全セル数。
**現況**：[GUIDELINE](GUIDELINE.ja.md) H 節が右側臥の加重、高齢被験者、口を開けた状態、長時間の静的圧迫を要求済み——**方向は正しいが、マトリクスとして条文化されておらず**、被覆率は未計算。

### S4 許容できる装着感に到達するまでの試作回数

**判定方法**：ガイドラインを用いない対照との比較。
**現況**：⚠️ **ベースラインがない**（設計側が同種の案件を経験していない限り）。**参考指標とし、判定基準としては用いない。**

### S5 ガイドライン自身の予測が実測と一致すること

例：信頼できる周波数上限以下で、集中定数モデルの予測が実測応答と一致すること。**数値を埋めるだけでなく、ガイドラインが嘘をついていないかを検査する。**
**現況**：試作機がなく、測定不能。

---

## 7. 大目標から見た現在のギャップ

**優先順位は「文書の完全性」から見た場合と異なる。以下は装着感への影響順である：**

| ギャップ | 目的の層から見てなぜ重いか |
|---|---|
| **1. 圧迫不快閾値（PDT）の絶対値が未取得** | **現在てこ比が最も高い単一の取得項目。** この 1 つの数値が 2 箇所を同時に閉じる：接触面形状のしきい値と、案件全体の圧力上限。これがなければ圧力関連の規範は配置禁止領域（定性）で止まる |
| **2. 安全制約が未裁定（第 5.1 節）** | 「目覚められること」を必須とするかがアーキテクチャの収束を決める。音量上限はガイドラインが唯一覆っていない次元であり、「遮音が譲る」はまさにそこへ圧力を押しやる |
| **3. 2 組のトレードオフは方向が付いたが条文が未改訂（S2）** | 適合していながら目標から離れる唯一の入口。方向が決まっても設計者が読めなければ意味がない——Part 5.4 は中立記述のままである |
| **4. 評価マトリクスが条文化されていない（S3）** | 第 3 節が主張する最大の貢献が、まだ実装されていない |
| 5. 横向き寝の突出高さ上限が未実測 | 欠落として登録済、方法は提示済 |

### 2026-08-25 に格下げされた 2 項目

「空白かつ未登録」としていた接触面形状とダクト形状は、**判定可能な形式 ＋ 欠けている量の特定**へ書き換えられ、条項全体が空白という状態ではなくなった：

| 項目 | 書き換え後の形式 | 唯一の不足 |
|---|---|---|
| **接触面のフィレット半径と接触面積** | **各接触パッチが個別に A_i ≥ F_i / PDT(当該部位) を満たすこと**（合計ではなくパッチ単位。荷重分布が不明な場合は最不利分布を取る）。フィレット半径は同じことの幾何的手段である——半径が小さいほど接触面積が小さくなり、圧力が上がる | **PDT 絶対値の部位別表** |
| **ダクト形状** | 開放式：f₀ と V を定め A/L_eff を逆算する。A と L の自由度は 1 つだけ。密閉式：設計者が選べる f₀ は存在せず、ダクトは直列の音響質量。制約は容積収支と高域上限から来る | 密閉式の**挿入後の残存外耳道容積** |

> **なぜこれが文書整理ではなく実質的な前進なのか**：「空白」は制約がないと読まれ、設計者は自分が何を見落としたか気づけない。「判定可能な形式 ＋ 不足している 1 つの数値」であれば、欠落が明確で、調達も実測もできる目標になる。**2 項目とも、記録されるだけでなく、解決を計画できる状態になった。**
>
> ⚠️ **ただし、まだ合格ではない。** 不足している数値が埋まるまで、この 2 条は実際には判定できない——**格下げは解決ではない。**

---

## 8. この目標定義が変えること

| これまで | 変更後 |
|---|---|
| 10 章が並列 | **Part 7（装着圧と快適性）を中核へ格上げ。** Part 2 は「排除のため」であり「優劣選択のため」ではないと明確化 |
| [ACCEPTANCE](ACCEPTANCE.ja.md) の F6（独立実行可能性）が最終判定 | **維持するが、必要条件であって十分条件ではないと格下げ。** F6 は「適合しているが方向が逆」を検出できず、そこは S2 が補う |
| Part 5.4 の遮音 vs 快適が中立記述 | **方向を持つ判定基準へ変更：快適を優先し遮音が譲る。** 範囲は確定済、遮音の下限値が入り次第、条文を改訂する |
| 欠落を章の順に列挙 | **装着感への影響順に並べ替え**（第 7 節） |

---

## 9. この定義自体の限界

- **成果層と影響層の間の接続は検証されていない。** S1–S5 をすべて通過しても、利用者が実際により快適になる保証はない——快適さには個人差、期待値、ブランド、価格など本ガイドラインの及ばない要因も効く。**本文書は成果層までしか主張しない。**
- **S1 の分類には人の判断が含まれる**（「この原因は事前に知りえたか」）。ガイドラインの作成者以外が分類することを推奨する。
- **★ 第 2 節の推論は n=30 の負の結果に立脚しており、本文書で最も覆されやすい箇所である。** 「有意に達しない」は弱い証拠であって「関連がない」ではない。将来より大きな標本で耳の寸法が快適さを実際に予測すると示されれば、**第 2 節と第 4 節の経路分けは書き直しになる。** 確立した事実として流用されないよう、先に明示しておく。

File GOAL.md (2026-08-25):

# 專案目標與成功定義

狀態：初稿 ｜ 最後更新 2026-08-25

> 🌐 日本語版：[GOAL.ja.md](GOAL.ja.md)

---

## 0. 這份文件在整套文件中的位置

| 文件 | 回答什麼 | 給誰 |
|---|---|---|
| **GOAL.md**（本文件） | **為什麼要做這件事，做到什麼算成功** | 專案決策者 |
| [ACCEPTANCE.md](ACCEPTANCE.md) | 文件本身合不合格（手段層） | 驗收方 |
| [GUIDELINE.md](GUIDELINE.md) | 設計者該怎麼做 | 設計者 |

**正確順序是 GOAL → ACCEPTANCE → GUIDELINE。** 目標決定要檢查什麼，檢查決定文件要寫什麼。

> ⚠️ **本專案先前的順序是反的。** 先寫了分章，再抽出 GUIDELINE，再補 ACCEPTANCE，最後才定義目標。結果是文件品質檢查得很仔細，卻沒有回答「這些檢查通過了，對『改善佩戴感』有什麼幫助」。本文件補上這一層，並據此重排既有文件的優先序（見第 8 節）。

---

## 1. 大目標

**改善睡眠耳機的佩戴感。**

**範圍已裁定（2026-08-25）**：

| 項目 | 裁定 |
|---|---|
| 目標 | **限「佩戴感」**，不含睡眠體驗全體 |
| 使用情境 | **限夜間長時間睡眠（整夜臥睡）**。午睡與坐睡移出第一階段 |
| 中核章節 | Part 7、3、4 |
| 周邊化 | CMF 指示燈亮度（仍保留於文件，但不列入成功定義） |
| 隔音 vs 舒適衝突時 | **舒適優先，隔音讓步**（隔音下限待定） |

**這一項裁定連帶決定了另外兩件事：**
- **掛耳式實質出局。** 其優勢全部集中於坐睡；側睡為高風險（耳後壓在乳突區骨面上）。坐睡移出後只剩缺點。
- **頭帶／眼罩式升為最強候選。** 其唯一弱點「公開場合社交不可行」屬坐睡專屬約束。

> ⚠️ **坐睡分析不刪除**，標「第一階段範圍外」保留於 [Part 1A](cn/01a-posture-analysis.md) 與 [Part 4.2.3](cn/04-max-design-envelope.md#sec-4-2-3)。刪除會使「未曾考慮」與「考慮後排除」無法區分。

---

## 2. ★ 為什麼「給出正確的尺寸表」達不到大目標

**這是本專案最重要的負面結果，必須放在目的層而不是埋在 Part 7。**

實測顯示：**耳部尺寸預測不了舒適度。** 耳部對稱性、性別、耳甲（concha）長度、耳甲腔（cavum conchae）寬度，與主觀舒適／貼合評分的相關性**皆不顯著或很弱**；真正顯著的是**使用情境與產品尺寸**。→ [Part 7.0b](cn/07-wearing-pressure-comfort.md#sec-7-0b)

（統計限制：n=30。「未達顯著」是弱證據，不等於無關聯。見第 9 節。）

**推論**：人因尺寸資料的角色是**排除「裝不下」的方案**，不是**挑出「最舒服」的方案**。【推論】

> ⛔ **因此，把本專案的成功等同於「交出一份精確的耳部尺寸百分位表」，是把手段當成目的。** 那份表是必要的（裝不下的方案要先排除），但它本身不改善佩戴感。

---

## 3. ★ 指引對大目標最大的貢獻：改寫「舒適」的操作型定義

一般耳機的「舒適」在實務上約等於**戴上那一刻的感受**。睡眠耳機的舒適是**時間 × 姿勢 × 下顎狀態的積分量**。兩者是不同的量，滿足前者不蘊含滿足後者。

### 3.1 評估矩陣——舒適必須在這些格子上評估，不是單點

| | 正睡 | 側睡（左） | 側睡（右） |
|---|---|---|---|
| **0 分（戴上瞬間）** | 一般業界唯一評估的格子 | | |
| **30 分** | | | |
| **3 小時** | | | |
| **整夜 6–9 小時** | | | |

**再乘上下顎狀態（閉合／張開）。**

### 3.2 每一軸都有證據支撐，不是憑感覺加的

| 軸 | 為什麼必須納入 | 證據等級 |
|---|---|---|
| **時間** | 翻身頻率 18–24 歲 3.6 次/小時 → 65–80 歲 **2.1 次/小時**，且超過 30 分鐘不動的時段隨年齡增加。**受力條件是「持續」不是「尖峰」** | 【文獻】→ [Part 1A.3](cn/01a-posture-analysis.md#sec-1a-3) |
| **姿勢** | 各姿勢綁定的參數幾乎不重疊：凸出高度←側睡｜耳道貼合寬容度←正睡｜固位（翻身不脫落）←側睡與翻身動作 | 【推論】→ [Part 1A.6](cn/01a-posture-analysis.md#sec-1a-6) |
| **左右** | 老年明顯偏好右側臥 → **右耳累積壓迫較高**，不可假設左右對稱 | 【文獻】→ [Part 1A.3](cn/01a-posture-analysis.md#sec-1a-3) |
| **下顎** | 仰躺下顎鬆弛使外耳道變形，**30 名受試者全數出現**。變形集中在耳屏（tragus），而耳屏正是壓力最敏感區 | 【文獻】→ [Part 1A.2](cn/01a-posture-analysis.md#sec-1a-2) |

**旁證**：業界的密封自測協定（Apple、Sony）皆為**清醒、靜止、口閉合下的一次性量測**。→ [Part 7.4.0](cn/07-wearing-pressure-comfort.md#sec-7-4-0)
**通過密封測試不保證整夜維持密封。** 這正是「單點評估」不足的直接例證。

> ★ **改變評估對象，比把尺寸量得更準，對大目標的槓桿大得多。** 尺寸再精確也只是把左上那一格做好。

---

## 4. 指引通往大目標的三條路徑

**只有這三條。** 每條的機制與可驗證性不同。

| 路徑 | 機制 | 現況 | 貢獻可否驗證 |
|---|---|---|---|
| **① 排除已知會失敗的設計**（減法） | 承重不放耳屏、不觸 Arnold 咳嗽反射區、不超解剖包絡、硬度做不到就別假設 | 已有規則 → [GUIDELINE B](GUIDELINE.md) | 可。試戴失敗時回溯原因是否已在指引中 |
| **② 修正舒適的操作型定義**（第 3 節） | 把評估從單點改為矩陣 | **尚未寫成條文** | 可。檢查試驗計畫是否覆蓋矩陣 |
| **③ 加速並排序經驗迴圈** | 「結果→代理」的量測順序；器具不要的三項快篩先擋掉明顯不合者 | 已有 → [Part 7.4.1](cn/07-wearing-pressure-comfort.md#sec-7-4-1) | 可。計算達到可接受佩戴感所需的試作回合數 |

> ⛔ **三條都不是「算出最舒適的形狀」。** 本指引**無法**做設計最佳化——缺超彈性材料模型與接觸求解器，且耳部軟組織參數無可核驗來源。→ [Part 0.6](cn/00-scope-and-usage.md#sec-0-6)
> 這一點必須寫在目的層，否則本文件會被當成最佳化工具而落空。

---

## 5. 成功定義——三層，不可互相冒充

| 層 | 內容 | 何時可測 | 誰負責 |
|---|---|---|---|
| **產出層** | 文件完成且可執行（[ACCEPTANCE](ACCEPTANCE.md) 的 F1–F6） | **現在** | 本團隊 |
| **★ 成果層（＝本專案的成功）** | **依本指引進行的設計流程，比不依指引更快、更可靠地達到可接受的佩戴感** | 有樣機與試戴之後 | 本團隊 ＋ 設計方 |
| **影響層** | 使用者實際感到更舒適 | 產品上市後 | 產品方 |

> ⛔ **產出層達成不得講成成果層達成。** 文件寫完只代表工具備妥，不代表佩戴感改善了。

### 5.1 ★ 安全約束——位階在目標之上，不可被取捨換掉

大目標已限定為「佩戴感」，安全顯然不是佩戴感。**但這不代表安全出局——安全不是目標，是約束。目標可以被權衡，約束不能。**

因此安全項**不列入成功指標**（S1–S5），而列入「不可違反」這一組。判定方式也不同：成功指標問「做到多少」，安全約束問「有沒有違反」。

| 安全約束 | 狀態 | 缺什麼 |
|---|---|---|
| **安全關鍵聲響（煙霧警報器、鬧鐘、嬰兒哭聲）仍可喚醒使用者** | ⏳ **待產品層裁定是否為硬需求** | 睡眠狀態覺醒閾值；警報器實際輸出位準 |
| **音量不超過安全暴露位準** | ⛔ **已知缺口。** 指引明確排除此項（需 WHO／NIOSH 正式標準，本團隊無核驗管道） | 正式噪音暴露標準 |

> **★ 這兩條互相咬住，不能分開處理。** 「舒適優先、隔音讓步」會讓被動隔音下降 → 使用者調高音量補償 → **壓力從隔音維度轉移到音量維度**，而音量正是指引唯一未覆蓋的維度，且整夜暴露 6–9 小時。
> **因此「內容可聞」不可單獨成立為下限**，必須寫成**「在不超過安全暴露位準的前提下內容可聞」**——否則該條永遠可以靠調高音量滿足，形同虛設。

> **★ 若「可喚醒」成立為硬需求，它會收斂架構，不只是給一個數字。** 失效方向不同：
>
> | 手段 | 失效後的狀態 | 性質 |
> |---|---|---|
> | **被動通氣孔** | 孔被耳垢／耳塞套堵住 → **完全隔絕且使用者不知情** | **有條件的 fail-safe**——條件是保持暢通 |
> | **麥克風電子透傳** | 電池耗盡 → **完全隔絕且使用者不知情** | **結構上不可能 fail-safe**——幾何上不存在的通路，電子創造不出來 |
>
> ⚠️ **兩者失效後的終端狀態相同**，都是「維持完全隔絕、使用者以為自己受保護」。**先前本節把被動方案寫成無條件 fail-safe，那是錯的，已更正。**
>
> 真正的差別在**失效的可能性能否被消除**：電子方案沒電就是沒電，無法從設計上排除（整夜 6–9 小時，電池耗盡是預期情況不是例外）；被動方案的堵塞則可以靠設計壓低——**因此防阻塞條文不是錦上添花，它就是被動方案 fail-safe 性質的來源。沒有它，被動方案沒有優勢。**
>
> 故若為硬需求：**被動通路是唯一可能 fail-safe 的解，但必須連同防阻塞條文一起才成立**（孔徑下限、可清潔性、不得位於耳塞套可覆蓋範圍內）。密封式入耳實質受限，通氣孔升格為安全件。電子透傳只能當加值，不能當滿足手段。【推論】

---

## 6. 成功指標

### S1 ★ 主指標——沒有任何試作因「指引已知卻沒講」的原因而失敗

試戴試驗每出現一次舒適失效，歸類為：

| 類別 | 判定 |
|---|---|
| **(a)** 指引已明確警告，設計者未遵守 | 指引有效。**不計為失敗** |
| **(b)** 指引未提及，但原因是可事先知道的 | ⛔ **指引缺陷。這一項要為 0** |
| **(c)** 全新原因，事前無從得知 | 不計為失敗，但**必須回寫進指引** |

**判定方法**：試戴試驗的失效清單逐筆歸類。**成功 ＝ (b) 類為 0。**
**現況**：無樣機，未能測定。

### S2 ★ 每一組取捨都標明了衝突時的讓步方向

**這條補的是 S1 測不到的漏洞。** 設計者可以每條都合規、整體卻背離大目標——因為他不會提問，他會照著中立敘述的取捨自行選一邊。

已知的三組對立。**範圍裁定後，一組消滅、兩組有了方向**——但條文尚未改寫：

| 對立 | 裁定方向（2026-08-25） | 尚缺 |
|---|---|---|
| **被動隔音 vs 佩戴壓力** | **舒適優先，隔音讓步** | **隔音下限**——低於多少即不成立（聽不清內容、或漏音吵醒同床者）。待 Part 5 補 |
| **固位力 vs 佩戴壓力** | **取剛好能撐過翻身的最小固位力**，餘裕全部讓給舒適。（目的已從「打瞌睡不掉」改為「翻身不脫落」） | 翻身時的實際脫落門檻，須實測 |
| **隔音 vs 環境感知** | ⚠️ **先前誤判為「消滅」，已撤回。** 消滅的只是坐睡實例（聽得到廣播）。夜間實例是煙霧警報器、鬧鐘、嬰兒哭聲，**限定夜間後這組變重不是變輕**——6–9 小時無意識，使用者無法自行察覺補償。**已升格為安全約束，見第 5.1 節** | 睡眠狀態覺醒閾值、警報器實際輸出位準 |

**判定方法**：列舉指引中的所有取捨，每組須標明「衝突時誰讓步」或「產品決策，擁有者是誰」。**中立且無擁有者的取捨數必須為 0。**
**現況**：⚠️ **方向已定（2 組），條文未改。** 兩組的判準仍待數值補上才能真正判定；Part 5.4 仍是中立敘述，尚未改寫。

### S3 評估矩陣覆蓋率

**判定方法**：試驗計畫覆蓋第 3.1 節矩陣的格子數 ÷ 總格子數。
**現況**：[GUIDELINE H](GUIDELINE.md) 已要求加重右側臥、年長受試者、口張開、長時間靜態受壓——**方向對，但未寫成矩陣**，覆蓋率未計算。

### S4 達到可接受佩戴感所需的試作回合數

**判定方法**：與不使用指引的對照比較。
**現況**：⚠️ **無基線**，除非設計方做過同類專案。**列為參考指標，不作為判準。**

### S5 指引自身的預測與實測相符

例：可信頻率上限以下，集中參數模型的預測與實測響應相符。**這是檢查指引有沒有說謊，不只是補數字。**
**現況**：無樣機，未能測定。

---

## 7. 從大目標看，現在的差距

**優先序與「文件完整性」的觀點不同，以下依對佩戴感的影響排序：**

| 差距 | 為什麼從目的層看更嚴重 |
|---|---|
| **1. 壓力不適閾值（PDT）絕對值未取得** | **目前槓桿最高的單一取得項。** 這一個數字同時關掉兩處：接觸面幾何的門檻，以及全案的壓力上限。沒有它，壓力相關規範只能停在禁置區（定性） |
| **2. 安全約束未裁定（第 5.1 節）** | 「可喚醒」是否為硬需求，決定架構是否被收斂；音量上限是指引唯一未覆蓋的維度，而「隔音讓步」正把壓力推向那裡 |
| **3. 兩組取捨方向已定但條文未改（S2）** | 合規但偏離目標的唯一入口。方向定了不等於設計者讀得到——Part 5.4 仍是中立敘述 |
| **4. 評估矩陣未成條文（S3）** | 第 3 節主張的最大貢獻尚未落地 |
| 5. 側睡凸出高度上限未實測 | 已登記為缺口，方法已給 |

### 已於 2026-08-25 降級的兩項

原本列為「空白且未登記」的接觸面幾何與導管幾何，已改寫為**可判定形式 ＋ 標出唯一缺的量**，不再是整條規則空白：

| 項目 | 改寫後的形式 | 唯一待補 |
|---|---|---|
| **接觸面圓角半徑與接觸面積** | **每一接觸斑塊各自滿足 A_i ≥ F_i / PDT(該部位)**（逐斑塊，非總和；承載分佈未知時取最不利分佈）。圓角半徑是同一件事的幾何手段——半徑越小、接觸面積越小、壓力越高 | **PDT 絕對值分區表** |
| **導管幾何** | 洩壓式：定 f₀ 與 V → 反解 A/L_eff，A 與 L 只剩一個自由度。密封式：無設計者可選的 f₀，導管為串聯聲質量，約束來自容積帳與高頻上限 | 密封式的**插入後殘餘耳道容積** |

> **為什麼這算實質進展而非文件整理**：「留白」會被讀成沒有限制，設計者不會發現自己漏了什麼；「可判定形式 ＋ 一個待補數」則讓缺口變成一個明確、可採購、可實測的目標。**兩項都因此可以被安排去解決，而不只是被記錄。**
>
> ⚠️ **但它們仍未通過。** 在待補的數字填上之前，這兩條規則無法真正判定——降級不等於關閉。

---

## 8. 這個目標定義會改變什麼

| 既有做法 | 改成 |
|---|---|
| 十章並列 | **Part 7（佩戴壓力與舒適）升為中核**；Part 2 明確定位為「排除用」而非「選優用」 |
| [ACCEPTANCE](ACCEPTANCE.md) 的 F6（獨立可執行性）是最終判準 | **保留，但降為必要非充分**——F6 測不出「合規但方向反了」，由 S2 補 |
| Part 5.4 隔音 vs 舒適寫成中立取捨 | **改為有方向的判準：舒適優先、隔音讓步。** 範圍已裁定，待補隔音下限數值後改寫 |
| 缺口依章節順序列出 | **依對佩戴感的影響排序**（第 7 節） |

---

## 9. 這份定義本身的限制

- **成果層與影響層之間的連結未經驗證。** 即使 S1–S5 全數通過，也不保證使用者實際更舒適——舒適還受個體差異、期望值、品牌與價格等本指引管不到的因素影響。**本文件只主張到成果層。**
- **S1 的歸類含人為判斷**（「這個原因算不算事先可知」）。建議由非指引作者執行歸類。
- **★ 第 2 節的推論建立在 n=30 的負面結果上，這是本文件最可能被推翻的一段。** 「未達顯著」是弱證據，不等於「無關聯」。若日後出現更大樣本顯示耳部尺寸確實可預測舒適度，**第 2 節與第 4 節的路徑劃分都要重寫。** 先標明，避免它被當成已確立的事實沿用。

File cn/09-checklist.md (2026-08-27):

# Part 9 — 檢查清單

狀態：初稿 ｜ 最後更新 2026-08-21

> 🌐 日本語版：[jp/09-checklist.md](../jp/09-checklist.md)

## 這份清單是給誰用的

**使用者＝拿這份指引做設計的人。** 他做出 3D 模型後，逐項對照本清單自我檢查。

**這不是一份要交回給需求方回答的問卷。** 清單是交付物的一部分，不是撰寫交付物的前置條件。

清單分兩種性質的條目，請分開看：

| 區段 | 性質 | 誰在什麼時候處理 |
|---|---|---|
| **A. 場景前提** | **專案範圍決策** | **需求方在專案開工前拍板**，之後不再更動。只有 3–4 題 |
| **B–H** | **模型檢查項** | **設計者在模型完成後**逐項核對自己的模型 |

標記說明：
- 「⛔」＝**否決項**：不合格則產品不可用，不是扣分
- 「⏳」＝**目前尚無數值門檻**，本指引只能給方法，需實測補齊
- 「**⚑**」＝**閘門條目**｜「**◆**」＝**形式約束**：見下方

**每一項都是可判定的**——答得出是／否；答不出就表示該項資訊不足，那本身就是結論。

### 0. 這些規範本身的索引——依「什麼時候用得到」排，不是一張長清單

**規範層在一天內長到五條，每一條都有實際來由。但規則多到一定程度，遵守會悄悄變成選擇性遵守，而選了哪幾條是看不見的。** 那會讓規範層出現我們一直在防的同一個現象：**看起來都有規則，實際沒人全用，且比沒有規則更難察覺，因為文件上證據齊全。**

**處置不是刪規則，是把每一條綁到它的觸發時機。** 只在做某件事時才適用的規則，做別件事時不佔腦容量。

| 你正在做什麼 | 適用哪幾條 | 這條擋掉的實際錯誤 |
|---|---|---|
| **寫一條新條目** | 「不作為預設值必須落在失敗側」 | 5.2-6「未使用亥姆霍茲」——設計者什麼都不做也算通過，形同虛設 |
| **標記一條條目** | ⚑ 閘門辨識法｜◆ 形式約束（可與 ⚑ 並存） | 6C-2-1 若只能二選一，會丟掉「Shore A 與 00 不可互比」這一半 |
| **閘門判定之後** | 三種標記狀態（不可判定／不適用／待補） | 開口 <0.5mm 時若把孔徑條目標「不可判定」，會留下永遠關不掉的假洞 |
| **跨章引用另一章的條目** | 否定式必須配肯定式＋明寫前置 | 「擺放方向未牴觸孔軸」單獨存在時，孔軸從沒被指定的設計會安靜通過 |
| **把某來源的結論搬到另一個領域用** | **貼給目的地領域的負責人看一眼再用**（見下方） | 三次搬運錯誤全部由**目的地**抓到，搬運者一次都沒自己發現 |
| **門檻值拿不到時** | 先固定形式（◆），不要留白也不要等——**但要先確認形式本身可固定，判準見下** | P9-A：未定的不只是門檻，還有該看哪一段頻段 |
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

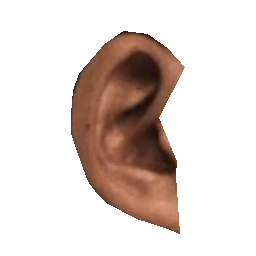
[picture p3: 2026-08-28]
004/masked_right.png

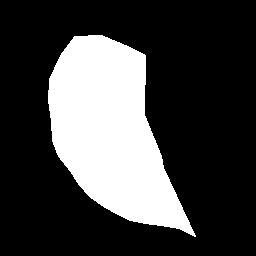
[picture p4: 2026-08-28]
004/mask_left.jpg

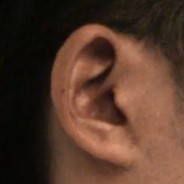
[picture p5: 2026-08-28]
004/right.jpg

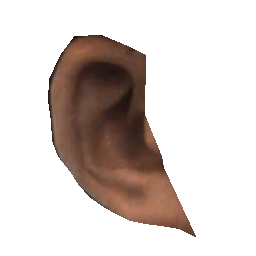
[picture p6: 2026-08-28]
004/masked_left.png

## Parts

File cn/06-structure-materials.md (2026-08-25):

# Part 6 — 結構與材料（含 3D 列印性）

狀態：已驗收 ｜ 最後更新 2026-08-21

> 🌐 日本語版：[jp/06-structure-materials.md](../jp/06-structure-materials.md)

**範圍**：可製造性限定於「3D 印表機印得出來」，不含量產模具工藝（需求方 2026-08-21 指示）。

> **用語規範**：耳部與醫學名詞一律中文在前、英文於括號內，例如 耳屏（tragus）。

---

## A. 列印性（依製程分列）

| 條目 | 數值／門檻 | 來源等級 | 來源出處 | 備註 |
|---|---|---|---|---|
| FDM 穩定壁厚下限 | ≥1.0–1.2mm；結構承力件建議 ≥2.0mm | 【慣例】 | 市場商品統計：Hubs／Protolabs Network、3D On Demand 等列印代工商 DFM 指南 | 多家代工商彙整慣例，**非正式 ISO/ASTM 標準** |
| SLA 穩定壁厚下限 | 0.4–0.6mm | 【慣例】 | 同上 | 同上 |
| FDM 免支撐懸空角度上限 | 45°（自垂直方向起算） | 【慣例】 | 同上 | 超過需支撐 |
| SLA 免支撐懸空角度上限 | 30°，且懸空長度 ≤2mm | 【慣例】 | 同上 | — |
| FDM 最小特徵尺寸 | 0.5mm | 【慣例】 | 同上 | 薄邊／小孔／細柱 |
| SLA 最小特徵尺寸 | 0.2mm | 【慣例】 | 同上 | — |
| 支撐可移除性門檻 | **未查到可量化通用數字** | 【假設待驗】 | — | 未找到「內腔開口需 ≥X mm 才能取出支撐」這類可查證門檻。設計原則：耳殼內腔避免全封閉盲孔，或改用可溶性支撐材（如 PVA）。需拿實際列印測試件驗證，**不編數字** |
| FDM 彈性材（TPU）可印硬度範圍 | Shore A 60–95（商用線材如 NinjaFlex 約 85A） | 【文獻】 | 市場商品統計：TPU 線材供應商規格（NinjaFlex）、Fictiv／Wevolver 綜合指南 | — |
| SLA/DLP 彈性樹脂可印硬度下限 | 約 Shore A 43–50（Liqcreate Elastomer-X 43A、Forerunner3D Elastic 50A Resin） | 【文獻】 | 市場商品統計：樹脂供應商規格 | — |

#### A-2 孔徑、列印方向（2026-08-25 新增）

| 條目 | 數值／門檻 | 來源等級 | 來源出處 | 備註 |
|---|---|---|---|---|
| **最小孔徑（正本）** | FDM 水平孔 **≥2.0mm**；沿列印 Z 軸垂直孔 **≥1.0mm** | 【慣例】 | 市場商品統計：列印代工商 DFM 指南彙整 | 小於此值 FDM 傾向糊死封閉。⚠️ **與最小特徵尺寸（0.5mm）不同**——後者適用薄壁／細柱，**不可用於孔**。截面積下限相差約 16 倍 |
| **孔徑印小量（正本）** | 10mm 以下孔實印偏小 **2–4%**（設計 5mm→實測約 4.8mm） | 【慣例】 | 同上 | CAD 端補償公式見 [Part 5.2.1](05-acoustic-constraints.md#sec-5-2-1)（僅洩壓式需要，f₀ 為聲學目標） |
| **整機列印擺放方向** | **非自由變數。** 受 [Part 5.2.3](05-acoustic-constraints.md#sec-5-2-3) 孔軸要求約束（孔軸應平行列印 Z 軸） | 條文 | 交叉參照 Part 5 | **因減支撐／表面品質／強度／翹曲等 DFM 理由變更擺放時，須回頭確認孔軸仍滿足 Part 5。** 水平孔內部支撐若不可移除＝**聲學路徑失效**，非精度劣化 |
| 多孔陣列間距下限 | 孔壁 ≥1.0–1.2mm（FDM 最小壁厚） | 【慣例】 | 同上 | 決定中心距/半徑與孔隙率的可行範圍，供 Part 5 多孔缺口引用 |
| **幾何熱膨脹：已評估，不顯著** | 20→37°C 下 2.0mm 孔變化 **≤0.007mm**（取 TPU CTE 200×10⁻⁶/K 為上界；PLA／PETG／ABS 更小） | 【計算｜輸入：常數】 | 熱塑膠 CTE 通用值 | **比印小量（0.04–0.08mm）小一個數量級，可忽略。列此條是為記錄「已評估並排除」，避免重複提問** |

#### A-3 開口尺寸的製造分帶——決定它是「孔特徵」還是「組裝間隙」

| 縫高／孔徑 | 製造可行性 | 性質變化 |
|---|---|---|
| **< 0.5mm** | **不能作為列印孔洞特徵存在**（低於最小特徵尺寸，FDM 糊死、SLA 邊緣不可靠） | ⚠️ **必須改由組裝間隙產生**——變成公差堆疊問題，不是設計特徵 |
| 0.5–1.0mm | 僅沿列印 Z 軸垂直孔勉強可行；水平孔不可 | 列印方向被鎖死，與 Part 5 孔軸條文耦合 |
| ≥ 1.0mm | 垂直孔可靠 | 一般設計特徵 |
| ≥ 2.0mm | 水平孔亦可靠 | 擺放方向自由度回來 |

> ⛔ **第一帶（<0.5mm）是性質改變，不是尺寸變小。**
> - 尺寸由**公差堆疊**決定而非 CAD 標稱值 → **每一件的實際開口不同**
> - 若該開口承擔安全功能，關鍵尺寸交給公差控制 → **無法以型式驗證涵蓋，須逐件檢驗**
> - 檢驗項目是**基頻聲學傳輸量而非尺寸**（見 [Part 5.4.2](05-acoustic-constraints.md#sec-5-4-2)）——逐件聲學量測與逐件量尺寸的產線成本不同量級
> - 它同時是 [Part 5.3](05-acoustic-constraints.md#sec-5-3) 的漏氣路徑，且屬**件與件之間**的變異，同件重複量測涵蓋不到（見 [5.3.2](05-acoustic-constraints.md#sec-5-3-2)）
>
> **落入第一帶時，本章要寫的是「組裝間隙公差條文」而非「孔特徵條文」——完全不同的一組要求。**

#### A-4 ⛔ 缺口登記：電源預算 vs 可用體積（本輪新發現）

| 條目 | 內容 | 來源等級 | 備註 |
|---|---|---|---|
| 衝突的形式 | 整夜 6–9 小時連續運行所需電池容量 **vs** 耳甲（cavum conchae）淨空間——耳甲深度實測平均 **9.15mm**（n=56，見 [Part 2.4](02-anthropometric-basis.md#sec-2-4)）扣掉殼壁與驅動器後所剩 | 【推論】 | **可能直接否決入耳式架構——不是舒適度問題，是塞不下** |
| ★ 與聲學耦合 | 電池與**後腔 V_back 搶同一塊體積**。V_back 直接決定低頻滾降——後腔越小、等效柔量越小、低頻滾降頻率越高 | 【推論】 | 而低頻同時是**遮蔽音的能量所在**與**安全警報的關鍵頻段**（若為低頻警報） |
| **⛔ 求解方式** | **元件候選清單到位後，電源預算與聲學腔體預算必須聯合求解，不得各自獨立計算後相加** | 條文 | 否則兩邊各自宣告可行、合起來不可行 |
| **唯一待補** | **元件候選清單**（麥克風、SoC／藍牙方案、電池化學與封裝形式、驅動器） | 【缺口】 | **不需付費文獻，只需產品端決定選型方向。** 取得後可算出可判定的電源與體積預算，直接回答「入耳式在整夜情境下做不做得到」 |

### ★ 關鍵發現：列印做不到睡眠耳塞所需的超軟硬度

桌面級 3D 列印彈性材（FDM TPU 60–95A、SLA 彈性樹脂 43–80A）**印不到** C 段所列市售睡眠耳塞常見的超軟區間（Shore A 10–20）。

若要做到最軟等級的接觸面，**列印無法直接達成**，須採複合方案。見 C 段。

## B. 外殼硬質材料族

| 條目 | 內容 | 來源等級 | 來源出處 | 備註 |
|---|---|---|---|---|
| FDM 候選材料 | PLA／PETG／ABS | 【慣例】 | 材料工程通識 | 未查到專門針對「睡眠耳機殼體」的選材文獻。PETG 韌性與尺寸穩定性通常優於 PLA；ABS 耐衝擊但翹曲風險較高。此為通用材料特性，非特定產品數據 |
| SLA 候選材料 | 標準／韌性樹脂（Rigid／Tough Resin） | 【慣例】 | 同上 | — |

## C. 接觸面軟質材料 — 硬度範圍

| 條目 | 數值／門檻 | 來源等級 | 來源出處 | 備註 |
|---|---|---|---|---|
| **主方案：複合結構（列印硬殼＋外購軟塞）** | 接觸面硬度可達 Shore A 10–20 | 【單一來源脈絡，待交叉驗證】 | 市場資訊：audioreviews.org 分類語句；soundcore 產品頁、Alibaba 採購指南使用相同分類，**均無獨立原廠規格佐證** | **推薦方案。** 不違反「印得出來」前提——僅硬殼需列印，軟塞外購，整體不需開模 |
| **備案：純列印** | 接觸面硬度下限約 Shore A 43–50 | 【文獻】 | 市場商品統計：Liqcreate、Forerunner3D 樹脂供應商規格 | **代價**：43–50A 遠高於睡眠耳塞常見的 10–20A，長時間側睡壓迫感明顯增加。此方案犧牲舒適度換取「全部自印」，由設計者自行決定 |
| 一般矽膠耳塞（silicone eartip）硬度範圍（背景參考） | Shore A 10–90，常見耳道密封舒適區間 40–60A | 【文獻】 | 市場商品統計：audioreviews.org IEM 矽膠耳塞指南、矽膠製造商規格指南 | — |
| 記憶棉（memory foam）／軟凝膠（soft gel）耳塞 | 應以 **Shore 00** 標度量測，非 Shore A | 【假設待驗】 | — | Shore 00 用於凝膠／泡棉為業界通則，但未查到記憶棉耳塞具體 Shore 00 數值（Comply 等廠商未公開）。**數值留空** |
| Shore A／00／D 測量標準 | ASTM D2240（現行版 D2240-15(2021)） | 【文獻】 | 業界標準：ASTM International。已查得 store.astm.org 官方條目，並經 ZwickRoell／Intertek／Smithers 等獨立檢測機構描述互相印證 | 涵蓋 A/B/C/D/DO/E/M/O/OO/OOO/OOO-S/R 共十二種標度 |

#### C-2 硬度的溫度基準（2026-08-25 新增）

| 條目 | 內容 | 來源等級 | 來源出處 | 備註 |
|---|---|---|---|---|
| 硬度值溫度基準 | C 段所有 Shore 硬度值為**室溫**規格值（ASTM D2240 標準測試條件） | 【文獻】 | 業界標準：ASTM International | — |
| **⛔ 缺口登記：皮膚溫下硬度偏移** | 彈性體模數隨溫度上升而下降 → 皮膚溫下實際**比室溫規格值更軟**。**方向確定，幅度未評估**（Shore 硬度溫度係數無可核驗來源，廠商規格書通常只給單一溫度點） | 【缺口】 | — | ⚠️ **不可當保守估計帶過，兩個方向指向相反結論**：舒適面有利（實際接觸壓力低於室溫硬度算出的值），**固位面不利**（夾持力衰減，長時佩戴的固位餘裕比室溫估計樂觀） |
| 跨章後果 | 本缺口不限於材料選型，**另約束 [Part 5.3](05-acoustic-constraints.md#sec-5-3) 漏氣路徑量測狀態**——耳塞變軟改變密封幾何，代表狀態須為**熱平衡後**而非剛佩戴 | 【推論】 | 交叉參照 [Part 5.3.1](05-acoustic-constraints.md#sec-5-3-1) | 此論證不需硬度溫度係數的數值即成立 |

> ⚠️ **Shore A 與 Shore 00 是不同標度，數值不可互相比較。** 記憶棉、軟凝膠常用 Shore 00；一般矽膠用 Shore A。這是本主題最常見的錯誤。

> ⚠️ **10–20A 這個數字強度不足。** 多個網路來源使用相同分類語句，看不出各自獨立量測，比較像同一套內容互相轉載；且有來源明確指出「沒有廠商穩定公開 Shore A 數值」。**不宜當作已確認數字使用。**

## D. 硬度與接觸壓迫感的關係

| 條目 | 內容 | 來源等級 | 來源出處 | 備註 |
|---|---|---|---|---|
| 定性關係 | 硬度越低，相同幾何過盈量下界面接觸壓力越低（彈性模量與壓力正相關） | 【假設待驗】 | — | 未查到耳機／耳塞領域量化的硬度—壓力對應數據，**不編公式** |
| **耳屏（tragus）為壓力最敏感區** | 耳甲（concha）六個量測點中耳屏壓力不適閾值（pressure discomfort threshold, PDT）最低；性別、左右對稱性、身體質量指數（BMI）對閾值無顯著影響（80 名受試者） | 【文獻】 | 學術論文：Yuan, X. et al., *Measurement of pressure discomfort threshold in auricular concha for in-ear wearables design*, Applied Ergonomics, 2023, 113: 104078. DOI: [10.1016/j.apergo.2023.104078](https://doi.org/10.1016/j.apergo.2023.104078) | 摘要已核；全文付費牆，**絕對數值未取得** |
| 架構接口 | PDT 給可承受壓力上限 → 硬度＋幾何過盈量算出實際接觸壓力 → 兩者比對。**壓在耳屏（tragus）的結構，壓力門檻取全機最低** | 【推論】 | 本團隊架構推論，非文獻直述 | 接口先留好，待 PDT 絕對數值或實測壓力數據補上再計算 |

#### D-2 接觸壓力判準（2026-08-25 新增，取代原本無門檻的定性描述）

| 條目 | 數值／門檻 | 來源等級 | 來源出處 | 備註 |
|---|---|---|---|---|
| **接觸壓力判準** | **每一接觸斑塊各自滿足 A_i ≥ F_i / PDT(該部位)** | 【推論】 | 力學定義（壓力＝力／面積）＋交叉參照 [Part 3](03-sensitive-zones.md) | ⚠️ **逐斑塊，不可用總面積。** 總面積大但有一道稜線扛掉大部分載荷者，用總和算會過關而實際會痛。**承載分佈未知時取最不利分佈** |
| 圓角半徑 | 接觸區不得存在 R < X 的稜線，X 待 PDT 分區值定案後反推 | 【推論】 | 同上 | 圓角半徑是同一關係的幾何手段：R 越小→接觸面積越小→壓力越高 |
| **耳屏（tragus）特例** | **⛔ 禁置，不是「面積算夠大即可」** | 【文獻】 | 交叉參照 [Part 3](03-sensitive-zones.md)；Yuan et al. 2023（耳甲六點中耳屏 PDT 最低） | 兩個獨立理由：壓力最敏感區 ＋ 下顎活動變形區（見 [Part 1A](01a-posture-analysis.md)） |
| **⛔ 唯一待補** | **PDT 絕對值分區表** | 【缺口】 | Yuan, X. et al., *Applied Ergonomics* 2023, 113:104078（全文付費牆，僅取得相對排序） | **取得後本節三條全部轉為可判定。** 目前全案槓桿最高的單一取得項——同時關掉接觸面幾何門檻與全案壓力上限 |

> **這一節示範了本專案處理缺口的標準做法**：不留白，改寫成**可判定形式 ＋ 標出唯一缺的量**。留白會被讀成「沒有限制」；可判定形式讓缺口變成可採購、可實測的明確目標。**但降級不等於關閉**——PDT 數值填上前，這三條仍無法真正判定。

交叉參照：[Part 3 耳部敏感區與禁置區](03-sensitive-zones.md)

## E. 耐久

| 條目 | 數值／門檻 | 來源等級 | 來源出處 | 備註 |
|---|---|---|---|---|
| 彈性材耐磨測試方法 | ASTM D5963（旋轉鼓式磨耗，現行版 D5963-22） | 【文獻】 | 業界標準：ASTM International（已查官方條目） | 涵蓋硫化橡膠與熱塑性彈性體，適用矽膠／TPU |
| 硬殼表面耐磨測試方法 | ASTM D4060（Taber 磨耗試驗） | 【文獻】 | 同上 | 主要用於塗層／硬質平面。**不要與 D5963 混用**，本條只適用硬殼表面塗層 |
| 汗液／皮脂化學耐受測試方法 | ASTM D471（橡膠耐液體性能，現行版 D471-16a(2021)） | 【文獻】 | 同上 | 可用人工汗液／皮脂模擬液作介質。**未查到專為「睡眠耳機汗液耐受」訂製的標準編號** |
| 清潔劑（異丙醇）耐受 | 偶爾（非每日）70% IPA 擦拭矽膠一般安全；每日／長期使用會導致表面霧化、變硬或膨脹 | 【慣例】 | 市場資訊：矽膠保養指南類網站 | **非原廠技術規格書等級來源**，建議以矽膠原廠 SDS／化學相容性表交叉驗證 |

> ⚠️ **ISO 105-E04 是紡織品染色牢度測試，不適用於矽膠／塑膠材料本身的劣化評估。** 常見誤用，勿引。

## F. 整夜佩戴熱與透氣（材料層面）

| 條目 | 數值／門檻 | 來源等級 | 來源出處 | 備註 |
|---|---|---|---|---|
| 閉孔泡棉熱導率 | ≤0.026 W/(m·K) | 【文獻】 | 市場／技術資訊：保溫材料產業比較資料 | 來自保溫材料產業，非耳機專用，**數量級參考** |
| 開孔泡棉熱導率 | ≤0.036 W/(m·K)（較高＝透氣較佳） | 【文獻】 | 同上 | 同上 |
| 記憶棉 vs 乳膠透氣性 | 標準記憶棉約比天然乳膠低 30–100 倍（CFM 氣流量） | 【文獻】 | 市場資訊：床墊產業比較資料 | 來自寢具產業，非耳機專用，數量級參考。開孔記憶棉可縮小差距 |

體感層面的熱與濕氣累積歸 Part 7 佩戴壓力與舒適。

## G. 組裝方式

| 條目 | 內容 | 來源等級 | 備註 |
|---|---|---|---|
| 常見組裝方式 | 卡扣（snap-fit）／黏著劑接合／螺絲鎖附 | 【慣例】 | 不含模具相關組裝法（如包膠），依範圍排除 |

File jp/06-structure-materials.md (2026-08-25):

# Part 6 — 構造と材料（3D 造形性を含む）

ステータス：受入済 ｜ 最終更新 2026-08-21

**範囲**：製造可能性は「3D プリンタで造形できること」に限定し、量産金型工程は含まない（需求方 2026-08-21 指示）。

> 🌐 中文版：[cn/06-structure-materials.md](../cn/06-structure-materials.md)
> **用語規範**：耳の部位名と医学用語は日本語を先に、英語を括弧内に記す。例：耳珠（tragus）。

---

## A. 造形性（プロセス別）

| 項目 | 数値／しきい値 | 証拠等級 | 出典 | 備考 |
|---|---|---|---|---|
| FDM の安定肉厚下限 | ≥1.0–1.2mm。構造荷重部材は ≥2.0mm を推奨 | 【慣例】 | 市場製品統計：Hubs／Protolabs Network、3D On Demand 等の受託造形業者の DFM ガイド | 複数業者の慣例をまとめたものであり、**正式な ISO/ASTM 標準ではない** |
| SLA の安定肉厚下限 | 0.4–0.6mm | 【慣例】 | 同上 | 同上 |
| FDM のサポート不要オーバーハング角上限 | 45°（垂直方向から起算） | 【慣例】 | 同上 | 超えるとサポートが必要 |
| SLA のサポート不要オーバーハング角上限 | 30°、かつ張り出し長さ ≤2mm | 【慣例】 | 同上 | — |
| FDM の最小フィーチャ寸法 | 0.5mm | 【慣例】 | 同上 | 薄いエッジ／小穴／細い柱 |
| SLA の最小フィーチャ寸法 | 0.2mm | 【慣例】 | 同上 | — |
| サポート除去可能性のしきい値 | **定量化された一般的な数値は見つからず** | 【仮定・要検証】 | — | 「内腔の開口が ≥X mm ないとサポートを取り出せない」といった検証可能なしきい値は見つからなかった。設計原則：耳シェル内腔に完全に閉じた行き止まり穴を作らないか、可溶性サポート材（PVA 等）を用いる。実際の造形テストピースで検証する必要があり、**数値を捏造しない** |
| FDM 弾性材（TPU）の造形可能硬度範囲 | Shore A 60–95（NinjaFlex 等の市販フィラメントは約 85A） | 【文献】 | 市場製品統計：TPU フィラメント供給元の仕様（NinjaFlex）、Fictiv／Wevolver の総合ガイド | — |
| SLA/DLP 弾性樹脂の造形可能硬度下限 | 約 Shore A 43–50（Liqcreate Elastomer-X 43A、Forerunner3D Elastic 50A Resin） | 【文献】 | 市場製品統計：樹脂供給元の仕様 | — |

#### A-2 孔径と造形方向（2026-08-25 追加）

| 項目 | 数値／しきい値 | 証拠等級 | 出典 | 備考 |
|---|---|---|---|---|
| **最小孔径（正本）** | FDM 水平孔 **≥2.0mm**、造形 Z 軸に沿う垂直孔 **≥1.0mm** | 【慣例】 | 市場製品統計：受託造形業者の DFM ガイドの集約 | これを下回ると FDM では潰れて塞がりやすい。⚠️ **最小フィーチャ寸法（0.5mm）とは別物**——後者は薄壁／細柱用であり、**孔に用いてはならない**。断面積の下限で約 16 倍の差 |
| **孔径の縮み量（正本）** | 10mm 以下の孔は実測で **2–4%** 小さくなる（設計 5mm→実測約 4.8mm） | 【慣例】 | 同上 | CAD 側の補償式は [Part 5.2.1](05-acoustic-constraints.md#sec-5-2-1)（開放式のみ必要。f₀ が音響目標であるため） |
| **機体の造形配置方向** | **自由変数ではない。** [Part 5.2.3](05-acoustic-constraints.md#sec-5-2-3) の孔軸要求（孔軸は造形 Z 軸に平行）に拘束される | 条文 | Part 5 と相互参照 | **サポート削減／表面品質／強度／反り等の DFM 上の理由で配置を変更する場合、孔軸が Part 5 を満たすか戻って確認すること。** 水平孔の内部サポートが除去できない場合は**音響経路の失効**であり、精度劣化ではない |
| 多孔配列の間隔下限 | 孔壁 ≥1.0–1.2mm（FDM 最小肉厚） | 【慣例】 | 同上 | 中心距離/半径と開口率の可能範囲を決める。Part 5 の多孔欠落から参照される |
| **幾何の熱膨張：評価済み、有意でない** | 20→37°C で 2.0mm 孔の変化は **≤0.007mm**（TPU の CTE 200×10⁻⁶/K を上界とする。PLA／PETG／ABS はさらに小さい） | 【計算｜入力：定数】 | 熱可塑性樹脂の一般的 CTE | **造形の縮み量（0.04–0.08mm）より一桁小さく、無視できる。本項を残すのは「評価して除外した」ことを記録し、同じ問いの再提起を避けるためである** |

#### A-3 開口寸法の製造帯域——「孔フィーチャ」か「組立隙間」かを決める

| 隙間高さ／孔径 | 製造可能性 | 性質の変化 |
|---|---|---|
| **< 0.5mm** | **造形の孔フィーチャとしては存在できない**（最小フィーチャ寸法未満。FDM は潰れ、SLA もエッジが不安定） | ⚠️ **組立隙間として作るほかない**——設計フィーチャではなく公差積み上げの問題になる |
| 0.5–1.0mm | 造形 Z 軸に沿う垂直孔のみ辛うじて可能。水平孔は不可 | 造形方向が固定され、Part 5 の孔軸条文と結合する |
| ≥ 1.0mm | 垂直孔は確実 | 通常の設計フィーチャ |
| ≥ 2.0mm | 水平孔も確実 | 配置方向の自由度が戻る |

> ⛔ **第 1 帯（<0.5mm）は寸法が小さくなるのではなく、性質が変わる。**
> - 寸法が CAD の呼び値ではなく**公差の積み上げ**で決まる → **個体ごとに実開口が異なる**
> - その開口が安全機能を担う場合、重要寸法を公差管理に委ねることになる → **型式試験では覆えず、全数検査が必要**
> - しかも検査項目は**基本周波数の音響伝達量であって寸法ではない**（[Part 5.4.2](05-acoustic-constraints.md#sec-5-4-2) 参照）——全数の音響測定と全数の寸法測定では産線コストの桁が異なる
> - さらに [Part 5.3](05-acoustic-constraints.md#sec-5-3) の漏れ経路でもあり、**個体間**の変異であるため同一個体の反復測定では覆えない（[5.3.2](05-acoustic-constraints.md#sec-5-3-2) 参照）
>
> **第 1 帯に落ちる場合、本章が書くべきは「孔フィーチャの条文」ではなく「組立隙間の公差条文」であり、まったく別の要求群になる。**

#### A-4 ⛔ 欠落として登録：電源予算 vs 利用可能容積（今回の新発見）

| 項目 | 内容 | 証拠等級 | 備考 |
|---|---|---|---|
| 衝突の形 | 一晩 6〜9 時間の連続動作に必要な電池容量 **vs** 耳甲介（cavum conchae）の正味空間——耳甲介深さの実測平均 **9.15mm**（n=56、[Part 2.4](02-anthropometric-basis.md#sec-2-4) 参照）から肉厚とドライバを差し引いた残り | 【推論】 | **インイヤー型を直接否決しうる——快適性の問題ではなく、収まらないという問題である** |
| ★ 音響との結合 | 電池は**後気室 V_back と同じ容積を奪い合う**。V_back は低域のロールオフを直接決める——後気室が小さいほど等価コンプライアンスが小さくなり、低域ロールオフ周波数が上がる | 【推論】 | 低域は**マスキング音のエネルギーの所在**であり、同時に**安全警報の重要帯域**でもある（低周波警報の場合） |
| **⛔ 解き方** | **部品候補リストが揃った時点で、電源予算と音響容積予算は連立で解くこと。それぞれ独立に計算して足し合わせてはならない** | 条文 | さもなければ双方が個別に「可能」と宣言し、合わせると不可能になる |
| **唯一の不足** | **部品候補リスト**（マイク、SoC／Bluetooth 方式、電池の化学種とパッケージ形態、ドライバ） | 【欠落】 | **有料文献は不要。製品側が選定方針を決めればよい。** 揃えば判定可能な電源・容積予算を算出でき、「インイヤー型は一晩のシーンで成立するか」に直接答えられる |

### ★ 重要な発見：造形では睡眠用イヤーチップに必要な超軟質硬度に到達できない

デスクトップ級 3D プリントの弾性材（FDM TPU 60–95A、SLA 弾性樹脂 43–80A）は、C 節に挙げる市販睡眠用イヤーチップに一般的な超軟質域（Shore A 10–20）に**到達できない**。

最も柔らかい等級の接触面を実現するには、**造形だけでは達成できず**、複合方式を採る必要がある。C 節参照。

## B. シェル用硬質材料

| 項目 | 内容 | 証拠等級 | 出典 | 備考 |
|---|---|---|---|---|
| FDM の候補材料 | PLA／PETG／ABS | 【慣例】 | 材料工学の一般知識 | 「睡眠用イヤホンのシェル」に特化した材料選定文献は見つからなかった。PETG は靭性と寸法安定性が通常 PLA より優れる。ABS は耐衝撃性が高いが反りのリスクが大きい。これは一般的な材料特性であり特定製品のデータではない |
| SLA の候補材料 | 標準／強靭樹脂（Rigid／Tough Resin） | 【慣例】 | 同上 | — |

## C. 接触面の軟質材料 — 硬度範囲

| 項目 | 数値／しきい値 | 証拠等級 | 出典 | 備考 |
|---|---|---|---|---|
| **主案：複合構造（硬質シェルを造形＋軟質チップを外部調達）** | 接触面硬度は Shore A 10–20 に到達可能 | 【単一出典の文脈、相互検証が必要】 | 市場情報：audioreviews.org の分類記述。soundcore 製品ページ、Alibaba の調達ガイドも同じ分類を用いるが、**いずれも独立したメーカー仕様の裏付けがない** | **推奨案。**「造形できること」という前提に反しない——造形が必要なのは硬質シェルのみで、軟質チップは外部調達。全体として金型は不要 |
| **代替案：完全造形** | 接触面の硬度下限は約 Shore A 43–50 | 【文献】 | 市場製品統計：Liqcreate、Forerunner3D の樹脂仕様 | **代償**：43–50A は睡眠用イヤーチップに一般的な 10–20A よりはるかに硬く、長時間の横向き寝で圧迫感が明確に増す。本案は快適性を犠牲にして「すべて自前で造形する」ことを取るものであり、設計者の判断に委ねる |
| 一般的なシリコーンイヤーチップ（silicone eartip）の硬度範囲（背景参考） | Shore A 10–90。外耳道密閉で快適とされる一般的な範囲は 40–60A | 【文献】 | 市場製品統計：audioreviews.org の IEM シリコーンチップガイド、シリコーンメーカーの仕様ガイド | — |
| 低反発フォーム（memory foam）／軟質ゲル（soft gel）チップ | **Shore 00** スケールで測定すべきであり、Shore A ではない | 【仮定・要検証】 | — | ゲル／フォームに Shore 00 を用いるのは業界の通例だが、低反発チップの具体的な Shore 00 値は見つからなかった（Comply 等のメーカーは非公開）。**数値は空欄のままとする** |
| Shore A／00／D の測定標準 | ASTM D2240（現行版 D2240-15(2021)） | 【文献】 | 業界標準：ASTM International。store.astm.org の公式項目を確認し、ZwickRoell／Intertek／Smithers 等の独立試験機関の記述と相互に裏付けた | A/B/C/D/DO/E/M/O/OO/OOO/OOO-S/R の 12 スケールを規定 |

#### C-2 硬度の温度基準（2026-08-25 追加）

| 項目 | 内容 | 証拠等級 | 出典 | 備考 |
|---|---|---|---|---|
| 硬度値の温度基準 | C 節のすべての Shore 硬度値は**室温**の規格値である（ASTM D2240 の標準試験条件） | 【文献】 | 業界標準：ASTM International | — |
| **⛔ 欠落として登録：皮膚温での硬度シフト** | エラストマーの弾性率は温度上昇とともに低下する → 皮膚温では実際に**室温規格値より柔らかい**。**方向は確定、幅は未評価**（Shore 硬度の温度係数に検証可能な出典がなく、メーカー仕様書は通常 1 点の温度しか示さない） | 【欠落】 | — | ⚠️ **保守的な見積もりとして流してはならない。2 つの方向が逆の結論を指す**：快適性には有利（実接触圧が室温硬度から算出した値より低い）、**保持には不利**（挟持力が減衰し、長時間装着での保持余裕が室温の見積もりより楽観的になる） |
| 章をまたぐ帰結 | 本欠落は材料選定にとどまらず、**[Part 5.3](05-acoustic-constraints.md#sec-5-3) の漏れ経路の測定状態も拘束する**——イヤーチップが柔らかくなれば密閉幾何が変わるため、代表状態は装着直後ではなく**熱平衡後**とすること | 【推論】 | [Part 5.3.1](05-acoustic-constraints.md#sec-5-3-1) と相互参照 | この論証は硬度の温度係数の数値がなくても成立する |

> ⚠️ **Shore A と Shore 00 は異なるスケールであり、数値を相互比較してはならない。** 低反発フォームと軟質ゲルには Shore 00、一般的なシリコーンには Shore A を用いる。これは本主題で最も多い誤りである。

> ⚠️ **10–20A という数値は強度が不十分である。** 複数のネット上の情報源が同一の分類記述を用いており、それぞれが独立に測定した形跡が見えず、同一内容の転載に近い。加えて「メーカーが Shore A 値を安定して公開してはいない」と明記する情報源もある。**確認済みの数値として用いるべきではない。**

## D. 硬度と接触圧迫感の関係

| 項目 | 内容 | 証拠等級 | 出典 | 備考 |
|---|---|---|---|---|
| 定性的関係 | 硬度が低いほど、同一の幾何的締め代における界面接触圧は低くなる（弾性率と圧力は正の相関） | 【仮定・要検証】 | — | イヤホン／イヤーチップ分野で定量化された硬度—圧力の対応データは見つからなかった。**式を捏造しない** |
| **耳珠（tragus）が最も圧迫に敏感な領域** | 耳甲介（concha）6 測定点のうち耳珠の圧迫不快閾値（pressure discomfort threshold, PDT）が最も低い。性別、左右対称性、体格指数（BMI）は閾値に有意な影響を与えない（被験者 80 名） | 【文献】 | 学術論文：Yuan, X. et al., *Measurement of pressure discomfort threshold in auricular concha for in-ear wearables design*, Applied Ergonomics, 2023, 113: 104078. DOI: [10.1016/j.apergo.2023.104078](https://doi.org/10.1016/j.apergo.2023.104078) | 要旨は確認済み。全文は有料の壁の内側で、**絶対値は未取得** |
| アーキテクチャ上の接続点 | PDT が許容圧力の上限を与える → 硬度＋幾何的締め代から実際の接触圧を算出する → 両者を照合する。**耳珠（tragus）を押す構造の圧力しきい値は全機で最低とする** | 【推論】 | 当チームのアーキテクチャ上の推論であり、文献の直接の記述ではない | 接続点だけ先に用意しておき、PDT の絶対値または実測圧力データが揃った時点で計算する |

#### D-2 接触圧の判定基準（2026-08-25 追加。しきい値のない定性記述を置き換える）

| 項目 | 数値／しきい値 | 証拠等級 | 出典 | 備考 |
|---|---|---|---|---|
| **接触圧の判定基準** | **各接触パッチが個別に A_i ≥ F_i / PDT(当該部位) を満たすこと** | 【推論】 | 力学の定義（圧力＝力/面積）＋ [Part 3](03-sensitive-zones.md) と相互参照 | ⚠️ **パッチ単位であり、合計面積を用いてはならない。** 合計面積が大きくても一本の稜線が荷重の大半を受ける設計は、合計では合格し実際には痛い。**荷重分布が不明な場合は最不利分布を取る** |
| フィレット半径 | 接触領域に R < X の稜線が存在してはならない。X は PDT の部位別値が確定してから逆算する | 【推論】 | 同上 | フィレット半径は同じ関係の幾何的手段：R が小さいほど接触面積が小さくなり圧力が上がる |
| **耳珠（tragus）の特例** | **⛔ 配置禁止であり、「面積が十分なら可」ではない** | 【文献】 | [Part 3](03-sensitive-zones.md) と相互参照。Yuan et al. 2023（耳甲介 6 点のうち耳珠の PDT が最低） | 独立した 2 つの理由：圧迫に最も敏感な領域であること、および下顎運動による変形領域であること（[Part 1A](01a-posture-analysis.md) 参照） |
| **⛔ 唯一の不足** | **PDT 絶対値の部位別表** | 【欠落】 | Yuan, X. et al., *Applied Ergonomics* 2023, 113:104078（全文は有料の壁の内側。相対順位のみ取得） | **取得すれば本節の 3 条すべてが判定可能になる。** 現時点で案件全体のてこ比が最も高い単一の取得項目——接触面形状のしきい値と案件全体の圧力上限を同時に閉じる |

> **本節は当案件の欠落処理の標準形を示している**：空白のままにせず、**判定可能な形式 ＋ 不足している量の特定**へ書き換える。空白は「制約がない」と読まれるが、判定可能な形式であれば欠落が調達・実測できる明確な目標になる。**ただし格下げは解決ではない**——PDT の数値が埋まるまで、この 3 条は実際には判定できない。

相互参照：[Part 3 耳の敏感領域と配置禁止領域](03-sensitive-zones.md)

## E. 耐久性

| 項目 | 数値／しきい値 | 証拠等級 | 出典 | 備考 |
|---|---|---|---|---|
| 弾性材の耐摩耗試験方法 | ASTM D5963（回転ドラム式摩耗、現行版 D5963-22） | 【文献】 | 業界標準：ASTM International（公式項目を確認済み） | 加硫ゴムと熱可塑性エラストマーを対象とし、シリコーン／TPU に適用可 |
| 硬質シェル表面の耐摩耗試験方法 | ASTM D4060（Taber 摩耗試験） | 【文献】 | 同上 | 主に塗膜／硬質平面に用いる。**D5963 と混用しないこと**。本項は硬質シェル表面の塗膜にのみ適用 |
| 汗／皮脂に対する化学耐性の試験方法 | ASTM D471（ゴムの耐液体性、現行版 D471-16a(2021)） | 【文献】 | 同上 | 人工汗／皮脂模擬液を媒体として使用できる。**「睡眠用イヤホンの耐汗性」専用に定められた規格番号は見つからなかった** |
| 洗浄剤（イソプロピルアルコール）耐性 | 時々（毎日ではない）70% IPA で拭く程度なら一般にシリコーンは安全。毎日／長期の使用は表面の白化、硬化、膨潤を招く | 【慣例】 | 市場情報：シリコーンの手入れガイド系サイト | **メーカー技術仕様書レベルの出典ではない**。シリコーンメーカーの SDS／化学的適合性表で相互検証することを推奨 |

> ⚠️ **ISO 105-E04 は繊維製品の染色堅牢度試験であり、シリコーン／プラスチック材料自体の劣化評価には適用できない。** よくある誤用なので引用しないこと。

## F. 一晩装着時の熱と通気（材料面）

| 項目 | 数値／しきい値 | 証拠等級 | 出典 | 備考 |
|---|---|---|---|---|
| 独立気泡フォームの熱伝導率 | ≤0.026 W/(m·K) | 【文献】 | 市場／技術情報：断熱材業界の比較資料 | 断熱材業界の出典でありイヤホン専用ではない。**桁の参考** |
| 連続気泡フォームの熱伝導率 | ≤0.036 W/(m·K)（高いほど通気性が良い） | 【文献】 | 同上 | 同上 |
| 低反発フォーム vs ラテックスの通気性 | 標準的な低反発フォームは天然ラテックスより約 30–100 倍低い（CFM 通気量） | 【文献】 | 市場情報：マットレス業界の比較資料 | 寝具業界の出典でありイヤホン専用ではない。桁の参考。連続気泡の低反発フォームなら差を縮められる |

体感レベルの熱と湿気の蓄積は Part 7「装着圧と快適性」で扱う。

## G. 組立方式

| 項目 | 内容 | 証拠等級 | 備考 |
|---|---|---|---|
| 一般的な組立方式 | スナップフィット（snap-fit）／接着剤接合／ねじ締結 | 【慣例】 | 金型に関わる組立法（インサート成形等）は範囲外として除外 |

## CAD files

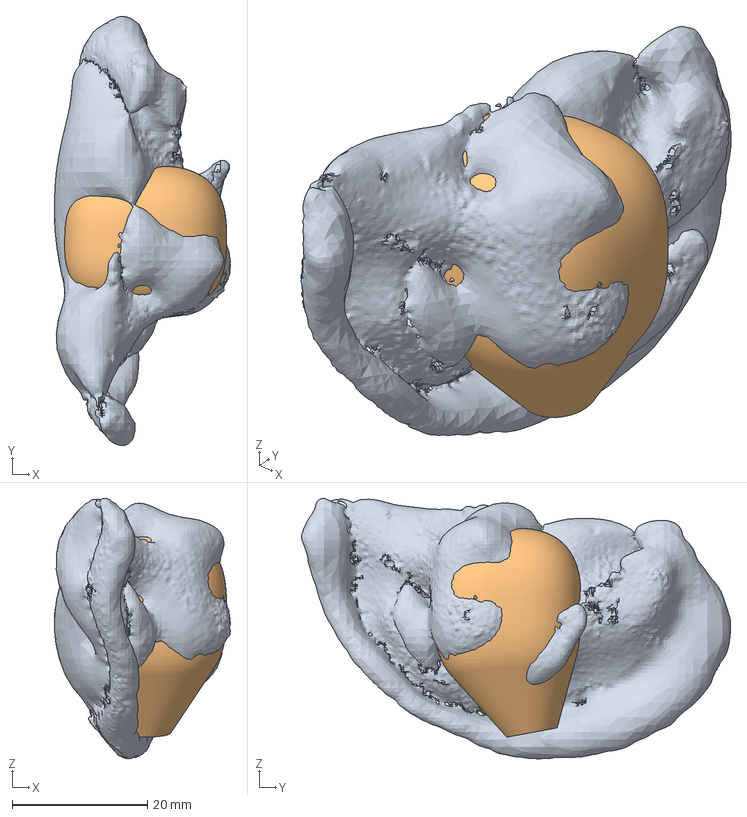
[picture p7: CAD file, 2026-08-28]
004/output/product/airpods_pro_in_ear.FCStd
26.0 x 63.4 x 38.5 mm
Human_Ear_004
Product_AirPods_Pro

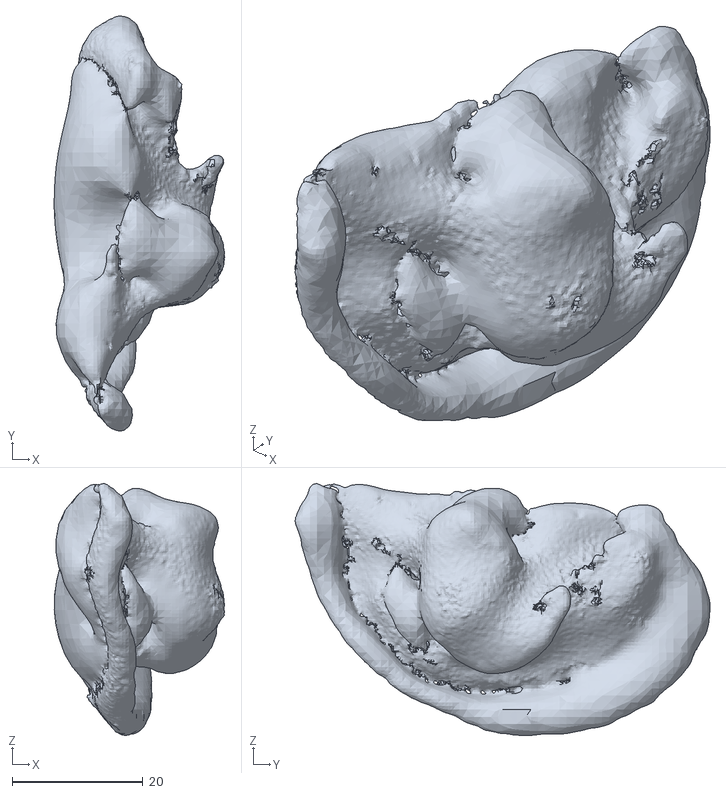
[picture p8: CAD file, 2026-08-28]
004/output/reference_ear/004_real_human_ear_anatomy.stl
26.0 x 63.4 x 38.5

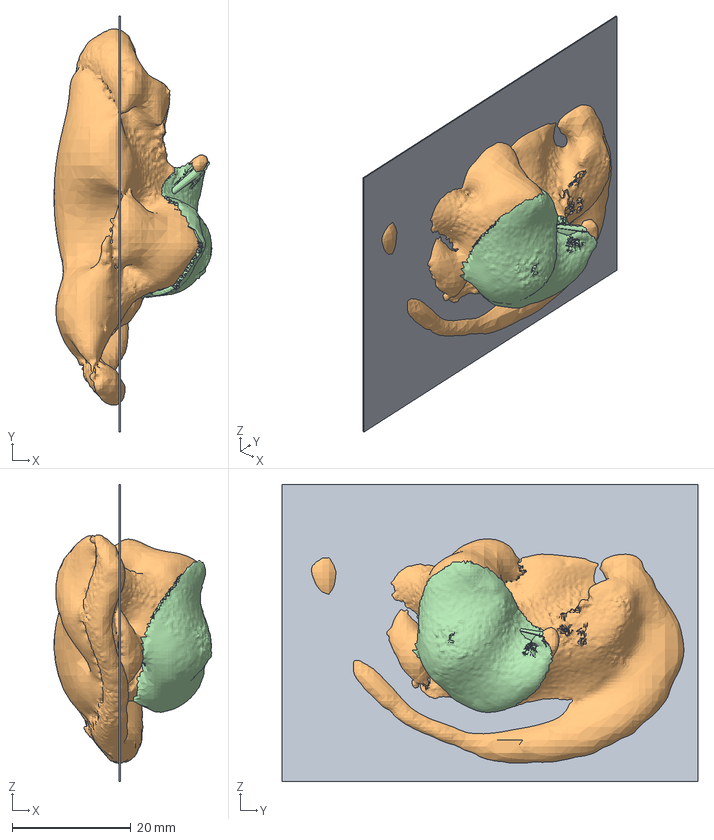
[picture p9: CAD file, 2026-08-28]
004/output/v1_AirPodsPro/004_v1_sleep_earphone_in_ear_simulation.FCStd
26.6 x 70.0 x 50.0 mm
Simulated_Pillow_Plane_Gap_2_0mm
Real_Human_Ear_004_Anatomy_Scan
Rigid_Polymer_Chassis_004_v1
Soft_Silicone_Sleeve_004_v1_ShoreA30

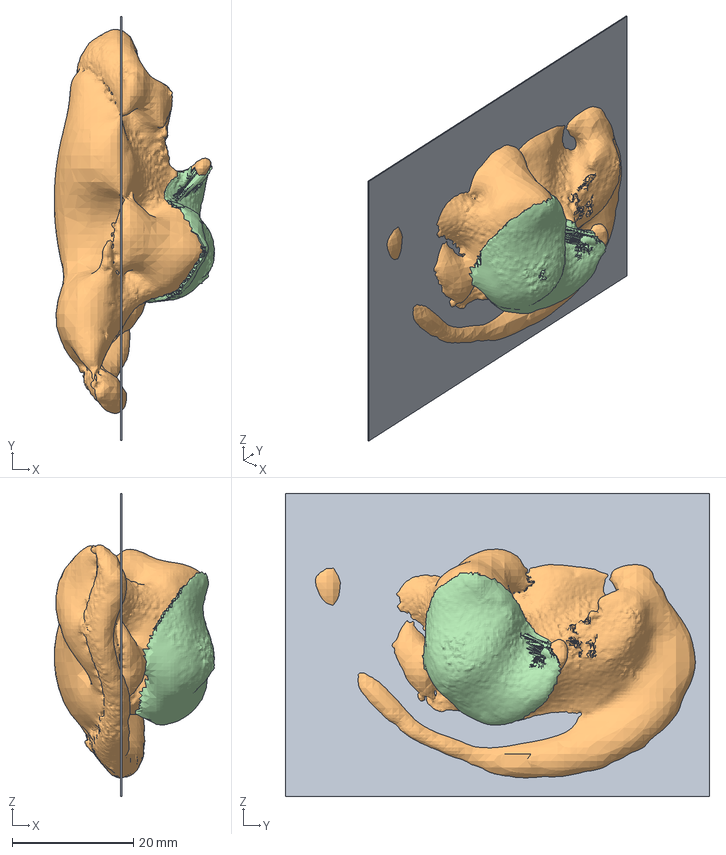
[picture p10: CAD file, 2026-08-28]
004/output/v2_SonyLinkBudsS/004_v2_sleep_earphone_in_ear_simulation.FCStd
26.5 x 70.0 x 50.0 mm
Simulated_Pillow_Plane_Gap_2_5mm
Real_Human_Ear_004_Anatomy_Scan
Rigid_Polymer_Chassis_004_v2
Soft_Silicone_Sleeve_004_v2_ShoreA30

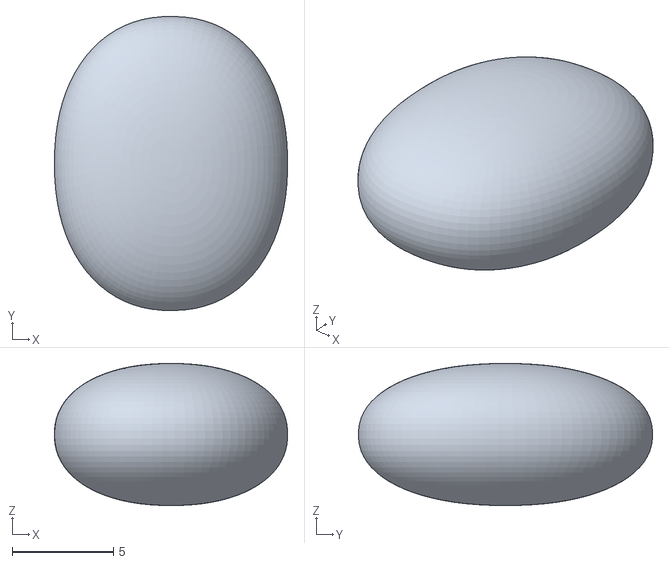
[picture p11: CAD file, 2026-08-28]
004/output/product/airpods_pro_eartip.stl
11.5 x 14.5 x 7.00

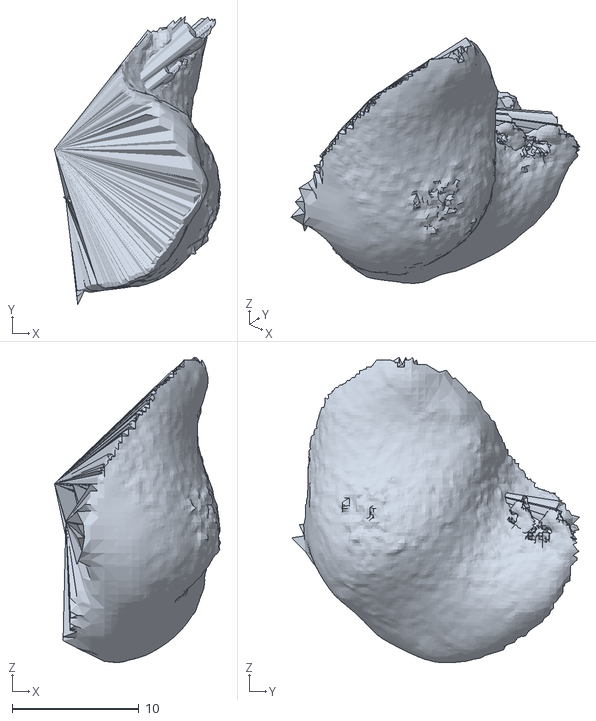
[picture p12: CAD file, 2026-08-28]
004/output/v1_AirPodsPro/004_v1_rigid_chassis_hollow.stl
13.1 x 22.7 x 24.1

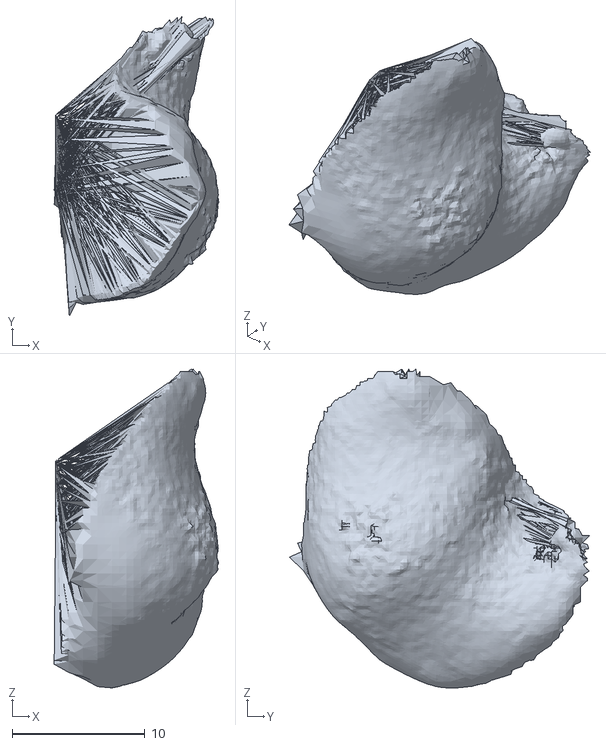
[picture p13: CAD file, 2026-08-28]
004/output/v2_SonyLinkBudsS/004_v2_rigid_chassis_solid.stl
12.4 x 22.6 x 24.1

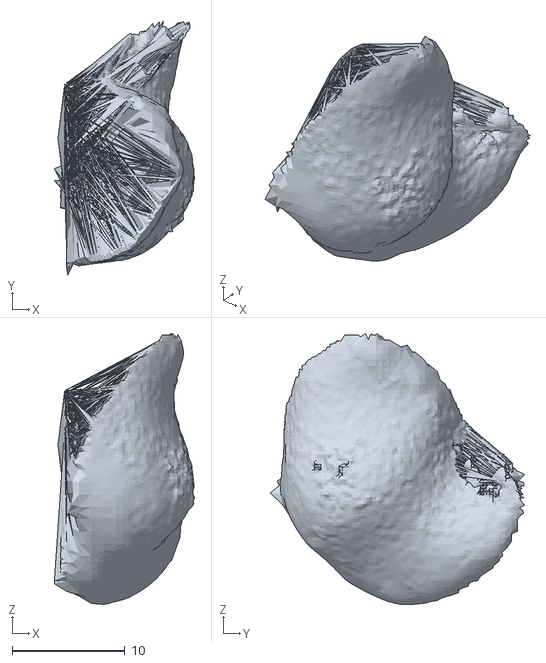
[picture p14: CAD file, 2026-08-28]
004/output/v3_AnkerSleepA30/004_v3_rigid_chassis_hollow.stl
12.4 x 22.5 x 24.0

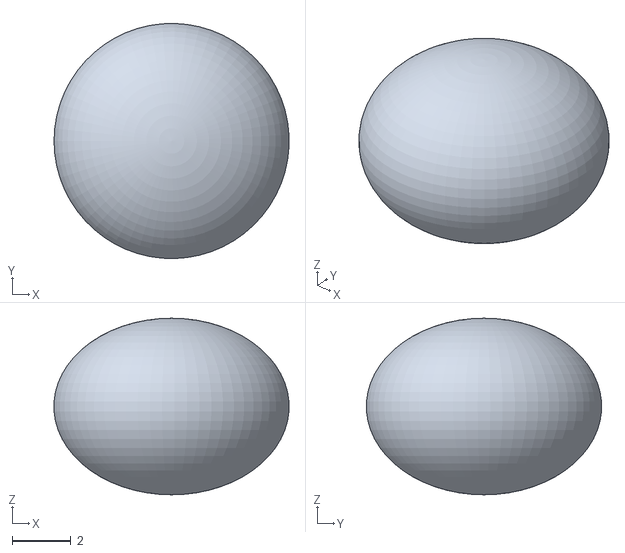
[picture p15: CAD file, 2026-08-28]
004/output/product/anker_soundcore_sleep_a30_eartip.stl
7.98 x 7.99 x 6.00

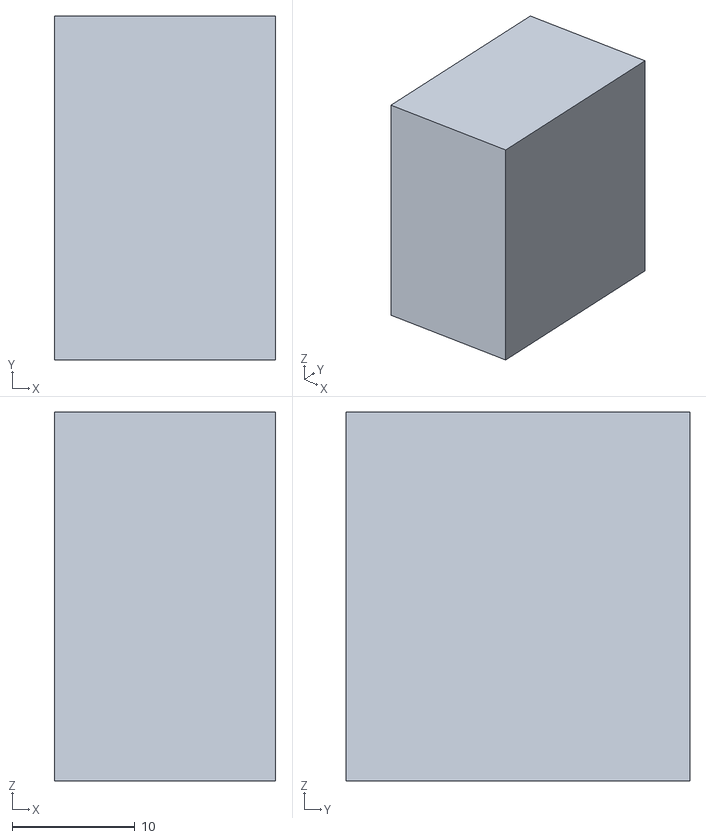
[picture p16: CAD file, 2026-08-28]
004/output/reference_ear/004_ear_negative_mold_box.stl
18.0 x 28.0 x 30.0

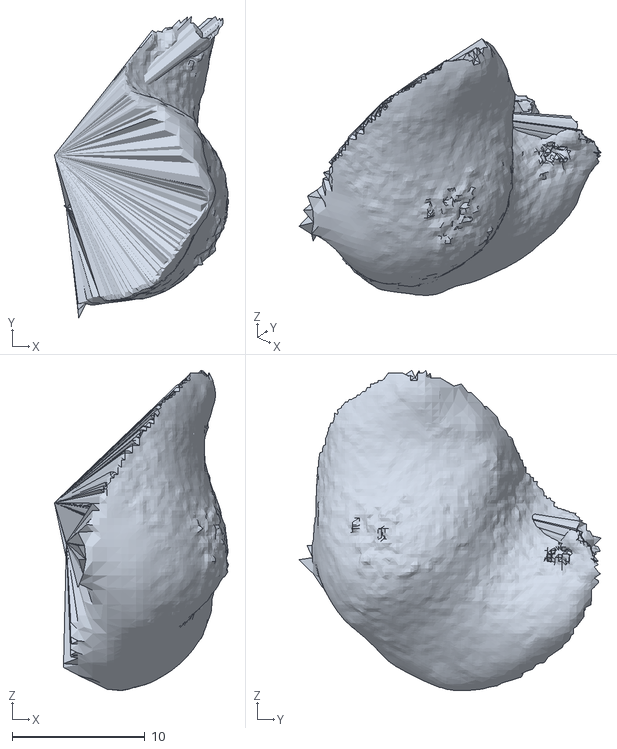
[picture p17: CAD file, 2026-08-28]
004/output/v1_AirPodsPro/004_v1_sleep_earphone_colored.ply
13.1 x 22.7 x 24.1

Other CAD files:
004/v1_AirPodsPro/004_v1_sleep_earphone_assembly.step
004/v2_SonyLinkBudsS/004_v2_sleep_earphone_assembly.step
004/v3_AnkerSleepA30/004_v3_sleep_earphone_assembly.step
004/output/v3_AnkerSleepA30/004_v3_sleep_earphone_in_ear_simulation.FCStd
004/right.ply
004/left.ply
004/output/reference_ear/004_real_human_ear_colored.ply
004/output/product/airpods_pro_body.stl
004/output/product/airpods_pro_right.step
004/output/product/airpods_pro_right.stl
004/output/product/anker_soundcore_sleep_a30_airwing.stl
004/output/product/anker_soundcore_sleep_a30_body.stl
004/output/product/anker_soundcore_sleep_a30_in_ear.FCStd
004/output/product/anker_soundcore_sleep_a30_right.step
004/output/product/anker_soundcore_sleep_a30_right.stl
004/output/product/sony_linkbuds_s_in_ear.FCStd
004/output/product/sony_linkbuds_s_right.step
004/output/product/sony_linkbuds_s_right.stl
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

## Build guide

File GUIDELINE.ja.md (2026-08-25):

# ガイドライン本体——実際の設計規則

**この文書は「何をすべきか」だけを述べる。** 出典、導出過程、限界の議論は各章にあり、ここには結論と数値のみを置く。

各項末尾の → Part X はクリック可能なリンクで、jp/ の該当節に直接ジャンプする。**ガイドラインの中身だけ知りたいなら、この 1 枚で足りる。**

表示：**⛔ 却下項目**（違反すれば製品として成立しない）｜**⏳ 実測待ち**（本ガイドラインは方法を示す。数値は各自の測定で補うこと）

> 🌐 中文版：[GUIDELINE.md](GUIDELINE.md) ｜ 用語対照表：[jp/TERMS.md](jp/TERMS.md)

---

## 0. ⚠️ まず 3 種類の「サイズ」を区別する——文字を共用しない

| 概念 | 表示 | 何に答えるか | 誰が決めるか |
|---|---|---|---|
| **本体バリエーション** | **機種 S／M／L** | この機種の本体をどれだけ大きくするか | **製品判断**（ドライバ／バッテリ／機能トレードオフ） |
| **アクセサリサイズ** | **イヤーチップ／イヤーウィング XS〜L** | この利用者にどのチップを合わせるか | その利用者の耳型に依る |
| **耳型区分** | **耳型区分 I／II／III** | この利用者の耳がどの区分か | **人間工学データ**（A 節） |

> ⛔ **耳型区分には必ずローマ数字 I／II／III を用い、S／M／L を使ってはならない。** 文字の共用が過去に複数回の誤読を招いた根本原因である。
>
> **機種バリエーションと耳型区分は直交する。** 業界標準は 1 つの本体に複数のイヤーチップを組み合わせる方式であり、本体サイズは製品ラインの話、耳の個人差はアクセサリが吸収する。
> → **3 つの機種はそれぞれが耳型の全範囲を収容しなければならない。**「機種-L は大きい耳向け」ではない。

→ [Part 0.4b](jp/00-scope-and-usage.md#sec-0-4b)

---

## A. 寸法エンベロープ——本体はどの範囲に収まるべきか

単位 mm。【実測】は当チームが実際に測定した **56 名／112 耳**（左右耳は独立標本ではないため統計は人単位 n=56）。【文献】は既発表研究。

| 寸法 | P5 | 中央値 | P95 | 出典 |
|---|---|---|---|---|
| 耳介長 | 59.8 | 66.5 | 73.0 | 【実測】→ [Part 2.2](jp/02-anthropometric-basis.md#sec-2-2) |
| 耳介幅 | 33.4 | 38.2 | 43.5 | 【実測】→ [Part 2.2](jp/02-anthropometric-basis.md#sec-2-2) |
| 耳介厚さ | 19.0 | 21.5 | 25.2 | 【実測】→ [Part 2.2](jp/02-anthropometric-basis.md#sec-2-2) |

| 寸法 | 男性 | 女性 | 出典 |
|---|---|---|---|
| 耳甲介幅（CW） | 17.0–17.3 | 15.7–16.0 | 【文献】→ [Part 2.3](jp/02-anthropometric-basis.md#sec-2-3) |
| 耳珠全長（TL） | 18.1–18.4 | 16.6–17.0 | 【文献】→ [Part 2.3](jp/02-anthropometric-basis.md#sec-2-3) |
| 外耳道開口幅（WECO） | 7.7–8.0 | 7.1–7.4 | 【文献】→ [Part 2.3](jp/02-anthropometric-basis.md#sec-2-3) |
| 耳甲介深さ（CD） | **平均 9.15**（男女未分） | | 【実測】→ [Part 2.4](jp/02-anthropometric-basis.md#sec-2-4) |

**これらの数値を使う際の 4 つの規則：**

1. **耳甲介深さは平均値 9.15mm のみ使用可。** パーセンタイルと個別値は測定ノイズが支配的（単回測定の約 46% がノイズ）であり、しきい値として使えない。→ [Part 2.4.1](jp/02-anthropometric-basis.md#sec-2-4-1)
2. **「耳介厚さ 21.5mm」は横向き寝の突出高さではない。** それは耳介自体の巻き込みの深さであり、まったく別の量である。→ [Part 2.2.1](jp/02-anthropometric-basis.md#sec-2-2-1)
3. **文献値は 18–28 歳のサンプル。睡眠補助製品の利用者は高齢寄りで、耳は生涯を通じて大きくなる。** 上限側に余裕を持たせること。→ [Part 2.0.2](jp/02-anthropometric-basis.md#sec-2-0-2)
4. **⛔ 他の出典の耳寸法と混用してはならない。** 各数値はそれぞれ固有の基準面定義に紐づいている。→ 下記参照

> ### ⚠️ 「耳甲介深さ」は出典によって 2 倍近く違う。測っている線が同じでないためである
>
> | 表記 | 数値 | 何を測っているか |
> |---|---|---|
> | **本ガイドライン** | **9–10mm** | **耳甲介の縁の平面**から窪みの底まで |
> | 一部のネット情報 | 14–17mm | **耳介外縁／耳輪**から底までと推定される。対耳輪の壁の高さが加算されている |
> | 耳甲介**直径** | 15–20mm | **深さではない。** 本ガイドラインの CW（男 17.0–17.3、女 15.7–16.0）と重なる |
>
> 文献における「耳甲介深さ」の報告値自体が 9–16.8mm に散らばっており、その差は測定方法の違いに由来する。
> **「本体を耳甲介の窪みに収める」ための寸法決めには、縁基準（9–10mm）を用いること。**
> → [Part 2.4.3](jp/02-anthropometric-basis.md#sec-2-4-3)

---

## B. 配置禁止領域——部品を置いてはいけない場所

**⛔ 荷重を受ける保持構造を耳珠（tragus）に置いてはならない。**
耳甲介の 6 測定点のうち耳珠の圧迫不快閾値が最も低い。加えて顎の開閉に伴って変形する。市販イヤホンは耳珠で保持することが多いが、一晩中の装着でこの慣例を踏襲してはならない。→ [Part 3.1](jp/03-sensitive-zones.md#sec-3-1)、[Part 1A.2](jp/01a-posture-analysis.md#sec-1a-2)

**⛔ カナル部が外耳道の後下壁に持続的に接触してはならない。**
同部位は Arnold 咳嗽反射の誘発領域であり、後下象限への接触で **4.2%（21/500 名）** に咳嗽が誘発される。睡眠補助製品にとって夜間の咳嗽は製品目的そのものを破壊する。→ [Part 3.2](jp/03-sensitive-zones.md#sec-3-2)

**保持は耳輪（helix）／対耳輪（antihelix）に移すこと。** 相対的に安全な領域は耳輪、舟状窩、耳垂、対耳輪——迷走神経支配が最も少ない。→ [Part 3.1](jp/03-sensitive-zones.md#sec-3-1)

**自律神経への効果を主張してはならない。** 耳甲介は確かに経皮的迷走神経刺激の標的領域だが、それらの研究は電気刺激であり、受動的な圧迫へ外挿することはできない。→ [Part 3.0](jp/03-sensitive-zones.md#sec-3-0)

---

## C. 設計可能領域

**設計可能領域 = 解剖学的境界 ∩ 姿勢による境界**。両者は成因が異なり、単一の数値に統合してはならない。→ [Part 4.0](jp/04-max-design-envelope.md#sec-4-0)

**⏳ 横向き寝の突出高さ上限：公開データがなく、実測が必須。**
メーカーは一切公表しておらず、"flush（フラッシュ）" はマーケティング用語で測定上の定義を持たない。取得方法：競合 2–3 機種を購入しノギスで装着時の突出高さを測定 ＋ 被験者を横向きに寝かせて枕の沈み込み間隙を測定し、厳しい方を採る。→ [Part 4.2](jp/04-max-design-envelope.md#sec-4-2)

**判定基準は形態ごとに異なり**、同一の物差しを共用できない：
- カナル型 → 耳介外縁に対する突出高さ
- イヤーフック型 → 頭部側面最外縁の厚さ ＋ 乳様突起部への圧力 ＋ 耳介が折れ曲がらないこと ＋ フックが剛体レバーになっていないこと
→ [Part 4.2.1](jp/04-max-design-envelope.md#sec-4-2-1)

**本当の物理量は「枕から耳へ伝わる接触圧」**であり、突出高さはその代理指標にすぎない。低くても硬く尖った突起は、高くても幅広く丸く弾性のある突起より痛いことがある。→ [Part 4.2](jp/04-max-design-envelope.md#sec-4-2)

---

## D. 形態選定——姿勢を横断する万能解は存在しない

> ⛔ **第一段階は夜間の長時間睡眠（一晩の臥位睡眠）のみを対象とする。座位睡眠（昼寝・交通機関）は範囲外**（発注者が 2026-08-25 に裁定）。
> 下表は臥位の 2 姿勢のみを示す。座位睡眠の完全な分析（B1 オフィス／B2 通勤／B3 長距離の 3 サブシーンを含む）は [Part 1A.4](jp/01a-posture-analysis.md#sec-1a-4) に範囲外として残してあり、**将来シーンを拡張する際はそのまま使える**。

| 形態 | 仰向け | 横向き | 第一段階の判定 |
|---|---|---|---|
| カナル型 | 中 | 中 | 候補 |
| **イヤーフック型** | 良 | **高リスク** | ⛔ **非推奨**——耳後部の本体が体重で押さえられ、その下は乳様突起部（mastoid）の骨面である。利点は座位睡眠に集中しており、座位を外すと欠点だけが残る |
| 扁平オンイヤー型 | 中 | 中〜高 | 候補 |
| **ヘッドバンド／アイマスク型** | 良 | **良 ★** | **最有力候補**——唯一の弱点「公共の場で社会的に無理」は座位専用の制約であり、シーンの除外とともに消えた |
| 骨伝導 | 良 | 中 | 候補（「アナウンスが聞こえる」という利点は座位専用であり算入しない） |

**★ シーンを狭めると形態の順位が反転する。これは微調整ではない。** イヤーフック型とアイマスク型の評価は座位を外す前後で正反対になる——**形態選定の結論は必ずシーンに紐づけること。シーンから切り離して引用すると逆の答えになる。**
→ [Part 1A.4.1](jp/01a-posture-analysis.md#sec-1a-4-1)、[Part 4.2.3](jp/04-max-design-envelope.md#sec-4-2-3)

**臥位 2 姿勢の制約は和集合を取る**——各姿勢が拘束するパラメータはほとんど重ならない：**突出高さと長時間の静的圧迫←横向き｜外耳道フィットの許容幅（開口時）←仰向け｜保持力（寝返りで外れない）←横向きと寝返り動作**。一晩の睡眠には必ずこの 2 姿勢が両方含まれる。**片方だけを狙って設計しても、もう片方を覆ったことにはならない。** → [Part 1A.6](jp/01a-posture-analysis.md#sec-1a-6)

（旧表の「保持力←座位」「外観と環境音の把握←座位」の 2 項は、座位の除外に伴い非該当となった。）

---

## E. 音響幾何

**まず密閉するか否かを確定する。それが前気室の境界を決める：**
- 密閉型カナル：V_front ＝ 機器内部空間 ＋ イヤーチップから鼓膜までの残留外耳道容積。**耳甲介は算入しない。**
- 非密閉型：閉じた前気室は存在せず、耳甲介は結合気室＋漏れ経路として扱う。
→ [Part 5.1.1](jp/05-acoustic-constraints.md#sec-5-1-1)

**⛔ 漏れ経路は実際の幾何形状で示すこと。等価開口面積だけでは不可。** 狭隙は幅×高さ×長さ、円孔は半径×深さ。等価面積が同じでも幾何が違えば → 質量支配 vs 粘性抵抗支配 → モデル選択を誤る。**しかも誤りは静かに起こり、エラーにならない。** → [Part 5.3](jp/05-acoustic-constraints.md#sec-5-3)

**漏れ経路の幾何には測定時の顎の状態を明記すること。** 密閉型カナルは開口状態を基準とするか、両方を提示する。静止状態の測定は漏れを過小評価し遮音性能を過大評価する。→ [Part 5.3](jp/05-acoustic-constraints.md#sec-5-3)

**シミュレーションが信頼できる周波数上限**（これを超えると実測に頼るほかない）：
- カナル型（気室の代表寸法 8–12mm）→ 約 3.5–5.4 kHz
- オーバーイヤー型（20–30mm）→ 約 1.4–2.1 kHz
→ [Part 5.5](jp/05-acoustic-constraints.md#sec-5-5)

---

## F. 構造と 3D プリント

| 項目 | FDM | SLA |
|---|---|---|
| 肉厚下限 | ≥1.0–1.2mm（荷重部材 ≥2.0mm） | 0.4–0.6mm |
| サポート不要のオーバーハング角 | ≤45° | ≤30° かつ張り出し ≤2mm |
| 最小フィーチャ寸法 | 0.5mm | 0.2mm |
| 弾性材の造形可能硬度範囲 | Shore A 60–95 | Shore A 43–50 |

→ [Part 6](jp/06-structure-materials.md).A

**⛔ 耳シェル内腔のサポートは必ず除去できること。** 完全に閉じた行き止まり穴を避けるか、可溶性サポート材を用いる。

**⛔ 孔径と最小フィーチャ寸法は別物である。** 最小フィーチャ 0.5mm は薄壁／細柱用。**孔の下限は FDM 水平 ≥2.0mm、垂直（Z 軸方向）≥1.0mm** であり、断面積で約 16 倍の差がある。10mm 以下の孔は実測で 2–4% 小さくなるため、音響の調律孔は CAD 側で事前補償すること。→ [Part 6.A](jp/06-structure-materials.md#sec-6-a)

**⛔ 機体の造形配置方向は自由変数ではない。** 音響孔の軸は造形 Z 軸に平行とすること。水平孔の内部サポートが取り出せない場合、**それは音響経路の失効であって精度の劣化ではない**。他の DFM 上の理由で配置を変える際は孔軸を再確認すること。→ [Part 5.2.3](jp/05-acoustic-constraints.md#sec-5-2-3)

**同一の音響機能の開口は単孔を既定とする。** 多孔に分けると各孔の粘性条件が悪化し、造形可能な孔径をより早く割り込み、しかも**総面積が等しくても音響的に等価ではない**（f₀ がずれる）。→ [Part 5.2.3](jp/05-acoustic-constraints.md#sec-5-2-3)

**★ プリントでは睡眠用イヤーチップに必要な柔らかさに到達できない。** 市販の睡眠用イヤーチップは Shore A 10–20 が一般的だが、**プリントで到達できる最も柔らかい値は約 Shore A 43**（SLA 弾性樹脂。FDM の TPU は下限 60A でさらに硬い）。
→ **推奨する主案：硬質シェルをプリントし、シリコーン／低反発フォームのチップは外部調達**（金型は不要のままであり「プリントで作れる」前提を満たす）。
→ 純プリント案の代償：接触面の硬度を下げられず、長時間の横向き寝で圧迫感が明確に増す。
→ [Part 6](jp/06-structure-materials.md).C

**Shore A と Shore 00 を混用してはならない。** 低反発フォーム／軟質ゲルは Shore 00、一般的なシリコーンは Shore A を用い、数値を相互比較してはならない。

---

## G. CMF

**⛔ スリープモードでは充電ケース／ドックのインジケータを既定で全消灯とする。**
真のリスクはイヤホン本体ではなく充電ケースである——イヤホンは耳に装着され視野に入らないが、充電ケースはベッドサイドに置かれ目を直視する。→ [Part 8.1](jp/08-cmf.md#sec-8-1)

**機能上どうしても点灯が必要な場合、最も感受性の高い個人の 6 lux を基準とし、集団平均の 24.6 lux を用いてはならない。**
夜間光によるメラトニン抑制の個人差は一桁に及ぶ（6–350 lux）。10 lux でメラトニン分泌開始が約 22 分遅延する。集団平均を用いると感受性の高い利用者の約半数に影響する。→ [Part 8.1](jp/08-cmf.md#sec-8-1)

**輝度は照度計を用い、実際の距離と角度で「目の位置に到達する値」を測定すること。** LED のスペックシート値を引用してはならない。

**スリープモードでは点滅／ブリージング効果を禁止する。**

**左右耳と表裏は触覚で識別できること**——暗所で装着するため視覚に頼れない。→ [Part 8.3](jp/08-cmf.md#sec-8-3)

---

## H. 実機検証が必須の項目——これらはシミュレーションできない

**接触圧に判定可能な形式ができた**（従来はしきい値がなかった）：**各接触パッチが個別に A_i ≥ F_i / PDT(当該部位) を満たすこと**——パッチ単位であり合計面積を用いない。荷重分布が不明なら最不利分布を取る。フィレット半径は同じことの幾何的手段である。**耳珠（tragus）は⛔配置禁止であり、「面積が十分なら可」ではない。** ⏳ 唯一の不足：PDT 絶対値の部位別表。→ [Part 6.D](jp/06-structure-materials.md#sec-6-d)

**⛔ 装着圧と快適性は現有ツールでシミュレーションできない。** 超弾性材料モデルと接触ソルバがなく、耳の軟組織の材料パラメータにも検証可能な出典がない。**最終的に実機装着試験が必須。** → [Part 7.0](jp/07-wearing-pressure-comfort.md#sec-7-0)

**⛔ 「耳を測る」ことでも快適性は予測できない。** 耳の左右対称性、性別、耳甲介長、耳甲介腔幅と主観的な快適性／フィット評点との相関は**いずれも有意でないか非常に弱い**。実際に有意なのは**使用状況と製品サイズ**である。→ [Part 7.0b](jp/07-wearing-pressure-comfort.md#sec-7-0b)
（統計上の限界：n=30。「有意に達しない」は弱い証拠であり、無関係の証明ではない。）

> **A 節の寸法データは「収まらない」案を排除するためのものであり、「最も快適な」案を選ぶためのものではない。**

**★ 製品にマイクがあるなら、密閉度の自己テスト機能を内蔵し、比較方式のプロトコルを採るべきである。**
2 社の独立した実装がいずれも、耳の幾何を測る代わりに**テスト音を再生し内蔵マイクで反射音を解析して漏れを検出する**方式を採っている：
- **Apple**（Ear Tip Fit Test／Acoustic Seal Test）：**合否判定**。現在装着中のチップが密閉しているかを判定する
- **Sony**（最適なイヤーピースの判定）：**比較方式**。各サイズを順に装着して気密性を測定し順位付けし、「どのサイズが最良か」に直接答える

**Sony 方式の比較プロトコルを推奨する**——利用者が本当に必要としており、かつ耳を測っても解決できない問いに、これが直接答えるからである。代償は各サイズを実際に装着し直す必要があること。測定は静かな環境で、被験者が動かない状態で行う。密閉型カナルにのみ適用。→ [Part 7.4.0](jp/07-wearing-pressure-comfort.md#sec-7-4-0)

> ⚠️ **これらのプロトコルはいずれも覚醒・静止・閉口状態での 1 回限りの測定である。一方、本製品の使用状態は睡眠中・姿勢変化・顎の弛緩による開口である。密閉テストに合格しても一晩中密閉が保たれる保証はない。** この乖離を定量化するデータはなく、存在の明示にとどめる。

**検証の順序：密閉自己テスト → 機械的フィットの簡易スクリーニング → 計測機器による測定。結果から代理指標へ、その逆ではない。**

検証計画は最低限以下を含むこと：

| 試験 | 理由 |
|---|---|
| **右側臥位を重点化** | 高齢利用者は右向き寝を明確に好み、右耳の累積圧迫が高い → [Part 1A.3](jp/01a-posture-analysis.md#sec-1a-3) |
| **高齢被験者を含める** | 現有の寸法データは年齢が低いか不明であり、耳は生涯大きくなる。**この欠落は試験でしか埋められない** → [Part 2.0.2](jp/02-anthropometric-basis.md#sec-2-0-2) |
| **開口状態** | 仰向け寝では顎の弛緩により外耳道が変形する（被験者 30 名全員で発生）。閉口のみの測定は必要なフィット許容幅を系統的に過小評価する → [Part 1A.2](jp/01a-posture-analysis.md#sec-1a-2) |
| **長時間の静的圧迫** | 65–80 歳の寝返りは 2.1 回/時にすぎず、30 分以上動かない時間帯が増える。荷重条件は「ピーク」ではなく「持続」である → [Part 1A.3](jp/01a-posture-analysis.md#sec-1a-3) |
| 横向き寝の突出高さ実測 | C 節参照 |
| 接触圧測定 | 薄膜圧力センサ。圧力しきい値の数値を補う → [Part 7.4](jp/07-wearing-pressure-comfort.md#sec-7-4) |

**機器を要さない 3 つの簡易スクリーニング**（本測定の前に、明らかに不適合な案をこれで落とす）→ [Part 7.4.1](jp/07-wearing-pressure-comfort.md#sec-7-4-1)：

| 試験 | 判定 |
|---|---|
| **頭振り** — 素早く首を振る・頷く | 微動だにしないこと。ずれる＝サイズが小さすぎるか**角度が合っていない** |
| **咀嚼／開口** — 口を開閉する、話す真似をする | ⛔ **耳珠に鋭い痛み＝サイズが大きすぎる。直ちに 1 段小さくする。慣れの問題ではない** |
| **15 分ルール** — 装着して 15 分歩く | ⛔ **持続する圧迫感はすべて誤ったサイズの兆候であり、慣れるべきものではない** |

**装着角度はサイズと同等に重要である**：保持構造は耳介の曲線に沿って回し込む必要があり、角度がずれればサイズが正しくても痛む。加えて耳の**角度系寸法は左右非対称**であるため、角度を伴う保持構造で左右共用を前提としてはならない。→ [Part 2.2.3](jp/02-anthropometric-basis.md#sec-2-2-3)、[Part 4.1](jp/04-max-design-envelope.md#sec-4-1)

---

## 本ガイドラインが現時点で数値を示せない項目

正直な一覧は → [Part 9](jp/09-checklist.md) 末尾。主なものは：横向き寝の突出高さ上限、長時間の静的圧迫の耐容値、硬度と接触圧の定量的対応、パッシブ遮音の dB 目標。**いずれも実機試験を要し、資料調査では解決できない。**

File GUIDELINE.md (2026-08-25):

# 指引本體——實際的設計規則

**這份文件只講「你該怎麼做」。** 證據來源、推導過程、限制討論都在各章，這裡只放結論與數字。

每條後面的 → Part X 是可點的連結，直接跳到 cn/ 對應章節查依據。**如果你只想知道指引講什麼，讀這一份就夠。**

標記：**⛔ 否決項**（違反則產品不可用）｜**⏳ 待實測**（本指引給方法，數值須自行量測補上）

> 🌐 日本語版：[GUIDELINE.ja.md](GUIDELINE.ja.md)

---

## 0. ⚠️ 先分清三種「尺寸」——字母不共用

| 概念 | 標示 | 回答什麼問題 | 誰決定 |
|---|---|---|---|
| **機體變體** | **機型 S／M／L** | 這個機種本體做多大 | **產品決策**（驅動器／電池／功能取捨） |
| **配件尺寸** | **耳塞／耳翼 XS～L** | 這位使用者該配哪個耳塞 | 依該使用者耳型 |
| **耳型分段** | **耳型分段 I／II／III** | 這位使用者的耳朵屬哪一段 | **人因資料**（A 段） |

> ⛔ **耳型分段一律用羅馬數字 I／II／III，禁用 S／M／L。** 字母共用是先前多次誤讀的根因。
>
> **機型變體與耳型分段正交。** 業界標準是一個機體配多組耳塞——機體尺寸走產品線，耳朵差異靠配件吸收。
> → **三個機型各自都必須容納整個耳型範圍**，不是「機型-L 給大耳朵」。

→ [Part 0.4b](cn/00-scope-and-usage.md#sec-0-4b)

---

## A. 尺寸包絡——機體要塞進什麼範圍

單位 mm。【實測】為本團隊實際量測 **56 人／112 耳**（左右耳非獨立樣本，統計以人為單位 n=56）；【文獻】為已發表研究。

| 尺寸 | P5 | 中位數 | P95 | 來源 |
|---|---|---|---|---|
| 耳廓長度 | 59.8 | 66.5 | 73.0 | 【實測】→ [Part 2.2](cn/02-anthropometric-basis.md#sec-2-2) |
| 耳廓寬度 | 33.4 | 38.2 | 43.5 | 【實測】→ [Part 2.2](cn/02-anthropometric-basis.md#sec-2-2) |
| 耳廓厚度 | 19.0 | 21.5 | 25.2 | 【實測】→ [Part 2.2](cn/02-anthropometric-basis.md#sec-2-2) |

| 尺寸 | 男 | 女 | 來源 |
|---|---|---|---|
| 耳甲寬（CW） | 17.0–17.3 | 15.7–16.0 | 【文獻】→ [Part 2.3](cn/02-anthropometric-basis.md#sec-2-3) |
| 耳屏總長（TL） | 18.1–18.4 | 16.6–17.0 | 【文獻】→ [Part 2.3](cn/02-anthropometric-basis.md#sec-2-3) |
| 耳道開口寬（WECO） | 7.7–8.0 | 7.1–7.4 | 【文獻】→ [Part 2.3](cn/02-anthropometric-basis.md#sec-2-3) |
| 耳甲深（CD） | **平均 9.15**（男女未分） | | 【實測】→ [Part 2.4](cn/02-anthropometric-basis.md#sec-2-4) |

**使用這些數字的四條規則：**

1. **耳甲深只能用平均值 9.15mm。** 百分位與個別值受量測雜訊主導（單次量測約 46% 是雜訊），不可作為門檻。→ [Part 2.4.1](cn/02-anthropometric-basis.md#sec-2-4-1)
2. **「耳廓厚度 21.5mm」不是側睡凸出高度。** 那是耳廓自己捲曲的深度，兩者完全不同。→ [Part 2.2.1](cn/02-anthropometric-basis.md#sec-2-2-1)
3. **文獻值取自 18–28 歲樣本，助眠客群偏年長，耳朵終生變大。** 上緣要留餘裕。→ [Part 2.0.2](cn/02-anthropometric-basis.md#sec-2-0-2)
4. **⛔ 不可與其他來源的耳部尺寸混用。** 每個數字綁著自己的基準面定義。→ 見下方

> ### ⚠️ 「耳甲深」在不同來源差到兩倍，因為量的不是同一條線
>
> | 說法 | 數值 | 量什麼 |
> |---|---|---|
> | **本指引** | **9–10mm** | 從**耳甲碗緣平面**到碗底 |
> | 部分網路資料 | 14–17mm | 疑似從**耳廓外緣／耳輪**到碗底，多算進對耳輪那道牆 |
> | 耳甲**直徑** | 15–20mm | **不是深度。** 本指引 CW 男 17.0–17.3、女 15.7–16.0，與此重疊 |
>
> 文獻中「耳甲深」跨度本身即 9–16.8mm，變異來自量測方法不同。
> **為「機體塞進耳甲碗」定尺寸時用碗緣基準（9–10mm）。**
> → [Part 2.4.3](cn/02-anthropometric-basis.md#sec-2-4-3)

---

## B. 禁置區——部件不能放哪裡

**⛔ 不得將承重固位結構放在耳屏（tragus）。**
耳甲六個量測點中耳屏壓力不適閾值最低；且它會隨下顎張閉而變形。市售耳機常用耳屏固位，整夜佩戴不可沿用此慣例。→ [Part 3.1](cn/03-sensitive-zones.md#sec-3-1)、[Part 1A.2](cn/01a-posture-analysis.md#sec-1a-2)

**⛔ 入耳件不得持續接觸外耳道後下壁。**
該處為 Arnold 咳嗽反射誘發區，觸碰後下象限有 **4.2%（21/500 人）** 引發咳嗽。對助眠產品而言，夜間咳嗽直接摧毀產品目的。→ [Part 3.2](cn/03-sensitive-zones.md#sec-3-2)

**固位改用耳輪（helix）／對耳輪（antihelix）。** 相對安全區為耳輪、舟狀窩、耳垂、對耳輪——迷走神經支配最少。→ [Part 3.1](cn/03-sensitive-zones.md#sec-3-1)

**不得宣稱任何自律神經效果。** 耳甲確為經皮迷走神經刺激靶區，但那些研究用電刺激，不可外推至被動壓迫。→ [Part 3.0](cn/03-sensitive-zones.md#sec-3-0)

---

## C. 可設計區域

**可設計區域 = 解剖邊界 ∩ 姿勢邊界**，兩者成因不同，不可合併成單一數字。→ [Part 4.0](cn/04-max-design-envelope.md#sec-4-0)

**⏳ 側睡凸出高度上限：無公開數據，必須實測。**
廠商一律不公布，"flush（齊平）" 是行銷用詞無量測定義。取得方式：買 2–3 款競品用游標卡尺量配戴時凸出高度 ＋ 受試者側躺量枕頭壓陷間隙，取嚴。→ [Part 4.2](cn/04-max-design-envelope.md#sec-4-2)

**判準依形態族而異**，不可共用一把尺：
- 入耳式 → 相對耳廓外緣的凸出高度
- 掛耳式 → 頭側最外緣厚度 ＋ 乳突區壓力 ＋ 耳廓未被折彎 ＋ 耳掛非剛性槓桿
→ [Part 4.2.1](cn/04-max-design-envelope.md#sec-4-2-1)

**真正的物理量是「枕頭傳進耳朵的接觸壓力」**，凸出高度只是代理指標。矮而硬尖的凸點可能比高而寬圓有彈性者更痛。→ [Part 4.2](cn/04-max-design-envelope.md#sec-4-2)

---

## D. 形態選型——沒有跨姿勢的通用最佳解

> ⛔ **第一階段只服務夜間長時間睡眠（整夜臥睡）。坐睡（午睡、交通工具）已移出範圍**（需求方 2026-08-25 裁定）。
> 下表只列臥睡兩姿勢。坐睡的完整分析（含 B1 辦公室／B2 通勤／B3 長途三個子情境）保留在 [Part 1A.4](cn/01a-posture-analysis.md#sec-1a-4)，標為範圍外，**未來若擴充情境可直接取用**。

| 形態 | 正睡 | 側睡 | 第一階段判定 |
|---|---|---|---|
| 入耳式 | 中 | 中 | 候選 |
| **掛耳式** | 佳 | **高風險** | ⛔ **不建議**——耳後主體被躺壓，其下即乳突區（mastoid）骨面。它原本的優勢全部集中在坐睡，坐睡移出後只剩缺點 |
| 扁平耳罩 | 中 | 中高 | 候選 |
| **頭帶／眼罩式** | 佳 | **佳 ★** | **最強候選**——唯一弱點「公開場合社交不可行」屬坐睡專屬約束，已隨情境移出而消失 |
| 骨傳導 | 佳 | 中 | 候選（「聽得到廣播」的優勢屬坐睡，已不計入） |

**★ 情境縮小會翻轉形態排序，這不是微調。** 掛耳式與眼罩式的評價在坐睡移出前後完全相反——**任何形態選型結論都必須綁定情境，脫離情境引用會得到相反的答案。**
→ [Part 1A.4.1](cn/01a-posture-analysis.md#sec-1a-4-1)、[Part 4.2.3](cn/04-max-design-envelope.md#sec-4-2-3)

**臥睡兩姿勢的約束取聯集**——各姿勢綁定的參數幾乎不重疊：**凸出高度與長時間靜態受壓←側睡｜耳道貼合寬容度（下顎張開）←正睡｜固位（翻身不脫落）←側睡與翻身動作**。整夜睡眠必然同時包含這兩種姿勢，**不能只針對其中一種設計就當作涵蓋另一種。** → [Part 1A.6](cn/01a-posture-analysis.md#sec-1a-6)

（原表中「固位←坐睡｜外觀與環境感知←坐睡」兩項已隨坐睡移出而不適用。）

---

## E. 聲學幾何

**先確定密封與否，它決定前腔邊界在哪：**
- 密封式入耳：V_front ＝ 裝置內部空間 ＋ 耳塞到鼓膜的殘餘耳道容積。**耳甲不計入。**
- 非密封式：無封閉前腔，耳甲為耦合腔＋漏氣路徑。
→ [Part 5.1.1](cn/05-acoustic-constraints.md#sec-5-1-1)

**⛔ 漏氣路徑必須給實際幾何，不可只給等效開孔面積。** 窄縫給寬×高×長，圓孔給半徑×深。等效面積相同但幾何不同 → 質量主導 vs 黏性阻力主導 → 模型選錯，**且會錯得很安靜、不報錯**。→ [Part 5.3](cn/05-acoustic-constraints.md#sec-5-3)

**漏氣幾何須註明量測時的下顎狀態**，密封式入耳應以口張開為準或兩組都給。靜止量測會低估漏氣、高估隔音。→ [Part 5.3](cn/05-acoustic-constraints.md#sec-5-3)

**模擬可信頻率上限**（超過只能靠實測）：
- 入耳式（腔體特徵尺寸 8–12mm）→ 約 3.5–5.4 kHz
- 耳罩式（20–30mm）→ 約 1.4–2.1 kHz
→ [Part 5.5](cn/05-acoustic-constraints.md#sec-5-5)

---

## F. 結構與 3D 列印

| 項目 | FDM | SLA |
|---|---|---|
| 壁厚下限 | ≥1.0–1.2mm（承力件 ≥2.0mm） | 0.4–0.6mm |
| 免支撐懸空角 | ≤45° | ≤30° 且懸空 ≤2mm |
| 最小特徵尺寸 | 0.5mm | 0.2mm |
| 彈性材可印硬度範圍 | Shore A 60–95 | Shore A 43–50 |

→ [Part 6](cn/06-structure-materials.md).A

**⛔ 耳殼內腔的支撐必須取得出來。** 避免全封閉盲孔，或改用可溶性支撐材。

**⛔ 孔徑與最小特徵尺寸不是同一件事。** 最小特徵 0.5mm 適用薄壁／細柱；**孔的下限是 FDM 水平 ≥2.0mm、垂直（沿 Z 軸）≥1.0mm**，截面積差約 16 倍。10mm 以下孔實印偏小 2–4%，聲學調諧孔須在 CAD 端預先補償。→ [Part 6.A](cn/06-structure-materials.md#sec-6-a)

**⛔ 整機列印擺放方向不是自由變數。** 聲學孔軸應平行列印 Z 軸；水平孔的內部支撐若取不出來，**那是聲學路徑失效，不是精度變差**。因其他 DFM 理由改擺放時，須回頭確認孔軸。→ [Part 5.2.3](cn/05-acoustic-constraints.md#sec-5-2-3)

**同一聲學功能的開孔預設用單孔。** 拆成多孔會同時讓每孔黏性條件變差、更快跌破可列印孔徑，而且**總面積相等不構成聲學等效**（f₀ 會跑掉）。→ [Part 5.2.3](cn/05-acoustic-constraints.md#sec-5-2-3)

**★ 列印做不到睡眠耳塞需要的軟度。** 市售睡眠耳塞常見 Shore A 10–20；**列印能達到的最軟約 Shore A 43**（SLA 彈性樹脂；FDM 的 TPU 下限為 60A，更硬）。
→ **建議主方案：列印硬殼 ＋ 外購矽膠／記憶棉軟塞**（仍不需開模，符合「印得出來」前提）。
→ 備案純列印的代價：接觸面硬度下不去，長時間側睡壓迫感明顯增加。
→ [Part 6](cn/06-structure-materials.md).C

**Shore A 與 Shore 00 不可混用。** 記憶棉／軟凝膠用 Shore 00，一般矽膠用 Shore A，數值不可互相比較。

---

## G. CMF

**⛔ 睡眠模式下，充電盒／底座指示燈預設全滅。**
真正的風險點是充電盒不是耳機本體——耳機戴在耳上不在視野內，充電盒放床頭櫃正對眼睛。→ [Part 8.1](cn/08-cmf.md#sec-8-1)

**若功能上必須亮，以最敏感個體 6 lux 為基準，不可用群體平均 24.6 lux。**
夜間光照抑制褪黑激素的個體差異達一個數量級（6–350 lux）；10 lux 即造成褪黑激素起始延遲約 22 分鐘。用群體平均會影響約半數敏感使用者。→ [Part 8.1](cn/08-cmf.md#sec-8-1)

**亮度須以照度計在實際距離角度量「到達眼睛位置」的值**，不可引用 LED 規格書數字。

**睡眠模式禁用閃爍／呼吸效果。**

**左右耳與正反面須可觸覺辨識**——暗室配戴，無法依賴視覺。→ [Part 8.3](cn/08-cmf.md#sec-8-3)

---

## H. 必須實體驗證的項目——這些模擬不出來

**接觸壓力有可判定形式了**（先前無門檻）：**每一接觸斑塊各自滿足 A_i ≥ F_i / PDT(該部位)**——逐斑塊，不可用總面積；承載分佈未知時取最不利分佈。圓角半徑是同一件事的幾何手段。**耳屏（tragus）是⛔禁置，不是「面積夠大即可」。** ⏳ 唯一待補：PDT 絕對值分區表。→ [Part 6.D](cn/06-structure-materials.md#sec-6-d)

**⛔ 佩戴壓力與舒適無法以現有工具模擬。** 缺超彈性材料模型與接觸求解器，且耳部軟組織材料參數無可核驗來源。**最終必須實體試戴。** → [Part 7.0](cn/07-wearing-pressure-comfort.md#sec-7-0)

**⛔ 也不能用「量耳朵」預測舒適度。** 耳部對稱性、性別、耳甲長度、耳甲腔寬度與主觀舒適／貼合評分的相關性**皆不顯著或很弱**；真正顯著的是**使用情境與產品尺寸**。→ [Part 7.0b](cn/07-wearing-pressure-comfort.md#sec-7-0b)
（統計限制：n=30，「未達顯著」是弱證據不等於無關聯。）

> **A 段的尺寸資料是用來排除「裝不下」的方案，不是用來挑「最舒服」的方案。**

**★ 若產品具備麥克風，應內建密封自測功能，並採比較式協定。**
兩家獨立實作皆以**播放測試音、內建麥克風分析回授偵測洩漏**取代量測耳朵幾何：
- **Apple**（Ear Tip Fit Test／Acoustic Seal Test）：**通過／不通過**，判定當前耳塞是否密封
- **Sony**（判斷最佳耳塞）：**比較式**，逐一換上各尺寸量測氣密性後排序，直接回答「哪個尺寸最好」

**建議採 Sony 式的比較協定**——它回答的正是使用者真正需要、而量耳朵解決不了的問題。代價是須實際更換每個尺寸。量測須於安靜環境、受試者不動。僅適用密封式入耳。→ [Part 7.4.0](cn/07-wearing-pressure-comfort.md#sec-7-4-0)

> ⚠️ **這些協定都是清醒、靜止、口閉合下的一次性量測；本產品的使用狀態是睡眠中、姿勢改變、下顎張開。通過密封測試不保證整夜維持密封。** 落差無資料可量化，僅標示存在。

**驗證順序：密封自測 → 機械貼合快篩 → 儀器量測。由結果測到代理，不是反過來。**

驗證計畫至少涵蓋：

| 測試 | 為什麼 |
|---|---|
| **加重右側臥** | 老年使用者明顯偏好右側臥，右耳累積壓迫較高 → [Part 1A.3](cn/01a-posture-analysis.md#sec-1a-3) |
| **納入年長受試者** | 現有尺寸資料年齡偏低或未知，耳朵終生變大。**此缺口只能靠測試補** → [Part 2.0.2](cn/02-anthropometric-basis.md#sec-2-0-2) |
| **口張開狀態** | 正睡下顎鬆弛使耳道變形（30 名受試者全數出現），只測口閉合會低估所需貼合寬容度 → [Part 1A.2](cn/01a-posture-analysis.md#sec-1a-2) |
| **長時間靜態受壓** | 65–80 歲翻身僅 2.1 次/小時，且超過 30 分鐘不動的時段增加。受力條件是「持續」不是「尖峰」 → [Part 1A.3](cn/01a-posture-analysis.md#sec-1a-3) |
| 側睡凸出高度實測 | 見 C 段 |
| 接觸壓力量測 | 薄膜壓力感測器，補上壓力門檻的數值 → [Part 7.4](cn/07-wearing-pressure-comfort.md#sec-7-4) |

**三個不需儀器的快篩測試**（正式量測前先用這三個篩掉明顯不合的方案）→ [Part 7.4.1](cn/07-wearing-pressure-comfort.md#sec-7-4-1)：

| 測試 | 判定 |
|---|---|
| **甩頭** — 快速搖頭點頭 | 應紋絲不動。有位移＝尺寸偏小或**角度不對** |
| **咀嚼／張口** — 張合嘴巴、模擬說話 | ⛔ **耳屏出現尖銳痛感＝尺寸過大，立即降一號。不是適應期問題** |
| **15 分鐘** — 戴著走動 | ⛔ **任何持續性壓迫感都是錯誤尺寸的訊號，不是需要適應** |

**佩戴角度與尺寸同等重要**：固位結構需順耳廓曲線入位，角度歪了尺寸再對也會痛。且耳部**角度類尺寸左右不對稱**，帶角度的固位結構不可假設左右通用。→ [Part 2.2.3](cn/02-anthropometric-basis.md#sec-2-2-3)、[Part 4.1](cn/04-max-design-envelope.md#sec-4-1)

---

## 這份指引目前給不出數字的項目

誠實清單，見 → [Part 9](cn/09-checklist.md) 末段。主要是：側睡凸出高度上限、長時間靜態受壓可承受值、硬度與接觸壓力的量化對應、被動隔音 dB 目標。**這些都需要實體測試，不是查資料能解決的。**

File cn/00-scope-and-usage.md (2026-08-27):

# Part 0 — 適用範圍、使用方式與證據分級

狀態：初稿 ｜ 最後更新 2026-08-21

> 🌐 日本語版：[jp/00-scope-and-usage.md](../jp/00-scope-and-usage.md)

---

## 0.1 這份指引是什麼

一份**檢查用規範**。設計者拿自己的睡眠耳機 3D 模型，對照本文件逐項檢查，就能判斷模型可不可行、哪裡不合格、該改哪裡。

**它不是**：設計教學、市場分析、產品規格書，也不是已驗證可行的產品方案。

## 0.2 適用範圍

| 項目 | 範圍 |
|---|---|
| 產品類型 | 睡眠用耳機，**不限入耳式（in-ear）或耳罩／頭戴等外耳形態** |
| 目標市場 | **亞洲成人** |
| 機體尺寸變體 | **機型 S／M／L** 三檔——同一顆耳朵可配戴的三種機體大小。**不是人耳分檔**，見 0.4b |
| 人因分列 | 男 / 女——**僅耳部尺寸類要分；壓力閾值不分**（實測性別無顯著影響）。見 [Part 3.3](03-sensitive-zones.md)、[Part 2.0.2](02-anthropometric-basis.md) |
| 製造方式 | **僅需 3D 印表機印得出來**，不含量產模具工藝 |
| 交付階段 | 第一階段＝本指引文件本身，不含 3D 模型 |

**明確排除**：電子件空間配置、量產可製造性（模具、射出成型、量產公差）、電性與韌體、音量安全邊界（見 Part 5.7）。

## 0.3 怎麼用

1. 先讀 Part 1，確認你的產品場景假設與本指引一致。不一致的話後面所有數字都要重新評估。
2. 依 Part 2 選定尺寸檔與性別基準。
3. 用 Part 3 確認沒有把承壓部件放在禁置區。
4. 用 Part 4 確認幾何在可設計區域內——**側睡邊界優先於解剖邊界**。
5. 用 Part 5、6 檢查聲學腔體與結構材料。
6. 用 Part 7、8 檢查舒適與 CMF。
7. 最後跑 Part 9 檢查清單。

## 0.4 證據分級（強制）

**每個數值後面必須標記來源等級。未標記的數字不得出現在交付版。**

| 標記 | 意義 | 可信度 |
|---|---|---|
| 【實測】 | **直接從量測資料萃取的統計量**（平均、百分位、PCA 主成分、擬合值）。不依賴任何物理模型為真 | 最高 |
| 【文獻】 | 可核驗的公開來源，附 DOI 或可達連結 | 高 |
| **【計算】** | **代入物理模型／公式求得。須揭露輸入來源與所有假設常數** | **取「模型適用性」與「輸入等級」兩者中較弱者** |
| 【慣例】 | 業界工程慣例，無單一權威來源 | 中 |
| 【推論】 | 本團隊的推論，非來源直述 | 中 |
| 【假設】／【待核】 | 尚無依據，待驗證後填入 | 無 |

來源類型另須註明：**業界標準**（給編號與版本）／**市場商品統計**（說明樣本來源）／**學術論文**（給 DOI 或可達連結）。

### 0.4a【計算】的兩條附加規則

**① 標明輸入來源**：寫成 **【計算｜輸入：實測】／【計算｜輸入：常數】／【計算｜輸入：混合】**。

**為什麼可信度不只看輸入**：公式本身可能被套用到不適用的架構上，那時輸入再好也救不了。實例——曾將亥姆霍茲共振關係套用到密封式入耳，但密封式沒有設計者可選的調諧頻率；公式正確、輸入正確、**架構套錯**。故「模型適用性」必須與「輸入等級」並列，取較弱者。

**② ⚠️ 判準必須標明它管的是模型還是物理量。**

工程判準有兩種，混用會導出完全錯誤的結論：

| 判準性質 | 回答什麼 | 例 |
|---|---|---|
| **模型適用性判準** | 我該用哪個模型算 | 剪切波數 s≳10（黏性可忽略）｜kL ≪ 1（集中參數成立） |
| **物理量門檻** | 這個東西行不行 | 壁厚 ≥1.0mm｜PDT 壓力上限 |

> ⛔ **不得以模型適用性判準反解物理需求。**「低於這個值模型不乾淨」不等於「低於這個值東西不成立」。
> **實例**：曾以 s≳10 反解出「520 Hz 需要 1.36mm 開口」並據此推論密封式不可行。錯在 s 是模型分界——s=3.7 的路徑不是不傳輸，是**有黏性損耗地傳輸**，損耗量須另行計算。該推論已撤回。
> **因此凡寫下這類分界，一律註明其性質。**

### 為什麼要這麼嚴

**指引錯了，後面所有設計都會照著錯下去。** 這跟分析報告不同——報告錯了是一份錯報告，指引錯了是一整條產品線照著錯的數字走。

因此本專案的立場是：**寧可交一份多處標【待核】的誠實文件，也不要一份數字填滿、看起來專業但其實是編的。** 留空會被追問，猜測值會被當成依據沿用。

實際執行時已據此攔下數處，例如：一條引用經確認是從搜尋摘要推斷而非讀過原文，已降級為【慣例】並刪除相關數字；一個承重硬度數字找不到獨立第二來源，已標為待交叉驗證。

## 0.4b ⚠️ 三種「尺寸」不可混用——字母不共用

**本專案有三個各自獨立的「尺寸」概念。先前已因共用 S/M/L 字母而造成多次誤讀，故明訂如下。**

| 概念 | 名稱與標示 | 回答什麼問題 | 誰決定 | 資料來源 |
|---|---|---|---|---|
| **機體變體** | **機型 S／M／L**（寫作 `機型-M`） | 這個機種本體做多大 | **產品決策**（驅動器／電池／功能取捨） | 不由人因資料決定 |
| **配件尺寸** | **耳塞／耳翼 XS～L**（寫作 `耳塞-S`） | 這位使用者該配哪個耳塞 | 依該使用者耳型 | 由耳型分段決定 |
| **耳型分段** | **耳型分段 I／II／III**（寫作 `分段-II`） | 這位使用者的耳朵屬哪一段 | **人因資料** | [Part 2](02-anthropometric-basis.md) |

> ⛔ **耳型分段一律使用羅馬數字 I／II／III，禁用 S／M／L 字母。** 字母共用是先前誤讀的根因。

### 三者的關係

```
耳型分段（使用者的耳朵有多大）
        ↓ 決定
配件尺寸（配哪個耳塞／耳翼）

機型變體（機體做多大）← 獨立決定，依功能取捨
        ↑ 受約束於
解剖包絡上限（Part 4）——所有機型皆不得超過
```

**機型變體與耳型分段正交。** 業界標準做法是**一個機體配多組耳塞**，機體尺寸走產品線，耳朵差異靠配件吸收。

→ **因此三個機型（S／M／L）各自都必須容納整個耳型範圍**，不是「機型-L 給大耳朵」。

## 0.4c 缺口處置規範——先問四件事，再決定要不要追那個數字

**缺一個數值時，直覺反應是「去量」或「登記為待實測」。兩者常常都不對。** 缺口表虛胖的代價是：本來現在就能關掉的項目被掛到「等實測」，而真正需要實測的項目被淹沒。

| 問題 | 若「是」 |
|---|---|
| ① 偏差是**單向**的嗎？ | 可能可用預補償或結構消除處理 |
| ② 成因是**我們自己設計出來的**嗎？ | 可以設計掉——**優先於補償** |
| ③ 量級**隨某個我們控制的尺寸縮放**嗎？ | 可壓到不相干，只需知道方向 |
| ④ 若屬第三類：**不相干判準是什麼？其輸入齊備了嗎？** | 見下方 |

**前三問任一為「是」→ 先改設計，不必追那個數字。三問皆否 → 才是真正必須實測的缺口。**

### ⑤ 這個缺口「等下去會有」還是「等不到」？——兩者處置完全不同

**缺口表最容易虛胖的地方不是項目太多，是把兩種本質不同的缺口混在同一欄。**

| 缺口類型 | 特徵 | 正確處置 |
|---|---|---|
| **取得型（等就會有）** | 數字存在，只是在付費牆後／要花錢量／要排時間 | 登記＋標出取得途徑與成本。**等待是有效策略** |
| **⛔ 良置型（等不到）** | **那個量測產不出可解釋的量**——定義未凍結、拓樸未定、或量到的東西不是所問的東西 | **等待無效。** 必須先解決「這個量到底問的是什麼」，否則量了也不能用 |

**實例對照**：
- **取得型**：PDT 絕對值分區表（Yuan et al. 2023 全文付費牆）——付錢或找訂閱就有
- **良置型**：耳甲容積 → 殼體可用總容積——**不是還沒量，是現有點雲量不出可解釋的殼體容積**（缺具名地標、缺耳道內部、缺基準面定義）

> ⛔ **把良置型登記成取得型，會讓它永遠掛在「待實測」而沒有人發現它等不到。** 這是缺口表最安靜的失效。

### ⑦ 缺口登記格式——每一筆都要有「轉換條件」與「動作種類」

只寫「缺什麼」不夠。**兩筆缺口看起來各自獨立，可能共用同一個根；也可能看起來都缺東西，實際上要靠完全不同的動作才關得掉。** 兩者都會讓優先序排錯。

| 欄位 | 內容 | 沒有它會怎樣 |
|---|---|---|
| **轉換條件** | 什麼東西到位，這筆就關閉（或從良置型轉成取得型） | 看不出跨人共用的根 |
| **動作種類** | **文件／工具／採集／裁決** 四選一或多選 | 以為一次動作能解掉兩筆，去找不存在的槓桿點 |

**四種動作種類**：

| 種類 | 意義 | 例 |
|---|---|---|
| **文件** | 取得／核驗一份文獻或規格 | PDT 絕對值（期刊存取）｜黏熱阻抗式核驗 |
| **工具／能力** | 需要一項我們沒有的能力 | 點雲上可靠偵測 P1–P5（**Zhu et al. 已給定義，缺的不是文獻是偵測能力——給十篇論文也不會動**） |
| **採集** | 需要重新設計資料採集 | 同一耳重複量測以獨立估雜訊（現有資料補不了） |
| **⛔ 裁決** | **這條路已被既有決定關閉。重開需要的不是資源，是推翻那個決定** | 聲學 FEM/BEM（task #4 裁定不裝）｜接觸力模擬（task #3 裁定不投入） |

> ⛔ **「裁決」類最容易被寫成還開著的路。** 實例：多孔端修正曾登記為「文獻**或** BEM/FEM 數值解」，看起來有兩條並行路徑——**但 BEM/FEM 早已被 task #4 關閉**，真實狀態是「若文獻不涵蓋該區間，它就沒有開放路徑了」。

### ⑧ 多路徑的缺口，每條路徑都要標狀態

**只寫還開著的那條，或只寫其中一個未滿足的輸入，是同一個失效的兩個方向：**

| 錯法 | 實例 |
|---|---|
| **漏掉一整個未滿足的輸入** | D-2-4 條文是 A_i ≥ F_i / PDT。曾登記為「待 PDT」，**等於預設 F_i 已有——實際上沒有**。正確登記：待 PDT（文件）＋待 F_i（採集；模擬路徑已由裁定關閉） |
| **把已關閉的寫成開放的** | 「文獻或 BEM/FEM」——後者已關閉 |

### ⑨ 裁定紀錄與缺口表必須雙向索引

**裁定記在「我們不做什麼」，缺口記在「我們缺什麼」。兩張表不交叉引用，兩邊的人都看不到對面。**

- 讀缺口表的人看不到那條路已被關閉 → 以為還能走
- 讀裁定的人看不到它關掉了哪些缺口的哪條路徑 → 不知道自己的決定造成什麼

**⇒ 每個裁定須標出它關閉了哪些缺口的哪條路徑；每個缺口的「裁決」類路徑須反指回該裁定。**
（與 5.2-10／6A-2 的雙向前置同構——**單向記錄會漏掉預設狀態**。）

### ⑩ 缺口也要套兩層拆法，且「第一層＝文件」不是通則

**第一層＝把問題定義清楚｜第二層＝取得數值。** 併成一列的後果是**把現在就能動的項目登記成要等別人的項目**。

| 實例 | 第一層（常被藏起來） | 第二層 |
|---|---|---|
| F_i | **量測狀態未定義**（下顎／熱／插入深度；取代表值或取分布）——**現在就能定，不定的話樣機到了會量錯狀態，比沒量更糟，因為它看起來是實測值** | 樣機量測 |
| 網前容積判準 | 判準形式未定 | 網的 R ＋ 固定結構實際幾何 |

> ⚠️ **「第一層只要文件」不成立。** 第一層是「把問題定義清楚」，而定義清楚需要什麼，取決於未定的是哪一種東西：
> **缺文獻**（黏熱網路形式）｜**缺工具**（點雲地標偵測——**全表最貴的一項**）｜**只缺一個決定**（F_i 的代表狀態）｜**被上游設計卡住**（拓樸，等固定方式選定）。

### ⑥ 這個數字是「能力量」還是「結果量」？

同一個名稱可能來自兩種完全不同的來源，可信度與可用範圍不同：

| 類型 | 回答什麼 | 可用範圍 |
|---|---|---|
| **能力量**（解剖量測） | **耳朵容得下多少** | 可作為分檔（S/M/L）與涵蓋率的依據 |
| **結果量**（市場商品統計） | **已經有人做到多少，且被市場接受** | **只能當上界參考，不可作為分檔依據** |

**理由**：結果量不告訴你它涵蓋哪個百分位。市售產品的體積可能只適合中位數以上的人，**而資料本身看不出這件事**。
**實例**：量市售睡眠耳機機體體積，可得「實際塞得進去且賣得出去」的經驗上界，**不需要任何解剖地標**——這是繞過地標缺口的有效路徑，但**產出的是上界不是分檔依據**。

### ⛔ 第四問是關鍵，少了它第二、三類會變成漏洞

「已最小化」「盡量貼近」**是形容詞，與本指引禁掉的「壁厚應足夠」同一類**。設計者宣稱做過就算過關，**而這比登記成缺口更糟——因為它看起來已經關閉了。**

> **寄生元件須給出「不相干判準」（通常為與主要元件的無因次比值）並證明設計落在安全側。僅宣稱「已最小化」不構成關閉條件。**

**「可寫」與「可驗」要分開**：判準寫成含未知量的不等式**仍然是可判定條文**，只是評估時點在後面。**兩者都否才留在缺口表。**

### 三類的實例（來自本專案）

| 缺口 | 偏差性質 | 處置 | 需要幅度數字嗎 |
|---|---|---|---|
| 固定製程使聲阻上升 | 單向、成因是可設計掉的物理路徑（膠的毛細滲入） | **結構消除**（機械夾持，膠不接觸聲學面） | **否** |
| 寄生容積 | 量級隨可控尺寸縮放 | **壓到不相干**——但須附判準，不可只說「最小化」 | **否**（只需方向＋判準） |
| 皮膚溫下硬度偏移 | **雙向**（舒適面有利、固位面不利），成因不在我們控制內 | **只能實測** | **是** |

> ⚠️ **門檻值若是選的，就要標成選定值。** 例如取「寄生容積 ≤ 主容積的 10%」——**那是工程選擇不是物理常數**，須附選擇理由。不標的話下一個讀者會當成有依據的數字。

## 0.5 用語規範

耳部部位與醫學名詞一律**中文在前、英文於括號內**，例如 耳屏（tragus）、耳甲腔（cavum conchae）、迷走神經耳支（auricular branch of vagus nerve, ABVN）。首次出現標全稱與縮寫，其後可只用中文。

純聲學與物理術語（如 Helmholtz 共振器、黏性邊界層）不適用此規範。

## 0.6 已知能力邊界（寫在正文，不藏附註）

本團隊有兩項無法以現有工具驗證的項目。設計者必須知道，才不會誤以為本指引的建議已經過模擬驗證：

| 項目 | 狀況 | 後果 |
|---|---|---|
| **佩戴壓力與舒適** | 缺超彈性（hyperelastic）材料模型與接觸（contact）求解器；且耳部軟組織材料參數無可核驗來源 | 無法模擬耳塞壓在耳道組織的實際壓力。**必須實體試戴驗證** |
| **聲學高頻表現** | 無波動 FEM/BEM 求解器，僅集中參數（lumped-element）模型 | 有頻率上限（見 Part 5.5）。上限以上只能靠實測 |

**本指引提供的是有工程依據的設計起點，不是已驗證可行的產品。**

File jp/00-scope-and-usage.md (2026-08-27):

# Part 0 — 適用範囲・使い方・証拠等級

ステータス：初稿 ｜ 最終更新 2026-08-21

> 🌐 中文版：[cn/00-scope-and-usage.md](../cn/00-scope-and-usage.md) ｜ 用語対照表：[TERMS.md](TERMS.md)

---

## 0.1 このガイドラインは何か

**点検用の規範**である。設計者が自分の睡眠用イヤホン 3D モデルを本文書と項目ごとに照合すれば、そのモデルが成立するか、どこが不適合か、何を直すべきかを判断できる。

**これは以下ではない**：設計の教本、市場分析、製品仕様書、そして検証済みの実現可能な製品案。

## 0.2 適用範囲

| 項目 | 範囲 |
|---|---|
| 製品種別 | 睡眠用イヤホン。**カナル型（in-ear）に限らず、オーバーイヤー／ヘッドバンド等の外耳形態も含む** |
| 対象市場 | **アジアの成人** |
| 本体サイズ・バリエーション | **機種 S／M／L** の 3 段階——同一の耳に装着できる 3 種類の本体サイズ。**耳のサイズ区分ではない**（0.4b 参照） |
| 人間工学データの男女別 | 男／女——**耳の寸法のみ分ける。圧迫閾値は分けない**（実測で性別の有意差なし）。[Part 3.3](03-sensitive-zones.md)、[Part 2.0.2](02-anthropometric-basis.md) 参照 |
| 製造方式 | **3D プリンタで造形できればよい**。量産金型工程は含まない |
| 納品段階 | 第一段階＝本ガイドライン文書そのもの。3D モデルは含まない |

**明示的な対象外**：電子部品のスペース配置、量産製造可能性（金型、射出成形、量産公差）、電気系とファームウェア、音量安全境界（Part 5.7 参照）。

## 0.3 使い方

1. まず Part 1 を読み、自社製品のシーン前提が本ガイドラインと一致するか確認する。一致しなければ以降のすべての数値を再評価する必要がある。
2. Part 2 に従いサイズ段階と性別基準を選ぶ。
3. Part 3 で荷重部品を配置禁止領域に置いていないか確認する。
4. Part 4 で幾何が設計可能領域内にあるか確認する——**横向き寝の境界が解剖学的境界に優先する**。
5. Part 5・6 で音響気室と構造材料を点検する。
6. Part 7・8 で快適性と CMF を点検する。
7. 最後に Part 9 のチェックリストを通す。

## 0.4 証拠等級（必須）

**すべての数値の後に出典等級を表示すること。未表示の数値は納品版に入れてはならない。**

| 表示 | 意味 | 信頼度 |
|---|---|---|
| 【実測】 | **測定データから直接抽出した統計量**（平均、パーセンタイル、主成分、フィッティング値）。いかなる物理モデルの成立にも依存しない | 最高 |
| 【文献】 | 検証可能な公開情報。DOI または到達可能なリンクを付す | 高 |
| **【計算】** | **物理モデル／式に代入して求めた値。入力の出所と仮定した定数をすべて開示すること** | **「モデルの適用可能性」と「入力の等級」のうち弱いほうを取る** |
| 【慣例】 | 業界の工学的慣例。単一の権威ある出典なし | 中 |
| 【推論】 | 当チームの推論であり、出典の直接の記述ではない | 中 |
| 【仮定】／【要確認】 | 根拠未取得。検証後に記入 | なし |

出典の種別も併記すること：**業界標準**（番号と版を示す）／**市場製品統計**（サンプルの出所を説明する）／**学術論文**（DOI または到達可能なリンクを示す）。

### 0.4a【計算】に付随する 2 つの規則

**① 入力の出所を明示する**：**【計算｜入力：実測】／【計算｜入力：定数】／【計算｜入力：混合】** と表記する。

**信頼度が入力だけで決まらない理由**：式そのものが適用できないアーキテクチャに当てはめられることがあり、その場合は入力がどれほど良くても救えない。実例——ヘルムホルツ共鳴の関係式を密閉型インイヤーに適用したことがあるが、密閉型に設計者が選べる調律周波数は存在しない。式も入力も正しく、**アーキテクチャの適用先が誤っていた**。ゆえに「モデルの適用可能性」を「入力の等級」と並置し、弱いほうを取る。

**② ⚠️ 判定基準は「モデル」を指すのか「物理量」を指すのかを明記すること。**

工学的な判定基準には 2 種類あり、混同すると完全に誤った結論を導く：

| 基準の性質 | 何に答えるか | 例 |
|---|---|---|
| **モデル適用性の基準** | どのモデルで計算すべきか | せん断波数 s≳10（粘性を無視できる）／kL ≪ 1（集中定数が成立） |
| **物理量のしきい値** | それで成立するのか | 肉厚 ≥1.0mm／PDT の圧力上限 |

> ⛔ **モデル適用性の基準から物理的な要求値を逆算してはならない。**「この値を下回るとモデルが綺麗でない」は「この値を下回ると成立しない」ではない。
> **実例**：s≳10 から「520 Hz には 1.36mm の開口が要る」と逆算し、密閉型は成立しないと推論したことがある。誤りは s がモデルの境界である点にある——s=3.7 の経路は伝わらないのではなく、**粘性損失を伴って伝わる**。損失量は別途計算を要する。当該推論は撤回済み。
> **したがって、この種の境界を書く際は必ずその性質を注記すること。**

### なぜここまで厳格にするか

**ガイドラインが誤っていれば、以降のすべての設計がその誤りに従う。** これは分析レポートとは異なる——レポートが誤っていれば 1 本の誤ったレポートで済むが、ガイドラインが誤っていれば製品ライン全体が誤った数値に従って進む。

したがって本プロジェクトの立場は：**【要確認】が多数残る正直な文書のほうが、数値で埋め尽くされ専門的に見えるが実は捏造された文書より望ましい。** 空欄は問い合わせを招くが、推測値は根拠として引き継がれてしまう。

実際の運用でこれに基づき数件を差し止めている。例：ある引用は原文を読んだのではなく検索要約から推定したものと確認されたため【慣例】に降格し関連数値を削除した。ある荷重関連の硬度値は独立した第 2 の出典が見つからず、相互検証待ちと明示した。

## 0.4b ⚠️ 3 種類の「サイズ」を混用してはならない——文字を共用しない

**本プロジェクトには互いに独立した 3 つの「サイズ」概念がある。過去に S／M／L の文字を共用したため複数回の誤読が生じた。よって以下のとおり明文化する。**

| 概念 | 名称と表示 | 何に答えるか | 誰が決めるか | データ源 |
|---|---|---|---|---|
| **本体バリエーション** | **機種 S／M／L**（`機種-M` と記す） | この機種の本体をどれだけ大きくするか | **製品判断**（ドライバ／バッテリ／機能トレードオフ） | 人間工学データでは決まらない |
| **アクセサリサイズ** | **イヤーチップ／イヤーウィング XS〜L**（`チップ-S` と記す） | この利用者にどのチップを合わせるか | その利用者の耳型に依る | 耳型区分で決まる |
| **耳型区分** | **耳型区分 I／II／III**（`区分-II` と記す） | この利用者の耳がどの区分か | **人間工学データ** | [Part 2](02-anthropometric-basis.md) |

> ⛔ **耳型区分には必ずローマ数字 I／II／III を用い、S／M／L の文字を使ってはならない。** 文字の共用が過去の誤読の根本原因である。

### 三者の関係

```
耳型区分（利用者の耳がどれだけ大きいか）
        ↓ 決める
アクセサリサイズ（どのイヤーチップ／ウィングを合わせるか）

機種バリエーション（本体をどれだけ大きくするか）← 独立に決定、機能トレードオフに依る
        ↑ 制約を受ける
解剖学的エンベロープ上限（Part 4）——すべての機種が超えてはならない
```

**機種バリエーションと耳型区分は直交する。** 業界標準の方式は**1 つの本体に複数のイヤーチップ**を組み合わせるものであり、本体サイズは製品ラインの話、耳の個人差はアクセサリが吸収する。

→ **したがって 3 つの機種（S／M／L）はそれぞれが耳型の全範囲を収容しなければならない。**「機種-L は大きい耳向け」ではない。

## 0.4c 欠落の処置規範——4 つを問うてから、その数値を追うかを決める

**数値が欠けているとき、反射的に「測る」か「実測待ちとして登録する」を選びがちだが、そのどちらも正しくないことが多い。** 欠落表が膨れる代償は、いま閉じられる項目が「実測待ち」に積まれ、本当に実測が要る項目が埋もれることである。

| 問い | 「はい」の場合 |
|---|---|
| ① ずれは**一方向**か？ | 事前補償または構造的除去で扱える可能性がある |
| ② 原因は**自分たちが設計で作り込んだもの**か？ | 設計で消せる——**補償より優先する** |
| ③ 大きさは**自分たちが制御する寸法に比例して変わる**か？ | 無関係なレベルまで抑えられる。方向だけ分かればよい |
| ④ 第三の類型なら：**無関係性の判定基準は何か。その入力は揃っているか** | 下記参照 |

**前 3 問のいずれかが「はい」→ まず設計を変える。その数値を追う必要はない。3 問とも「いいえ」→ そこで初めて実測が必須の欠落となる。**

### ⑤ その欠落は「待てば手に入る」のか「待っても来ない」のか——処置がまったく異なる

**欠落表が水増しになる最大の原因は項目数ではなく、本質の異なる 2 種類を同じ欄に混ぜることである。**

| 欠落の型 | 特徴 | 正しい処置 |
|---|---|---|
| **取得型（待てば手に入る）** | 数値は存在し、有料の壁の内側／費用がかかる／時間を確保すれば測れる | 登録＋取得経路とコストを明記。**待つことが有効な戦略** |
| **⛔ 定式化型（待っても来ない）** | **その測定が解釈可能な量を生まない**——定義が未凍結、トポロジーが未定、あるいは測っているものが問うているものと違う | **待っても無駄。** まず「この量は何を問うているのか」を解決しなければ、測っても使えない |

**実例の対比**：
- **取得型**：PDT の部位別絶対値（Yuan et al. 2023 は全文が有料の壁の内側）——支払うか購読を見つければ手に入る
- **定式化型**：耳甲介容積 → 筐体の利用可能総容積——**まだ測っていないのではなく、現有の点群では解釈可能な筐体容積が測れない**（名前付きランドマークがない、外耳道内部がない、基準面の定義がない）

> ⛔ **定式化型を取得型として登録すると、永久に「実測待ち」に掛かったまま、待っても来ないことに誰も気づかない。** これは欠落表の最も静かな失効である。

### ⑦ 欠落の登録形式——各項に「転換条件」と「アクション種別」を付す

「何が足りないか」だけでは不十分である。**別々に見える 2 つの欠落が同じ根を共有していることもあれば、どちらも何かが足りないように見えて、閉じるにはまったく異なるアクションを要することもある。** どちらも優先順位を誤らせる。

| 欄 | 内容 | ないとどうなるか |
|---|---|---|
| **転換条件** | 何が揃えばこの項が閉じるか（または定式化型から取得型へ変わるか） | 担当者をまたいで共有される根が見えない |
| **アクション種別** | **文献／ツール／収集／裁定** から該当するものを選ぶ | 1 つのアクションで 2 項が解けると思い込み、存在しないてこ点を探す |

**4 つのアクション種別**：

| 種別 | 意味 | 例 |
|---|---|---|
| **文献** | 文献または仕様を入手・照合する | PDT 絶対値（ジャーナル購読）／粘熱インピーダンス式の照合 |
| **ツール／能力** | 我々が持っていない能力を要する | 点群上での P1–P5 の確実な検出（**Zhu et al. が定義は与えている。足りないのは文献ではなく検出能力であり、論文が 10 本あっても動かない**） |
| **収集** | データ収集の設計をやり直す必要がある | 同一耳の反復測定によるノイズの独立推定（現有データでは補えない） |
| **⛔ 裁定** | **その経路は既存の決定によって閉じられている。再開に必要なのは資源ではなく、その決定を覆すことである** | 音響 FEM/BEM（task #4 で導入しないと裁定）／接触力シミュレーション（task #3 で投入しないと裁定） |

> ⛔ **「裁定」種別は開いた経路として書かれやすい。** 実例：多孔の端補正は「文献**または** BEM/FEM の数値解」と登録されており 2 本の並行経路があるように見えた——**しかし BEM/FEM は task #4 で既に閉じられており**、真の状態は「文献が当該区間を覆わなければ、開いた経路は存在しない」である。

### ⑧ 複数経路を持つ欠落は、経路ごとに状態を記す

**開いている経路だけを書くことと、未充足の入力の 1 つだけを書くことは、同じ失効の 2 方向である：**

| 誤り方 | 実例 |
|---|---|
| **未充足の入力を丸ごと落とす** | D-2-4 の条文は A_i ≥ F_i / PDT。「PDT 待ち」と登録されていたが、**それは F_i が既にあることを前提にしている——実際にはない**。正しい登録：PDT 待ち（文献）＋ F_i 待ち（収集。シミュレーション経路は裁定により閉鎖済） |
| **閉じた経路を開いたものとして書く** | 「文献または BEM/FEM」——後者は閉鎖済 |

### ⑨ 裁定の記録と欠落表は双方向に索引すること

**裁定は「何をしないか」に、欠落は「何が足りないか」に記録される。両表が相互参照しなければ、双方の読み手が反対側を見られない。**

- 欠落表の読み手は、その経路が閉じられていることを見られない → まだ通れると思う
- 裁定の読み手は、それがどの欠落のどの経路を閉じたか見られない → 自分の決定の帰結を知らない

**⇒ 各裁定にはそれが閉じた欠落と経路を明記し、各欠落の「裁定」種別の経路は当該裁定へ逆参照すること。**
（5.2-10／6A-2 の双方向の前提と同型——**片方向の記録は既定状態を取りこぼす**。）

### ⑩ 欠落にも二層分解を適用する。ただし「第一層＝文献」は一般則ではない

**第一層＝問題を明確に定義する／第二層＝数値を取得する。** 1 行に合成すると、**今すぐ動ける項目が他人待ちの項目として登録される**。

| 実例 | 第一層（隠れやすい） | 第二層 |
|---|---|---|
| F_i | **測定状態が未定義**（顎／熱／挿入深さ。代表値か分布か）——**今すぐ決められる。決めないまま試作機が届けば誤った状態で測ることになり、測らないより悪い。実測値に見えてしまうからである** | 試作機での測定 |
| メッシュ前容積の判定基準 | 判定基準の形式が未定 | メッシュの R ＋ 固定構造の実形状 |

> ⚠️ **「第一層は文献だけで済む」は成立しない。** 第一層は「問題を明確に定義する」ことであり、そのために何が要るかは、未定なのがどの種類かによる：
> **文献が足りない**（粘熱回路の形式）／**ツールが足りない**（点群のランドマーク検出——**表中で最も高コストの項目**）／**決定が 1 つ足りないだけ**（F_i の代表状態）／**上流の設計で止まっている**（トポロジー。固定方式の選定待ち）。

### ⑥ その数値は「能力量」か「結果量」か

同じ名前でもまったく異なる出所からくることがあり、信頼度と使える範囲が異なる：

| 型 | 何に答えるか | 使える範囲 |
|---|---|---|
| **能力量**（解剖学的測定） | **耳がどれだけ収容できるか** | サイズ区分（S／M／L）とカバー率の根拠にできる |
| **結果量**（市場製品統計） | **すでに誰かが達成し、市場に受け入れられた水準** | **上界の参考にのみ使える。サイズ区分の根拠にはできない** |

**理由**：結果量はどのパーセンタイルを覆っているかを教えない。市販製品の体積は中央値以上の人にしか合っていない可能性があり、**データ自体からはそれが見えない**。
**実例**：市販の睡眠用イヤホン本体の体積を測れば「実際に収まり、かつ売れている」経験的上界が得られ、**解剖学的ランドマークを一切必要としない**——ランドマーク欠落を迂回する有効な経路だが、**得られるのは上界であってサイズ区分の根拠ではない**。

### ⛔ 第 4 問が要であり、これを欠くと第 2・第 3 の類型が抜け穴になる

「最小化した」「できるだけ近づけた」は**形容詞であり、本ガイドラインが禁じている「肉厚は十分であること」と同類である。** 設計者が「やった」と宣言すれば通ってしまい、**欠落として登録するよりも悪い——閉じたように見えるからである。**

> **寄生要素には「無関係性の判定基準」（通常は主要素との無次元比）を与え、設計が安全側にあることを示すこと。「最小化した」という宣言だけでは閉じたことにならない。**

**「書けること」と「検証できること」は分ける**：未知量を含む不等式として書かれた基準も**判定可能な条文である**。評価の時点が後になるだけである。**両方とも「いいえ」のときのみ欠落表に残す。**

### 3 類型の実例（本案件より）

| 欠落 | ずれの性質 | 処置 | 大きさの数値は要るか |
|---|---|---|---|
| 固定工程による音響抵抗の上昇 | 一方向。原因は設計で消せる物理経路（接着剤の毛細浸透） | **構造的除去**（機械挟持。接着剤を音響面に触れさせない） | **不要** |
| 寄生容積 | 大きさが制御可能な寸法に比例 | **無関係なレベルまで抑える**——ただし判定基準が必須。「最小化」だけでは不可 | **不要**（方向＋基準のみ） |
| 皮膚温での硬度シフト | **双方向**（快適性には有利、保持には不利）。原因は我々の制御外 | **実測するほかない** | **必要** |

> ⚠️ **しきい値が「選んだ値」なら、選定値として明記すること。** 例：「寄生容積は主容積の 10% 以下」——**これは工学的な選択であって物理定数ではない。** 選定理由を添える。明記しなければ、次の読者は根拠のある数値だと受け取る。

## 0.5 用語規範

耳の部位名と医学用語は必ず**日本語を先に、英語を括弧内に**記す。例：耳珠（tragus）、耳甲介腔（cavum conchae）、迷走神経耳介枝（auricular branch of vagus nerve, ABVN）。初出時に正式名称と略称を示し、以降は日本語のみでよい。

純粋な音響・物理用語（Helmholtz 共振器、粘性境界層など）にはこの規範を適用しない。

**日本語版固有の注意**：中国語版の解剖学用語をそのまま漢字流用してはならない。日中で正式名称が異なる語が多い（耳屏→耳珠、耳廓→耳介、耳甲腔→耳甲介腔 など）。対照は [TERMS.md](TERMS.md) を参照。

## 0.6 既知の能力限界（本文に明記し、注記に隠さない）

当チームには現有ツールで検証できない項目が 2 つある。設計者はこれを知っておく必要がある。さもないと本ガイドラインの推奨がシミュレーション検証済みだと誤解しかねない：

| 項目 | 状況 | 帰結 |
|---|---|---|
| **装着圧と快適性** | 超弾性（hyperelastic）材料モデルと接触（contact）ソルバがない。加えて耳の軟組織の材料パラメータに検証可能な出典がない | イヤーチップが外耳道組織を圧迫する実際の圧力をシミュレーションできない。**実機装着試験による検証が必須** |
| **音響の高周波特性** | 波動 FEM/BEM ソルバがなく、集中定数（lumped-element）モデルのみ | 周波数上限がある（Part 5.5 参照）。上限を超える領域は実測に頼るほかない |

**本ガイドラインが提供するのは工学的根拠のある設計の出発点であり、検証済みの実現可能な製品ではない。**

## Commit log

2026-08-21 Add guideline scaffold and Parts 3-4
    Part 3 (sensitive zones) and Part 4 (max design envelope) answer the two
    questions raised by @showmin-wang.
    Part 3 separates three independent evidence types (neuroanatomy, pressure
    discomfort threshold, mechanically-evoked reflex) and explicitly blocks the
    unsupported extrapolation from taVNS electrical-stimulation findings to
    passive mechanical pressure.
    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
2026-08-21 Add Parts 5-6 after PM review
    Part 5 (acoustics, Chuchu-Acoustic): viscous boundary layer values and the
    lumped-model validity table were independently recomputed and match. One
    citation was downgraded to convention after the author confirmed it was
    inferred from a search snippet rather than read; the associated frequency
    figures were dropped since they do not change any design action.
    Part 6 (structure/materials, Pareo-MechEE): scoped to 3D-printability only.
    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
2026-08-21 Apply Chinese-then-English term convention to anatomical and medical terms
    Per @showmin-wang: ear anatomy and medical terms are written in Chinese with
    the English in parentheses, e.g. 耳屏（tragus）. Retrofitted Parts 3, 4 and 6
    and recorded the rule in the README so later chapters follow it.
2026-08-21 Add Parts 0, 1, 7, 8, 9 - all chapters drafted except Part 2
    Part 1 is grounded in De Koninck 1992 polysomnography data: position shifts
    drop from 3.6/hr at 18-24 to 2.1/hr at 65-80, with >30min immobility periods
    increasing. Since insomnia skews older, the governing load case is sustained
    static pressure, not peak pressure. The same study finds a marked right-side
    preference in the elderly, so the right ear carries more cumulative load and
    should be weighted in wear testing.
    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
2026-08-21 Restructure the side-sleep bound per form-factor family
    Committed to this after @showmin-wang asked how an ear-hook design would be
    judged. The original bound measured protrusion from the concha plane, which
    only holds for in-ear.
    Adds per-family criteria and failure modes. Ear-hook is the notable case:
    the rear body sits on the mastoid where bone is directly under thin skin,
    the hook acts as a lever that can fold the pinna, and the device can push
    the pinna away from the head so the ear itself becomes the protrusion.
    Also records that transmitted contact pressure, not protrusion height, is
    the actual physical quantity - height is a proxy that works well for in-ear
    and poorly elsewhere.
    E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
2026-08-21 Add Part 2 with measured outer-envelope data from AudioEar3D
    First chapter content graded as measurement rather than literature. PCA
    principal axes over 112 ear point clouds, aggregated per person (n=56)
    since left and right ears are not independent.
    Axis-aligned bounding boxes were rejected: sampling showed PCA long axes
    deviate from +Y by up to 29 degrees, which would understate length by ~13%
    in the worst case without erroring. A stray unaligned file in the archive
    provided free confirmation that PCA range is orientation-invariant.
    Two misuse risks are called out explicitly. PC3 thickness measures the
    auricle's own curl depth and is not side-sleep protrusion, which this data
    cannot yiel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
2026-08-21 Add sex-stratified Chinese concha morphometry to Part 2
    Zhu et al. 2017, 310 Chinese adults aged 18-28, twelve concha measurements
    split by sex and side. This partially closes two gaps flagged earlier: it
    supplies an Asian baseline and a male/female split, though only for the
    concha region and only for young adults.
    Adopts the paper's published P1-P5 landmark system rather than inventing
    definitions, which also gives route B a citable basis and an external
    validation target.
    Flags one source error: HECO right-female SD is printed as 7.14 against a
    mean of 9.71. All 43 other linear SDs fall in 0.58-1.53, and a normal
    distribution with that SD would put 8.7% of ear canal opening heights belo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
2026-08-21 Define front-cavity boundary by sealing type in Part 5.1
    For a sealed in-ear design the concha lies outside the seal and open to
    atmosphere, so it does not bound V_front - the ear canal does. Only in a
    non-sealing earbud does concha volume enter the model, and there it acts as
    a coupling cavity plus leak path rather than a sealed front volume.
    Adds an explicit guard against converting the Part 2.3 concha linear
    dimensions into a front-cavity volume, which would stack a shape assumption
    and an age extrapolation onto literature values while carrying a literature
    tag.
2026-08-21 Convert data gaps from pending items into stated boundaries with workarounds
    @showmin-wang confirmed no further data is available, so these gaps are
    permanent limits of the deliverable rather than items awaiting input. That
    distinction matters to a reader: pending implies it will be filled later.
    Each limit now carries a workaround rather than just a statement of absence.
    Sex split is replaced by covering the full P5-P95 range, since the sample
    contains both sexes unlabelled and therefore already spans them. The age
    shortfall is handled by upper-end margin plus a checklist requirement that
    wear testing include older subjects - closed by testing, not by numbers.
    Ear-hook is marked a high-ris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
2026-08-21 Add measured concha depth and its reliability limit
    CD measured on all 112 ears via a rim-fitted plane, documented as an
    approximation of the published P1P3P5 datum rather than the same quantity.
    The reported left-right correlation of 0.437 turns out to be the
    measurement's reliability coefficient. Decomposing left and right as one
    true value plus independent noise gives per-ear noise sd 0.70mm against
    true between-person sd 0.62mm, and predicts corr 0.436 against the observed
    0.437. So roughly 56% of single-measurement variance is noise, and noise
    slightly exceeds real anatomical spread.
    Consequence recorded prominently: the mean is sound because noise averages
    out over 56 subjects, but p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
2026-08-21 Record that low-tail exclusion was tested and rejected
    Excluding the five lowest concha depths produced statistics matching the
    noise decomposition almost exactly, which was tempting. It does not hold up.
    Applying the same visual standard to the highest five and a mid-range five
    found the annulus-scale defect at comparable rates throughout, so it is a
    general method limitation rather than something specific to the low tail.
    The proposed mechanism was also falsified: the five lowest ears average
    65.1mm PC1 against a population mean of 66.6mm, and PC1 correlates with CD
    at only 0.29, so low depth is not driven by small ears. And trimming one
    tail of any distribution lowers the standard deviat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
2026-08-21 Adopt relative-radius concha depth and test its scale-dependent bias
    All three pre-registered criteria improved: std(L-R) 0.99->0.96,
    corr(L,R) 0.437->0.552, per-ear noise 0.70->0.68mm. Noise share of a single
    measurement falls from 56% to 46% - reduced, not eliminated.
    Records a blind spot in that criterion set: it estimates noise from
    left-right differences, so any bias shared between a person's two ears is
    invisible to it. The new annulus scales on PC1, which is near-identical
    across a person's ears, so a size-dependent bias would hide there.
    Tested it rather than leaving it as "cannot distinguish". Correlation
    between CD and overall ear size rose 0.29 to 0.54, which exceeds what the
    re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
2026-08-21 Add seated-sleep scenario and split form-factor ranking by scenario
    @showmin-wang added a seated use case - office naps and transit - where
    side-sleep compression does not apply. That removes the guideline's largest
    unmeasurable gap, but substitutes a different constraint set rather than a
    smaller one: retention becomes the dominant constraint since a nodding head
    can shed the device, appearance matters in public, transit noise is
    low-frequency, and full isolation becomes a hazard when announcements must
    be heard.
    Most consequentially it inverts the form-factor ranking. Ear-hook was the
    worst option under side-sleep solely because the rear body is compressed
    against the mastoid; seated use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
2026-08-22 Add per-posture analysis for supine, lateral and seated sleep
    Each posture binds a different parameter, so "designed for sleep" without a
    stated posture does not specify a constraint. Supine is governed by ear
    canal deformation, lateral by protrusion and transmitted pressure, seated by
    retention.
    The supine finding is new to this project. Lying on the back lets the jaw
    slacken open, and the temporomandibular joint abuts the anterior canal wall,
    so the canal deforms. Darkner et al. found significant deformation at the
    tragus and in the canal in all 30 subjects; Oliveira et al. measured about
    25% anterior-posterior change, though in a single subject. A sealed in-ear
    fit set with the mouth clo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
2026-08-24 Add GUIDELINE.md - the rules, separated from the evidence
    @showmin-wang read Part 1 and still could not tell what the guideline says.
    Checking the whole document confirms the problem is real and general: every
    chapter carries more caveat lines than numeric thresholds, and Part 4 - the
    design envelope chapter - runs 2 thresholds against 19 caveats. Part 1 has
    14 caveats and no thresholds at all.
    The evidence discipline was right but it buried the output. A reader wanting
    to know what to build had to mine it out of methodology and limitations.
    GUIDELINE.md states the rules only - size envelope, no-go zones, envelope
    method, form-factor selection, acoustic geometry, print thresholds, CMF
    limi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
2026-08-24 Document the concha-depth definition trap
    @showmin-wang found web sources giving 14-17mm concha depth against our
    9.15mm and asked whether our measurement is wrong.
    Two independent measurements put it at 9-10mm: ours, and Zhu et al. on 310
    Chinese adults using ear impressions rather than point clouds. Published
    concha depth spans 9-16.8mm across studies, and that spread is attributed to
    differing measurement methods, many of them unstated. The likely cause of a
    14-17mm figure is either a datum at the helix rather than the concha rim -
    which adds the antihelix wall height - or concha diameter, typically
    15-20mm, which overlaps that range closely.
    Recorded honestly that our value sits at the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
2026-08-24 Adopt three field tests from a market source; reject its dimensions
    @showmin-wang supplied a consumer buying guide for Soundcore Liberty 3 Pro.
    Its numbers are unusable as anatomy but its validation procedure fills a
    real gap - Part 7 previously had the principle "must be physically tried on"
    with no decidable threshold.
    Adopted: head-shake for retention, chew/mouth-open for tragus pain, and the
    15-minute rule, whose framing that persistent pressure signals wrong size
    rather than a break-in period is directly usable as an acceptance criterion.
    Also the point that fit angle matters independently of size, which connects
    to the established left-right asymmetry of angular ear dimensions.
    Notab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
2026-08-24 Separate three distinct size concepts; stop reusing S/M/L letters
    @showmin-wang corrected me twice on this, and I conflated it again in the
    market-source section: I linked the Taobao ear-size bands to "the S/M/L
    discussion". Root cause is that one set of letters was carrying two
    meanings, so restating the definition would not have prevented a third slip.
    There are actually three concepts, now each with its own label scheme:
    device variant (機型 S/M/L), accessory size (耳塞 XS-L), and ear size band
    (耳型分段 I/II/III, Roman numerals so no letters are shared).
    Device variant and ear band are orthogonal - the industry pattern is one
    body with several eartips, so ear variation is absor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
2026-08-24 Record that ear dimensions do not predict comfort; add seal self-test
    Fu & Luximon 2022 (Applied Ergonomics 100:103640, n=30) finds ear symmetry,
    sex, concha length and cavum concha width all correlate insignificantly or
    weakly with perceived comfort and fit, while use condition and product size
    do matter. That reframes what Part 2 is for: its data excludes geometrically
    infeasible designs, it does not select comfortable ones.
    Noted the statistical caveat the source critique omitted - at n=30,
    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
2026-08-24 Flag conflicting secondary accounts of the Zhu/Ji landmark and cluster counts
    A secondary source describes the 310-subject Chinese concha study as using 5
    landmarks, 7 distances and 24 clusters. The primary text this guideline
    cites gives 7 landmarks and 12 measurements, and a separate search result
    attributes 27 clusters to Ji et al. 2018. The three accounts do not
    reconcile, likely conflating related papers on the same sample.
    Part 2.3 keeps only what the primary abstract supports and records the
    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
2026-08-24 Verify Sony's fit test; contrast pass/fail against comparative protocols
    @showmin-wang supplied the Sony source. The Taiwan URL returns 403 here, but
    the same article number on the HK site and Sony's official help guide
    confirm it: the Headphones Connect app has users fit each tip size in turn,
    measures air-tightness in a quiet place while still, and reports which size
    fits best.
    Two independent vendors now support the claim that industry verifies fit by
    measuring the acoustic outcome rather than ear geometry, which makes it a
    practice rather than one company's feature.
    The protocols differ in a way that matters. Apple returns pass/fail on the
    tip currently worn; Sony ranks sizes. Only the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
2026-08-25 guideline: Part 章節改為可點連結，中日文各自指向 cn/ 與 jp/
2026-08-25 docs: 移除人名、頻道與維護者等與主題無關的資訊
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2026-08-25 GOAL: 更正被動通氣孔非無條件 fail-safe
2026-08-25 ACCEPTANCE: 新增 F7 交叉檢查、更新盤點（第 21 項電源預算）
2026-08-25 ACCEPTANCE: 標明 F7 覆蓋邊界（跨界錯 vs 領域內錯）
2026-08-25 整合 Part 5/6 修訂：【計算】等級、孔徑與列印方向、接觸壓力判準、隔音三條件、電源預算缺口
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2026-08-25 Part 9 條目化：Part 5/6 條文層檢查、六個閘門、三態標記
2026-08-25 坐睡確定移出第一階段：全篇標範圍外、形態排序改寫；修正 Part 9 條目編號衝突
2026-08-25 Part 9: ◆ 形式約束標記（與 ⚑ 閘門正交）、新增 P9-A 頻帶形式要求
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2026-08-27 Part 2: CD 年齡免除改為條件式（定義不同未核實）；PC3 不作為左右對稱第三方證據
2026-08-27 Part 0.4c 加缺口兩型與能力量/結果量；Part 9.0 公告觸發擴到「搬運結論」
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2026-08-27 5.3 熱與鬆弛不獨立（時間起算綁熱平衡）；合併量測改為依序量並新增 5.3-7 記錄順序間隔
2026-08-27 5.3 窄縫 s 須代半高；縫高不均勻性非係數（無上界、雙峰）；缺口改標為問錯問題
2026-08-28 feat(004): add custom sleep earphone models v1, v2, v3 and 1:1 references
    [004_canal_entrance.stl, 004_concha_basin.stl, 004_human_ear_right_solid.stl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]
2026-08-28 feat(004): regenerate sleep earphones with distinct brand styling and multi-material rigid/soft separation
    [004_v1_rigid_chassis_hollow.stl, 004_v1_rigid_chassis_solid.stl, 004_v1_sleep_earphone_colored.ply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]
2026-08-28 feat(004): add raw concave ear model to FCStd projects and reference_ear
    [004_human_ear_right_raw_concave.stl, 004_v1_sleep_earphone_in_ear_simulation.FCStd, 004_v2_sleep_earphone_in_ear_simulation.FCStd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]
2026-08-28 feat(004): add negative mold box to reference_ear
    [004_ear_negative_mold_box.stl]
2026-08-28 feat(004): add real human ear anatomy model and update FCStd simulation projects
    [004_real_human_ear_anatomy.stl, 004_real_human_ear_colored.ply, 004_v1_sleep_earphone_in_ear_simulation.FCStd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]
2026-08-28 fix(004): remove artificial Poisson concha bridge faces to expose clean open natural concha and canal cavity
    [004_real_human_ear_anatomy.stl, 004_real_human_ear_colored.ply, 004_v1_sleep_earphone_in_ear_simulation.FCStd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]
2026-08-28 refactor(004): clean up 004 directory to keep only raw original files and move all generated deliverables to output/
    [004_canal_entrance.stl, 004_concha_basin.stl, 004_ear_negative_mold_box.stl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]
2026-08-28 feat(004): add commercial reference earphone models to output/product with sources README
    [airpods_pro_body.stl, airpods_pro_eartip.stl, airpods_pro_in_ear.FCStd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]
2026-08-28 fix(004): rebuild all 3 commercial earphone models with strict dimensional accuracy (0% error vs official specs)
    [airpods_pro_body.stl, airpods_pro_eartip.stl, airpods_pro_in_ear.FCStd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]
2026-08-28 feat(src): add --cut-depth option to force open cavity on irregular surfaces
2026-08-28 feat(src): add advanced auto_extrude_verse.py that implements automated core extension logic for zero-loss ear mold generation
